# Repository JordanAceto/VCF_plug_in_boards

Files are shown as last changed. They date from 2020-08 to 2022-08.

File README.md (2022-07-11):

# Various Voltage Controlled Filter pcbs

- #### These small VCF "plug-in" boards each contain a filter "core". These are intended to be plugged into a motherboard which provides a +/- 12 volt power supply, input/output circuitry, and control voltage sources.
- #### They all share an identical mechanical and electrical format.
- #### The intended use is to make a bunch of different filters and then be able to easily try them out by swapping the filter plug-in boards into the motherboard.

## The mechanical format and pinout shared by all plug-in boards:
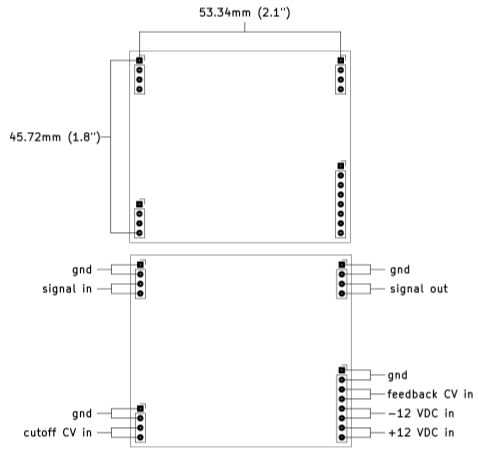
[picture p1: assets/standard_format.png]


## Signal levels:
- #### The plug-in boards are expecting modular synthesizer level signals of around +/- 5 volts.
- #### Many filters have interesting resonance and distortion characteristics that depend on signal level. Experiment with increasing and decreasing the signal levels to find the sweet spots.
- #### The output signal may or may not be in phase with the input signal.

## CV signals:
- #### The motherboard is expected to provide a 0 to +2.048 volt cutoff frequency CV signal. The plug-in boards are designed to sweep through their entire range with this range, with 0 volts mapping to the lowest cutoff frequency (usually around 20Hz) and +2.048 volts mapping to the highest cutoff frequency (usually around 20kHz).
- #### The feedback CV from the motherboard uses the same range: 0 volts of feedback CV maps to "no feedback" and +2.048 volts of feedback CV maps to maximum feedback.
- #### The CV range of 0 to +2.048 volts was chosen becuase it allows the cutoff and feedback CV signals to be conveniently driven directly from a cheap MCP4822 DAC. Don't worry about an exact 2.048 volt range, the filters have trimmers to account for variations.
- #### If different scalings are desired it is usually fairly trivial to change some resistor values in the CV scaling circuits on the plug-in boards.

## Feedback considerations:
- #### The plug-in boards all have voltage controlled feedback. This makes it easier to swap them in and out of a motherboard without worrying about the type and value of feedback potentiometer.
- #### This also makes it easier to apply "Q-compensation" to 4-pole low pass filters that suffer from passband attenuation when feedback is increased.
- #### All 4-pole filters have some form of Q-compensation built in. The builder can usually adjust the amount of compensation, or choose no compensation at all by changing a single resistor.

## Calibration:
- #### Each plug-in board has calibration trimpots for modulation depth, center frequency, and feedback sensitivity.
- #### For filters that can track at 1 volt per octave, they can probably be trimmed to play in tune over a limited range, but the trimming may be fiddly. Emphasis has been placed on getting a nice sweep through the filters useful range, and not accurate tuning or temperature compensation.
- #### Calibration is a matter of taste, and any setup that sounds good to you is correct.
- #### Here is how I calibrate Low Pass Filters:
    1. Inject a 30Hz square wave onto the signal input while monitoring the signal output.
    2. Turn the cutoff CV and feedback CV signals all the way down (set them to zero volts).
    3. Adjust the **center** trim so that the signal just dissapears.
    4. Remove the signal input.
    5. Turn the cutoff CV to around 1/2 way up and turn the feedback CV all the way up.
    6. Adjust the **feedback** trim until self oscillation occurs.
    7. Turn the cutoff CV signal all the way up.
    8. Adjust the **depth** trim until the frequency of the self oscillation is around 20kHz.
    9. Sweep the cutoff frequency up and down and readjust the **feedback** trim as needed to get reliable self oscillation over the desired range. Note that some filters will not self oscillate over their whole frequency range.
    10. Now reinject the signal and listen to the filter while changing the cutoff and feedack CV signals. Readjust the trimmers to taste if desired.

- #### I use a similar strategy for other filter topologies like Phase Shifters. Without a self oscillation signal or a strong sense of "cutoff frequency", just adjust the trimmers so that the filter has a nice sweep and the feedback control feels good.
- #### The above calibration strategy is very quick and easy once you've done it a few times.

## Power supply considerations:
- #### The motherboard is expected to provide a +/-12 volt DC power supply.
- #### Current draw varies across the filter boards from a handfull of milliamps to a few 10's of milliamps.
- #### Ensure that the motherboard can supply at least 100mA or so on each rail.

## Starting new plug-in board pcbs:
- #### A template is provided to make it easy to start new plug-in board filters.
- #### This template contains a standard directory structure, and the start of a kicad project.
- #### The template kicad docs have the skeleton of the schematic and pcb.

## Project structure:
- #### Each filter plug-in board subdirectory follows a consistent structure:
    - #### `kicad_docs/` contains the files needed to open and edit the filter schematic and pcb layout using kicad.
    - #### `construction_docs/` contains a pdf copy of the schematic, an interactive BOM which can be opened in a web browser, and gerbers.
    - #### `pics/` contains a few rendered pics of the pcb.
- #### Basically, if you want to edit the filter go into `kicad_docs/`, if you want to build the filter go into `construction_docs/`.
- #### Note that the filters may be a work in progress and may not contain complete documentation until they are done.
- #### See the board status checklist below, any board that is not checked all the way across is likely to contain errors. Boards that are all checked all the way across are safe to build.

## Status of the boards:

Board | breadboarded | schematic | pcb layout | built and tested | documentation
------|--------------|-----------|------------|------------------|---------------
[2164 phasor](https://github.com/JordanAceto/VCF_plug_in_boards/tree/master/2164_phasor_plug_in_board)       | &#9745; | &#9745; | &#9745; | &#9745; | &#9745;
[2164 LPF](https://github.com/JordanAceto/VCF_plug_in_boards/tree/master/2164_4_pole_LPF_plug_in_board)       | &#9745; | &#9745; | &#9745; | &#9745; | &#9745;
[2164 SVF](https://github.com/JordanAceto/VCF_plug_in_boards/tree/master/2164_SVF_plug_in_board)       | &#9745; | &#9745; | &#9745; | &#9745; | &#9745;
[arp 4072 LPF](https://github.com/JordanAceto/VCF_plug_in_boards/tree/master/arp_4072_LPF_plug_in_board)      | &#9745; | &#9745; | &#9745; | &#9745; | &#9745;
[CEM3320 LPF](https://github.com/JordanAceto/VCF_plug_in_boards/tree/master/CEM3320_LPF_plug_in_board)       | &#9745; | &#9745; | &#9745; | &#9745; | &#9745;
[haible 2040 LPF](https://github.com/JordanAceto/VCF_plug_in_boards/tree/master/haible_2040_LPF_plug_in_board)   | &#9745; | &#9744; | &#9744; | &#9744; | &#9744;
[haible tau phasor](https://github.com/JordanAceto/VCF_plug_in_boards/tree/master/haible_tau_phaser_plug_in_board/kicad_docs) | &#9744; | &#9744; | &#9744; | &#9744; | &#9744;
[Late MS20 VCF](https://github.com/JordanAceto/VCF_plug_in_boards/tree/master/late_MS20_VCF_plug_in_board)       | &#9745; | &#9745; | &#9745; | &#9745; | &#9745;
[minimoog LPF](https://github.com/JordanAceto/VCF_plug_in_boards/tree/master/minimoog_LPF_plug_in_board)      | &#9745; | &#9745; | &#9745; | &#9745; | &#9745;
[mutron 3 SVF](https://github.com/JordanAceto/VCF_plug_in_boards/tree/master/mutron_III_plug_in_board)      | &#9745; | &#9745; | &#9745; | &#9745; | &#9745;
[optical phasor](https://github.com/JordanAceto/VCF_plug_in_boards/tree/master/optical_phasor_plug_in_board)    | &#9745; | &#9745; | &#9745; | &#9745; | &#9745;
[SSI2140 LPF](https://github.com/JordanAceto/VCF_plug_in_boards/tree/master/SSI2140_LPF_plug_in_board) | &#9745; | &#9745; | &#9745; | &#9745; | &#9745;

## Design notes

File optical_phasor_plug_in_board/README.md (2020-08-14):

# Optical Phasor Plug-In Board

Small 6 stage optical phase shifter PCB, designed to plug into a larger motherboard.

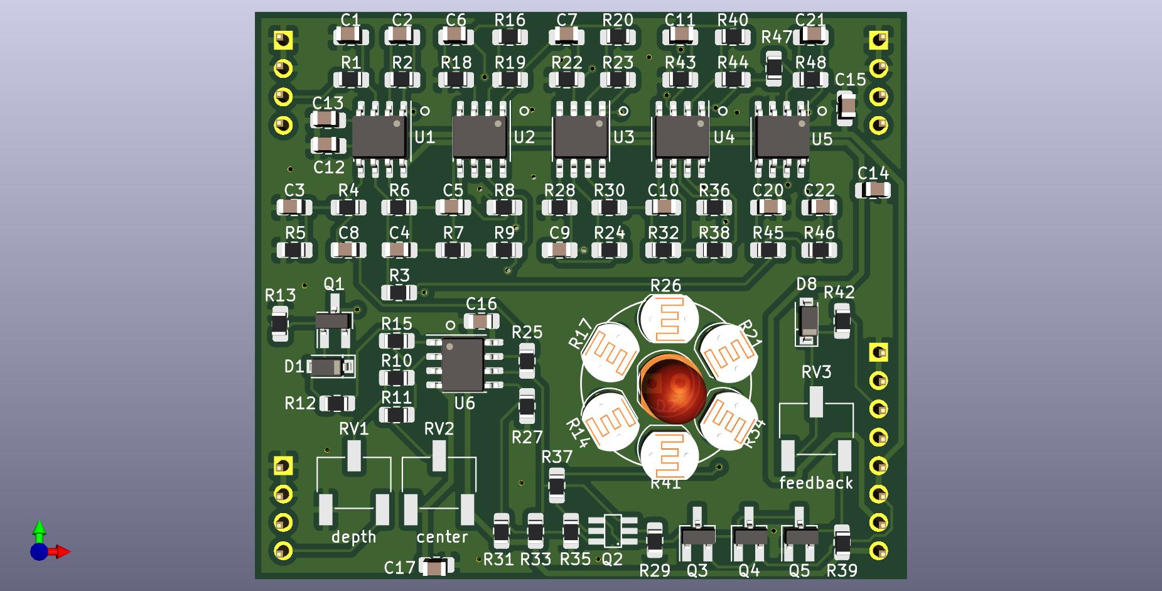
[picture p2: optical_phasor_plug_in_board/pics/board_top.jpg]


## Details

The main circuit is based on the famous Mutron phasor circuit with the addition of voltage controlled feedback. This PCB includes the audio path and CV inputs for frequency and feedback, but does not include any modulation sources.

The intended use for this board is to plug in to a larger motherboard which contains slots for one or more of these phasor boards, as well as modulation sources, panel controls, and input/output routing.

## Inputs

-Audio in: dry audio input to be phase shifted.

-Frequency CV in: 0 volts to +2.048 volts, higher voltage = higher sweep.

-Feedback CV in: 0 volts to +2.048 volts, higher voltage = more feedback.

## Outputs

-Audio out: phase shifted audio output.

## Power Supply Requirements

A bipolar 12 volt power supply capable of supplying 50mA is needed. This will typically come from the motherboard.

## Note About The Light Dependent Resistors

Low on resistance and high off resistance are desirable if a wide sweep range is wanted. Slow/fast response is up to personal taste.

The choice of LED has a large impact on sweep depth. Diffused green LEDs were found to produce good results, but feel free to experiment.

The LED and surrounding LDRs should be protected from ambient light under an opaque cover.

## Calibration

- See the top level README for calibration instructions.

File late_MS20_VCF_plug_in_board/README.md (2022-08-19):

# Late MS20 style VCF Plug-In Board

Small MS20 based low pass/high pass filter PCB, designed to plug into a larger motherboard.

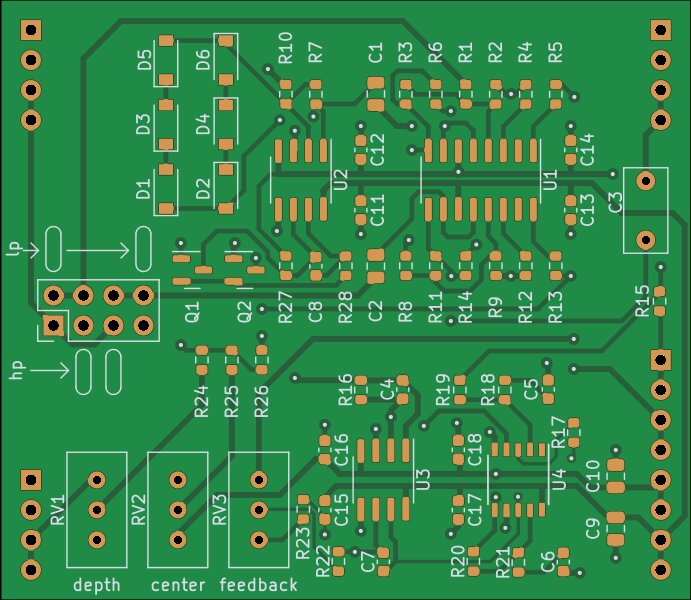
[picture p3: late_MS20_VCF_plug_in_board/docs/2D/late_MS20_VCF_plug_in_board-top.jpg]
pcb front


## Details

MS20 based LPF/HPF with voltage controlled feedback. This PCB includes the audio path and CV inputs for frequency and feedback, but does not include any modulation sources.

The intended use for this board is to plug in to a larger motherboard which contains slots for one or more of these plug-in boards, as well as modulation sources, panel controls, and input/output routing.

High pass or Low pass mode is selected by placing two jumpers as indicated on the silkscreen.

## Inputs

-Audio in: dry audio input to be filtered.

-Frequency CV in: 0 volts to +2.048 volts, higher voltage = higher sweep.

-Feedback CV in: 0 volts to +2.048 volts, higher voltage = more feedback.

## Outputs

-Audio out: filtered audio output.

## Filter mode selection

- This filter has two filter modes available: Low Pass and High Pass.

- One mode at a time can be selected by placing two jumpers according to the silkscreen.

## Power Supply Requirements

A bipolar 12 volt power supply is required. This will typically come from the motherboard.

## Calibration

- See the top level README for calibration instructions.

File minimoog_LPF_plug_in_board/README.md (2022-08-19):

# Minimoog VCF Plug-In Board

Small Minimoog based low pass filter PCB, designed to plug into a larger motherboard.

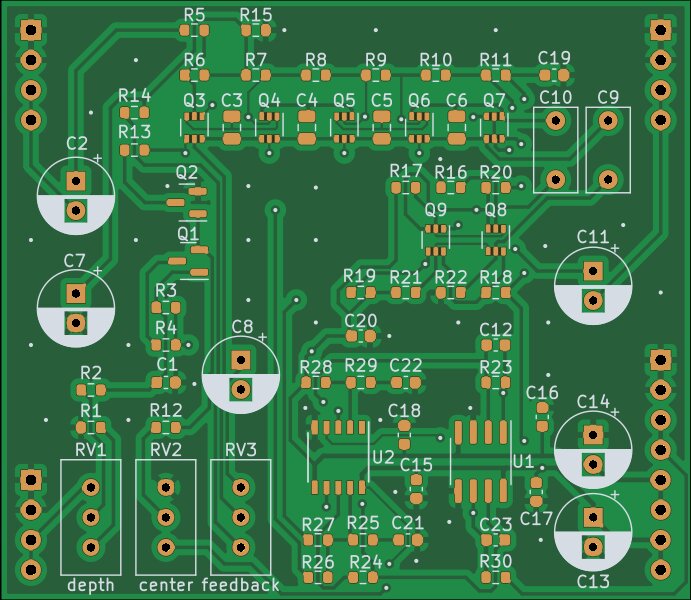
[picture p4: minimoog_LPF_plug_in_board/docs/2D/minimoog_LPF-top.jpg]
pcb front


## Details

Minimoog based LPF with Q compensation. This PCB includes the audio path and CV inputs for frequency and feedback, but does not include any modulation sources.

The intended use for this board is to plug in to a larger motherboard which contains slots for one or more of these plug-in boards, as well as modulation sources, panel controls, and input/output routing.

The Q compensation circuit keeps the passband gain from dropping too much when feedback is increased as typically happens with this type of filter. This is a matter of taste. The amount of compensation is set by R28. R28 can be increased to reduce the amount of compensation, resulting in lower passband gain at high feedback settings if a more traditional response is desired.

## Inputs

-Audio in: dry audio input to be filtered.

-Frequency CV in: 0 volts to +2.048 volts, higher voltage = higher sweep.

-Feedback CV in: 0 volts to +2.048 volts, higher voltage = more feedback.

## Outputs

-Audio out: filtered audio output.

## Power Supply Requirements

A bipolar 12 volt power supply is required. This will typically come from the motherboard.

## Calibration

- See the top level README for calibration instructions.

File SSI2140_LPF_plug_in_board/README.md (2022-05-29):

## SSI2140 4-pole Low Pass Filter plug-in board

Small SSI2140 based low pass filter PCB, designed to plug into a larger motherboard.

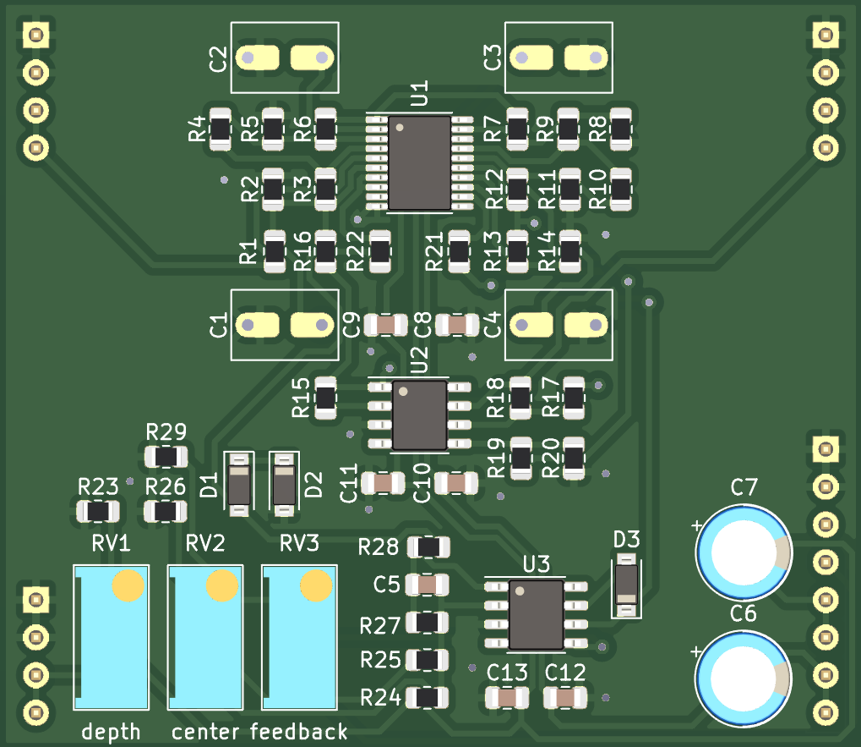
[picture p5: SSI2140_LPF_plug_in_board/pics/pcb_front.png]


## Details

Basic datasheet implementation of the SSI2140 lowpass filter with "Output Gain" Q Compensation.

## Inputs

-Audio in: dry audio input to be filtered.

-Frequency CV in: 0 volts to +2.048 volts, higher voltage = higher sweep.

-Feedback CV in: 0 volts to +2.048 volts, higher voltage = more feedback.

## Outputs

-Audio out: filtered audio output.

## Power Supply Requirements

A bipolar 12 volt power supply is required. This will typically come from the motherboard.

## Calibration

-RV1 (depth trim): trims the depth of incoming frequency CV signals. Turn CW for greater depth and CCW for less depth. Adjust to taste.

-RV2 (center trim): trims the center frequency of the filter. Turn CW for higher center frequency and CCW for lower center frequency. Adjust to taste.

-RV3 (feedback trim): trims the maximum amount of feedback. Turn CW for more maximum feedback and CCW for less maximum feedback. Exercise caution when adjusting this, as extreme settings can result in loud oscillations which could damage your ears or speakers if you are monitoring the sound with a loud amplifier. If you set this trimmer to be right on the edge of oscillation when about +2 volts is applied to the feedback CV input then make sure to sweep the frequency through its entire range, as a setting that doesn't squeal at certain frequency settings may squeal at other settings.

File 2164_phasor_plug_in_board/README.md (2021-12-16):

# 2164 Phasor Plug-In Board

Small 6 stage SSM2164 based phase shifter PCB, designed to plug into a larger motherboard.

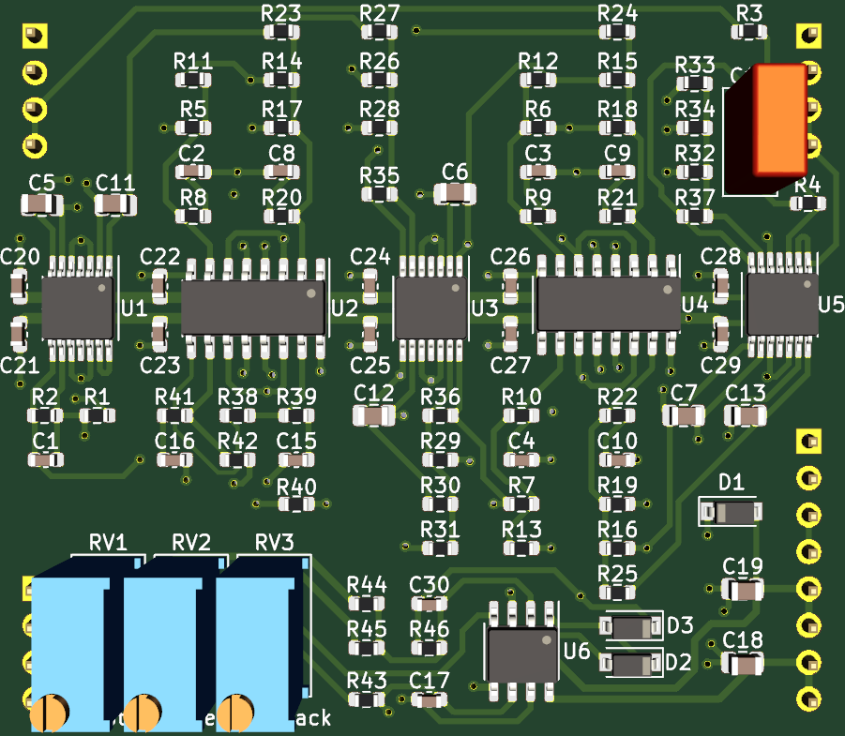
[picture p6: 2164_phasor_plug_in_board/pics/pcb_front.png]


## Details

Six stage phase shifter implemented with SSI2164 quad VCAs.

Voltage controlled feedback is provided, consistent with the other filter plug-in boards.

Construction documents for the low cost pcb assembly service from JLCPCB are included. A few parts are not included in the assembly documents, such as the through hole components, the SSI2164 chips, and also the 220pf timing capacitors for the filter stages. These are left to the builder to install. These should be good quality C0G/NP0 0805 capacitors with 2% or better tolerance.

## Inputs

-Audio in: dry audio input to be phase shifted.

-Frequency CV in: 0 volts to +2.048 volts, higher voltage = higher sweep.

-Feedback CV in: 0 volts to +2.048 volts, higher voltage = more feedback.

## Outputs

-Audio out: phase shifted audio output.

## Power Supply Requirements

A bipolar 12 volt power supply is needed. This will typically come from the motherboard.

## Calibration

- See the top level README for calibration instructions.

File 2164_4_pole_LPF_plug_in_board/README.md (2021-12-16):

## SSI2164 4-pole Low Pass Filter plug-in board

Small SSI2164 based low pass filter PCB, designed to plug into a larger motherboard.

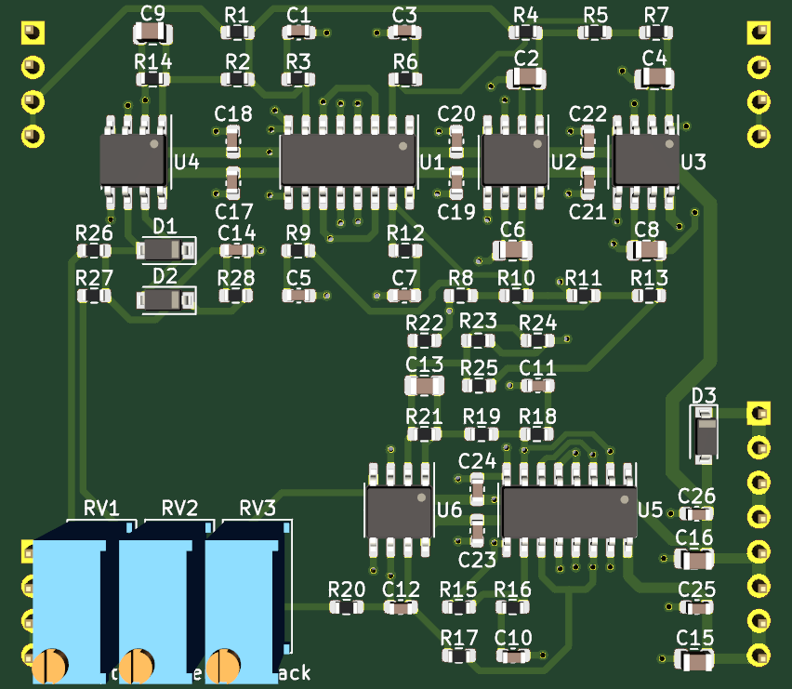
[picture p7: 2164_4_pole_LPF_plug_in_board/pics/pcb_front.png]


## Details

This pcb uses the 4-pole band-pass feedback as a means of Q-compensation as outlined in application note AN701.

Voltage controlled feedback is provided, consistent with the other filter plug-in boards.

Construction documents for the low cost pcb assembly service from JLCPCB are included. A few parts are not included in the assembly documents, such as the through hole components, the SSI2164 chips, and also the 220pf timing capacitors for the filter stages. These are left to the builder to install. These should be good quality C0G/NP0 0805 capacitors with 2% or better tolerance.

There are also footprints for optional capacitors across the feedback amplifier gain setting resistors (C9 and C13). Placing small value capacitors here can tame excessive feedback at high frequencies, or address instability if it is observed.

## Inputs

-Audio in: dry audio input to be filtered.

-Frequency CV in: 0 volts to +2.048 volts, higher voltage = higher sweep.

-Feedback CV in: 0 volts to +2.048 volts, higher voltage = more feedback.

## Outputs

-Audio out: filtered audio output.

## Power Supply Requirements

A bipolar 12 volt power supply is required. This will typically come from the motherboard.

## Calibration

- See the top level README for calibration instructions.

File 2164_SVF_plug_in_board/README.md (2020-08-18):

# 2164 State Variable Filter Plug-In Board

Small SSM/V/SSI2164 based state variable filter PCB, designed to plug into a larger motherboard.

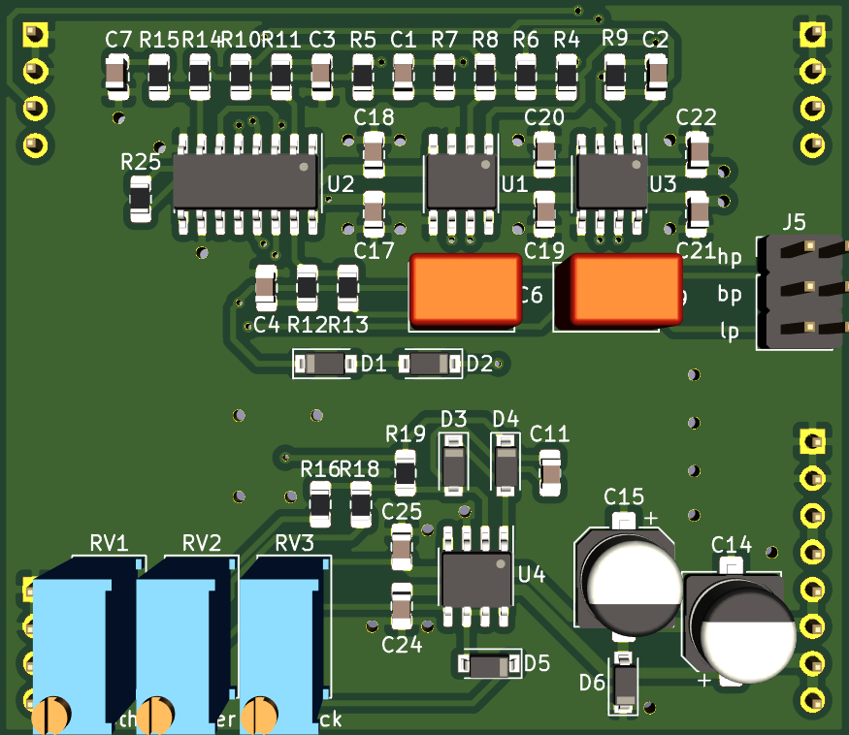
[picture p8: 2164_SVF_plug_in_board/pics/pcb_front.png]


## Details

2164 based SVF with low pass, band pass, and high pass modes available. This PCB includes the audio path and CV inputs for frequency and feedback, but does not include any modulation sources.

The intended use for this board is to plug in to a larger motherboard which contains slots for one or more of these plug-in boards, as well as modulation sources, panel controls, and input/output routing.

## Inputs

-Audio in: dry audio input to be filtered.

-Frequency CV in: 0 volts to +2.048 volts, higher voltage = higher sweep.

-Feedback CV in: 0 volts to +2.048 volts, higher voltage = more feedback.

## Outputs

-Audio out: filtered audio output.

## Filter mode selection

- This filter has three filter modes available: Low Pass, Band Pass, and High Pass.

- One mode at a time can be selected with a jumper.

## Power Supply Requirements

A bipolar 12 volt power supply is required. This will typically come from the motherboard.

## Calibration

- See the top level README for calibration instructions.

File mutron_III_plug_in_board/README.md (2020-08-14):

# Mutron-III Plug-In Board

Small Mutron-III based state variable filter PCB, designed to plug into a larger motherboard.

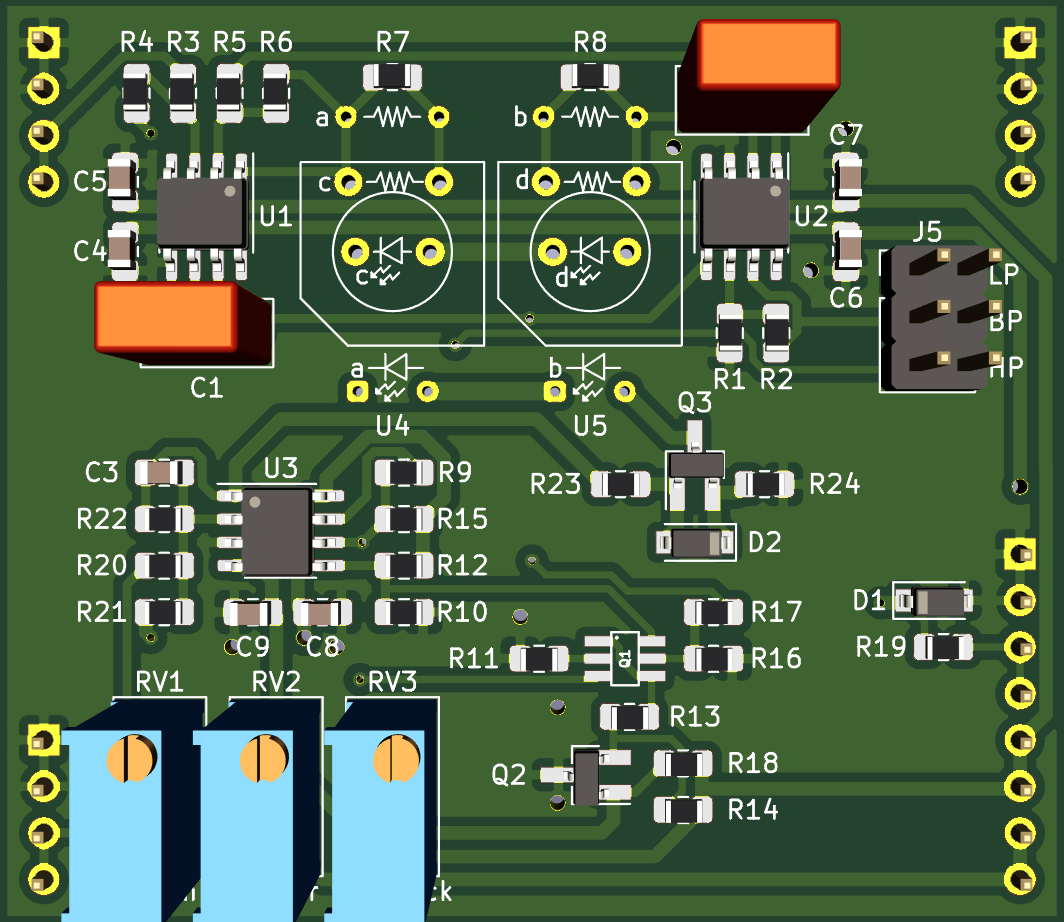
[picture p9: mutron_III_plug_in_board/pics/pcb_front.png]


## Details

Mutron-III based SVF. This PCB includes the audio path and CV inputs for frequency and feedback, but does not include any modulation sources.

The intended use for this board is to plug in to a larger motherboard which contains slots for one or more of these plug-in boards, as well as modulation sources, panel controls, and input/output routing.

## Inputs
- Audio in: dry audio input to be filtered.
- Frequency CV in: 0 volts to +2.048 volts, higher voltage = higher sweep.
- Feedback CV in: 0 volts to +2.048 volts, higher voltage = more feedback.

## Outputs
- Audio out: filtered audio output.

## Power Supply Requirements
- A bipolar 12 volt power supply is required. This will typically come from the motherboard.

## Filter mode selection
- This filter has three filter modes available: Low Pass, Band Pass, and High Pass.
- One mode at a time can be selected with a jumper.

## Note about the vactrols
The mutron-III uses vactrols to control the filter cutoff frequency. The exact devices used have a large impact on the sound of the filter. The footprint on the pcb can accept VTLxxx type vactrols, hand rolled vactrols, or the small cylindrical NSLxxx ones like I have a million of. Because of the wide variability of vactrols, some experimentation may be needed to get the filter to sound the way you want. With the circuit as drawn, the few types of vactrols I tried all sounded good after some calibration. Some component values may need to be changed if the vactrols used have significantly different specs to the ones I tried.

The picture below shows how to install VTLxxx type and NSLxxx type vactrols:

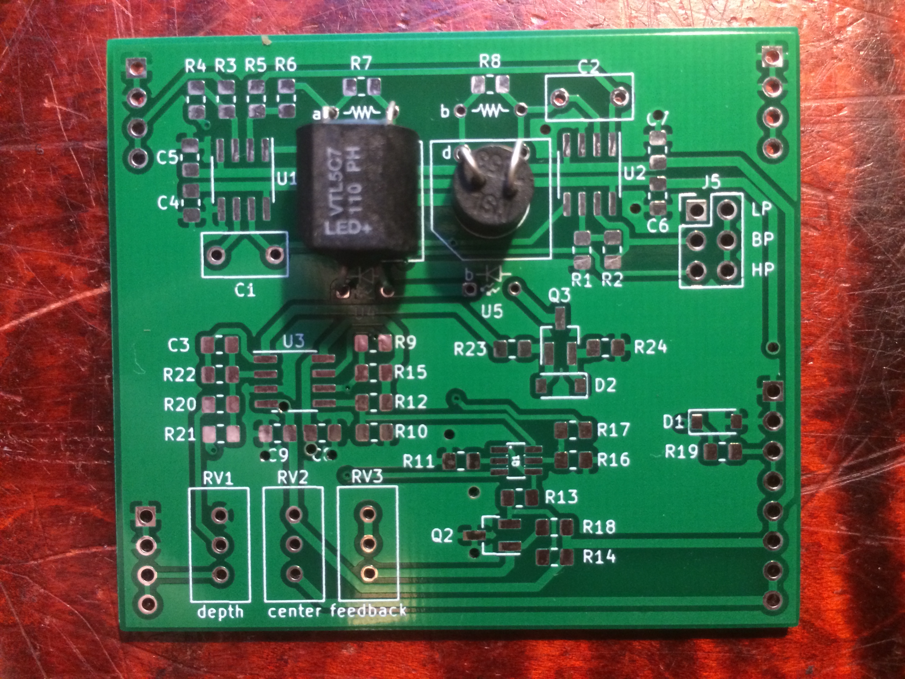
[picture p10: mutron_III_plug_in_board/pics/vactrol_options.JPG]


## Calibration

- See the top level README for calibration instructions.

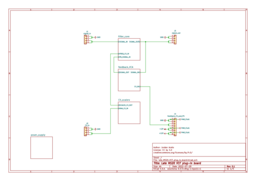
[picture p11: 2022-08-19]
late_MS20_VCF_plug_in_board/docs/html_nav/images/cat_Schematic_late_MS20_VCF_plug_in_board-schematic.png

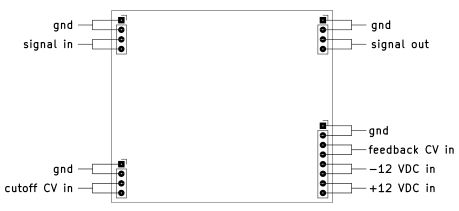
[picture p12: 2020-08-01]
assets/standard_pinout.png

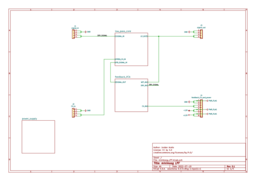
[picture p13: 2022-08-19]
minimoog_LPF_plug_in_board/docs/html_nav/images/cat_Schematic_minimoog_LPF-schematic.png

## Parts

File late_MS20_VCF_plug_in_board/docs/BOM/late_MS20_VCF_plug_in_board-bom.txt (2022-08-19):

Row	Description	Part	References	Value	Footprint	Quantity Per PCB	Status	Datasheet
1	Unpolarized capacitor	C	C4	100p	C_0603_1608Metric	1	 	~
2	Unpolarized capacitor	C	C1 C2	1n COG	C_0805_2012Metric	2	 	~
3	Unpolarized capacitor	C	C5 C6 C7	1n	C_0603_1608Metric	3	 	~
4	Unpolarized capacitor	C	C8	4n7	C_0603_1608Metric	1	 	~
5	Unpolarized capacitor	C	C11 C12 C13 C14 C15 C16 C17 C18	100n	C_0603_1608Metric	8	 	~
6	Unpolarized capacitor	C	C3	470n	C_Rect_L7.0mm_W3.5mm_P5.00mm	1	 	~
7	Unpolarized capacitor	C	C9 C10	10u	C_0805_2012Metric	2	 	~
8	75V 0.15A Fast Switching Diode, SOD-123	1N4148W	D1 D2 D3 D4 D5 D6	1N4148W	D_SOD-123	6	 	https://www.vishay.com/docs/85748/1n4148w.pdf
9	Generic connector, single row, 01x08, script generated (kicad-library-utils/schlib/autogen/connector/)	Conn_01x08	J4	feedback_CV_and_PS	PinHeader_1x08_P2.54mm_Vertical	1	 	~
10	Generic connector, double row, 02x04, odd/even pin numbering scheme (row 1 odd numbers, row 2 even numbers), script generated (kicad-library-utils/schlib/autogen/connector/)	Conn_02x04_Odd_Even	J5	hp_lp_jumper	PinHeader_2x04_P2.54mm_Vertical	1	 	~
11	Generic connector, single row, 01x04, script generated (kicad-library-utils/schlib/autogen/connector/)	Conn_01x04	J1 J2 J3	signal_in	PinHeader_1x04_P2.54mm_Vertical	3	 	~
12	-0.2A Ic, -40V Vce, Small Signal PNP Transistor, SOT-23	MMBT3906	Q1 Q2	MMBT3906	SOT-23	2	 	https://www.onsemi.com/pub/Collateral/2N3906-D.PDF
13	Resistor	R	R2 R4 R9 R12	220	R_0603_1608Metric	4	 	~
14	Resistor	R	R18 R21	270	R_0603_1608Metric	2	 	~
15	Resistor	R	R10 R26	1k8	R_0603_1608Metric	2	 	~
16	Resistor	R	R17 R23 R28	4k7	R_0603_1608Metric	3	 	~
17	Resistor	R	R1 R3 R5 R6 R7 R8 R11 R13 R14 R24	10k	R_0603_1608Metric	10	 	~
18	Resistor	R	R16 R19	15k	R_0603_1608Metric	2	 	~
19	Resistor	R	R22	51k	R_0603_1608Metric	1	 	~
20	Resistor	R	R15 R25	150k	R_0603_1608Metric	2	 	~
21	Resistor	R	R20	270k	R_0603_1608Metric	1	 	~
22	Resistor	R	R27	470k	R_0603_1608Metric	1	 	~
23	Trim-potentiometer	R_Potentiometer_Trim	RV1 RV2 RV3	5k	Potentiometer_Bourns_3296W_Vertical	3	 	~
24	Dual Operational Transconductance Amplifiers with Linearizing Diodes and Buffers, DIP-16/SOIC-16	LM13700	U1	LM13700	SOIC-16_3.9x9.9mm_P1.27mm	1	 	http://www.ti.com/lit/ds/symlink/lm13700.pdf
25		SSI2162	U4	SSI2162	SSOP-10_3.9x4.9mm_P1.00mm	1	 	https://www.soundsemiconductor.com/downloads/ssi2162datasheet.pdf
26	Dual Low-Noise JFET-Input Operational Amplifiers, DIP-8/SOIC-8	TL072	U2 U3	TL072	SOIC-8_3.9x4.9mm_P1.27mm	2	 	http://www.ti.com/lit/ds/symlink/tl071.pdf

Project info:
Schematic:	late_MS20_VCF_plug_in_board
Variant:	default
Revision:	0.1
Date:	2022-07-29
KiCad Version:	6.0.5+dfsg-1~bpo11+1
Statistics:
Component Groups:	26
Component Count:	66 (53 SMD/ 9 THT)
Fitted Components:	66 (53 SMD/ 9 THT)
Number of PCBs:	1
Total Components:	66

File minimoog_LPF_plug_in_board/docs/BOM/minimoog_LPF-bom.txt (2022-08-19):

Row	Description	Part	References	Value	Footprint	Quantity Per PCB	Status	Datasheet
1	Unpolarized capacitor	C	C12	470p	C_0603_1608Metric	1	 	~
2	Unpolarized capacitor	C	C1 C21 C22 C23	1n	C_0603_1608Metric	4	 	~
3	Unpolarized capacitor	C	C3 C4 C5 C6	22n 5%	C_0805_2012Metric	4	 	~
4	Unpolarized capacitor	C	C15 C16 C17 C18 C19 C20	100nF	C_0603_1608Metric	6	 	~
5	Unpolarized capacitor	C	C9 C10	470n	C_Rect_L7.0mm_W3.5mm_P5.00mm	2	 	~
6	Polarized capacitor	C_Polarized	C2 C8 C11 C13 C14	10u	CP_Radial_D6.3mm_P2.50mm	5	 	~
7	Polarized capacitor	C_Polarized	C7	220u	CP_Radial_D6.3mm_P2.50mm	1	 	~
8	Generic connector, single row, 01x08, script generated (kicad-library-utils/schlib/autogen/connector/)	Conn_01x08	J4	feedback_CV_and_power	PinHeader_1x08_P2.54mm_Vertical	1	 	~
9	Generic connector, single row, 01x04, script generated (kicad-library-utils/schlib/autogen/connector/)	Conn_01x04	J1 J2 J3	signal_in	PinHeader_1x04_P2.54mm_Vertical	3	 	~
10		BCM847DS135	Q3 Q4 Q5 Q6 Q7 Q8 Q9	BCM847	SOT-363_SC-70-6	7	 	
11	0.2A Ic, 40V Vce, Small Signal NPN Transistor, SOT-23	MMBT3904	Q2	MMBT3904	SOT-23	1	 	https://www.onsemi.com/pub/Collateral/2N3903-D.PDF
12	-0.2A Ic, -40V Vce, Small Signal PNP Transistor, SOT-23	MMBT3906	Q1	MMBT3906	SOT-23	1	 	https://www.onsemi.com/pub/Collateral/2N3906-D.PDF
13	Resistor	R	R7 R8 R9 R10	150	R_0603_1608Metric	4	 	~
14	Resistor	R	R1 R11 R15	220	R_0603_1608Metric	3	 	~
15	Resistor	R	R25 R29	270	R_0603_1608Metric	2	 	~
16	Resistor	R	R4 R6 R14	330	R_0603_1608Metric	3	 	~
17	Resistor	R	R13	680	R_0603_1608Metric	1	 	~
18	Resistor	R	R2	1k	R_0603_1608Metric	1	 	~
19	Resistor	R	R18 R19 R20	1k2	R_0603_1608Metric	3	 	~
20	Resistor	R	R24	4k7	R_0603_1608Metric	1	 	~
21	Resistor	R	R5	15k	R_0603_1608Metric	1	 	~
22	Resistor	R	R23 R26 R27	33k	R_0603_1608Metric	3	 	~
23	Resistor	R	R16 R22	47k	R_0603_1608Metric	2	 	~
24	Resistor	R	R30	51k	R_0603_1608Metric	1	 	~
25	Resistor	R	R12	100k	R_0603_1608Metric	1	 	~
26	Resistor	R	R3 R17 R21	220k	R_0603_1608Metric	3	 	~
27	Resistor	R	R28	270k	R_0603_1608Metric	1	 	~
28	Trim-potentiometer	R_Potentiometer_Trim	RV1 RV2 RV3	10k	Potentiometer_Bourns_3296W_Vertical	3	 	~
29		SSI2162	U2	SSI2162	SSOP-10_3.9x4.9mm_P1.00mm	1	 	https://www.soundsemiconductor.com/downloads/ssi2162datasheet.pdf
30	Dual Low-Noise JFET-Input Operational Amplifiers, DIP-8/SOIC-8	TL072	U1	TL072	SOIC-8_3.9x4.9mm_P1.27mm	1	 	http://www.ti.com/lit/ds/symlink/tl071.pdf

Project info:
Schematic:	minimoog_LPF
Variant:	default
Revision:	0.1
Date:	2022-07-19
KiCad Version:	6.0.5+dfsg-1~bpo11+1
Statistics:
Component Groups:	30
Component Count:	71 (47 SMD/ 15 THT)
Fitted Components:	71 (47 SMD/ 15 THT)
Number of PCBs:	1
Total Components:	71

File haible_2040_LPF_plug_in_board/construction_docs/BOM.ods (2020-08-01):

Reference | Quantity | Value | Footprint | Unit Price | Total Price | Product Page
Mouser Parts
C1 C5 | 2 | 10uF | Radial_D6.3mm_H11.0mm_P2.50mm | $0.45 | $0.90 | https://www.mouser.com/ProductDetail/Nichicon/UES1V100MEM
C12 C13 C14 C15 C10 C11 | 6 | 100nF | 0805 | $0.10 | $0.60 | https://www.mouser.com/ProductDetail/KEMET/C0805C104M5RACTU
C2 | 1 | 22uF | 0805 | $0.52 | $0.52 | https://www.mouser.com/ProductDetail/Taiyo-Yuden/TMK212BBJ226MG-TT
C3 | 1 | 470pF | 0805 | $0.14 | $0.14 | https://www.mouser.com/ProductDetail/Yageo/CC0805JRNPO9BN471?qs=sGAEpiMZZMs0AnBnWHyRQMMzfhmH8IQXUBKdtHCIPbI%3D
C4 C7 C8 C9 | 4 | 1nF | 0805 | $0.28 | $1.12 | https://www.mouser.com/ProductDetail/Yageo/CC0805FRNPO9BN102
C6 | 1 | 2n2 | 0805 | $0.27 | $0.27 | https://www.mouser.com/ProductDetail/Yageo/CC0805JKNPO9BN222?qs=sGAEpiMZZMs0AnBnWHyRQMMzfhmH8IQXzJfNxPelwGg%3D
J1 J2 J3 J4 | 1 | breakaway headers | 2.54mm:PinHeader | $2.78 | $2.78 | https://www.mouser.com/ProductDetail/TE-Connectivity/4-103185-0
Q3 Q8 Q12 Q16 Q2 Q1 | 6 | BCM857DS | SOT457 | $0.41 | $2.46 | https://www.mouser.com/ProductDetail/Nexperia/BCM857DS135?qs=sGAEpiMZZMvKM5ialpXrmrzXp%252BgF%2FDi0
Q4 Q6 Q9 Q10 Q13 Q14 Q17 Q18 | 8 | BCM847DS | SOT457 | $0.41 | $3.28 | https://www.mouser.com/ProductDetail/Nexperia/BCM847DS115
Q7 Q23 Q22 Q21 Q20 Q24 Q5 Q11 Q15 Q19 | 10 | BC847 | SOT-23 | $0.13 | $1.30 | https://www.mouser.com/ProductDetail/Nexperia/BC847C215
R16 | 1 | 20k | 0805 | $0.10 | $0.10 | https://www.mouser.com/ProductDetail/Bourns/CR0805-FX-2002ELF
R17 | 1 | 100 | 0805 | $0.10 | $0.10 | https://www.mouser.com/ProductDetail/Bourns/CR0805-FX-1000ELF
R18 R11 R30 R37 R44 | 5 | 120k | 0805 | $0.10 | $0.50 | https://www.mouser.com/ProductDetail/Bourns/CR0805-FX-1203ELF
R19 R12 R31 R28 R38 R35 R45 R42 | 8 | 10k | 0805 | $0.10 | $0.80 | https://www.mouser.com/ProductDetail/Bourns/CR0805-FX-1002ELF
R2 R14 R26 R1 | 4 | 1k | 0805 | $0.10 | $0.40 | https://www.mouser.com/ProductDetail/Bourns/CR0805-FX-1001ELF
R20 | 1 | 180k | 0805 | $0.10 | $0.10 | https://www.mouser.com/ProductDetail/Bourns/CR0805-FX-1803ELF
R21 R15 R10 R32 R39 R46 | 6 | 12k | 0805 | $0.10 | $0.60 | https://www.mouser.com/ProductDetail/Bourns/CR0805-FX-1202ELF
R22 R33 R40 R47 | 4 | 1k2 | 0805 | $0.10 | $0.40 | https://www.mouser.com/ProductDetail/Bourns/CR0805-FX-1201ELF
R23 | 1 | 2k2 | 0805 | $0.10 | $0.10 | https://www.mouser.com/ProductDetail/Bourns/CR0805-FX-2201ELF
R27 R4 | 2 | 100k | 0805 | $0.10 | $0.20 | https://www.mouser.com/ProductDetail/Bourns/CR0805-FX-1003ELF
R3 R24 | 2 | 51k | 0805 | $0.10 | $0.20 | https://www.mouser.com/ProductDetail/Bourns/CR0805-FX-5102ELF
R48 | 1 | 27k | 0805 | $0.10 | $0.10 | https://www.mouser.com/ProductDetail/Bourns/CR0805-FX-2702ELF
R5 R7 | 2 | 560k | 0805 | $0.10 | $0.20 | https://www.mouser.com/ProductDetail/Bourns/CR0805-FX-5603ELF
R6 R13 R25 R29 R34 R36 R41 R43 | 8 | 220 | 0805 | $0.10 | $0.80 | https://www.mouser.com/ProductDetail/Bourns/CR0805-FX-2200ELF
R8 | 1 | 3k3 | 0805 | $0.10 | $0.10 | https://www.mouser.com/ProductDetail/Bourns/CR0805-FX-3301ELF
R9 | 1 | 15k | 0805 | $0.10 | $0.10 | https://www.mouser.com/ProductDetail/Bourns/CR0805-FX-1502ELF
RV1 | 1 | 10k | Bourns_3269W | $4.83 | $4.83 | https://www.mouser.com/ProductDetail/Bourns/3269W-1-103LF?qs=sGAEpiMZZMvygUB3GLcD7lKKmqkeksZmGot4dXELruo%3D
RV2 RV3 | 2 | 100k | Bourns_3269W | $4.83 | $9.66 | https://www.mouser.com/ProductDetail/Bourns/3269W-1-104LF?qs=sGAEpiMZZMvygUB3GLcD7iPUMwpiXMBsQtXtzdbyTwg%3D
U1 U2 | 2 | TL072 | SOIC-8 | $0.59 | $1.18 | https://www.mouser.com/ProductDetail/Texas-Instruments/TL072CDR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
 |  |  | Total |  | $33.84
 |  |  | Link to Mouser project |  |  | https://www.mouser.com/ProjectManager/ProjectDetail.aspx?AccessID=2b5f0e1beb

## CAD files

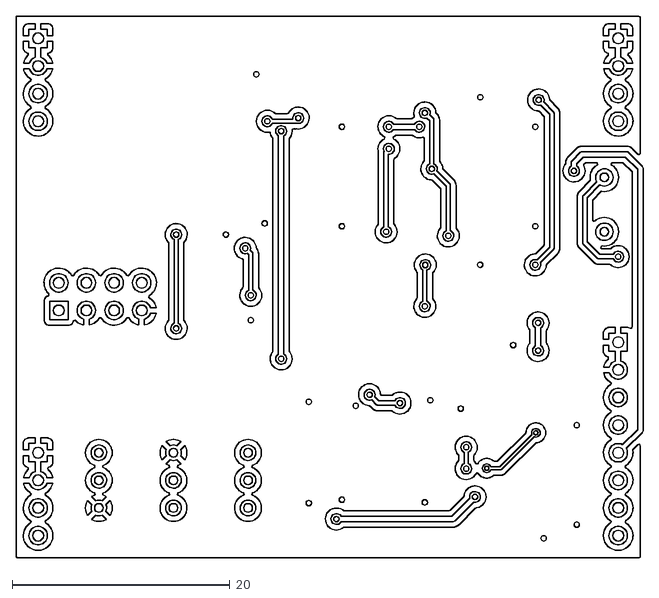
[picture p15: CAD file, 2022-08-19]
late_MS20_VCF_plug_in_board/docs/CAD/late_MS20_VCF_plug_in_board-B_Cu.dxf
57.7 x 49.8

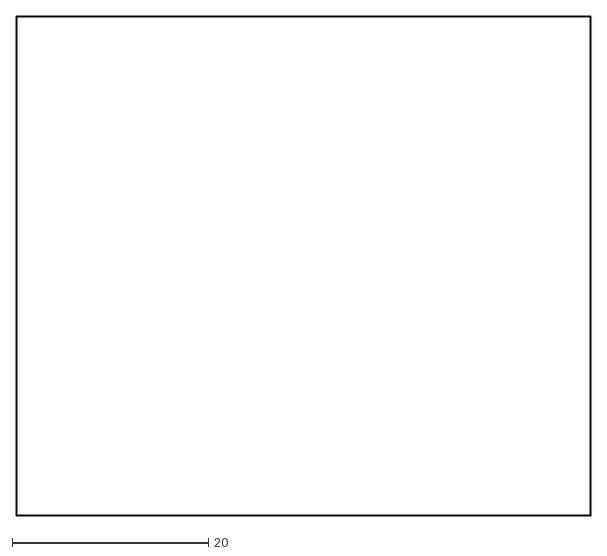
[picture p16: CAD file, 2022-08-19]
minimoog_LPF_plug_in_board/docs/CAD/minimoog_LPF-Edge_Cuts.dxf
58.5 x 50.8

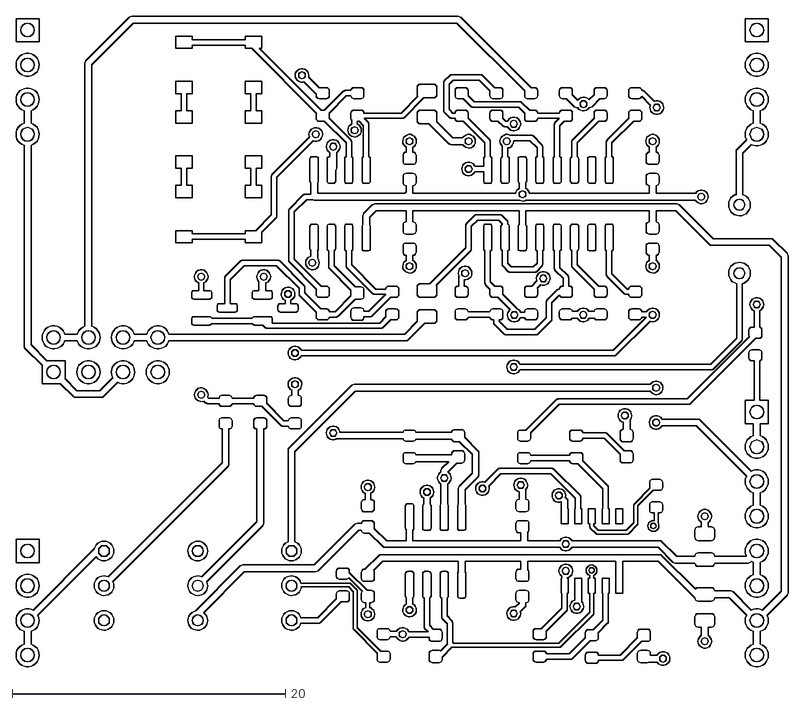
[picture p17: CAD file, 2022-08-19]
late_MS20_VCF_plug_in_board/docs/CAD/late_MS20_VCF_plug_in_board-F_Cu.dxf
56.5 x 47.6

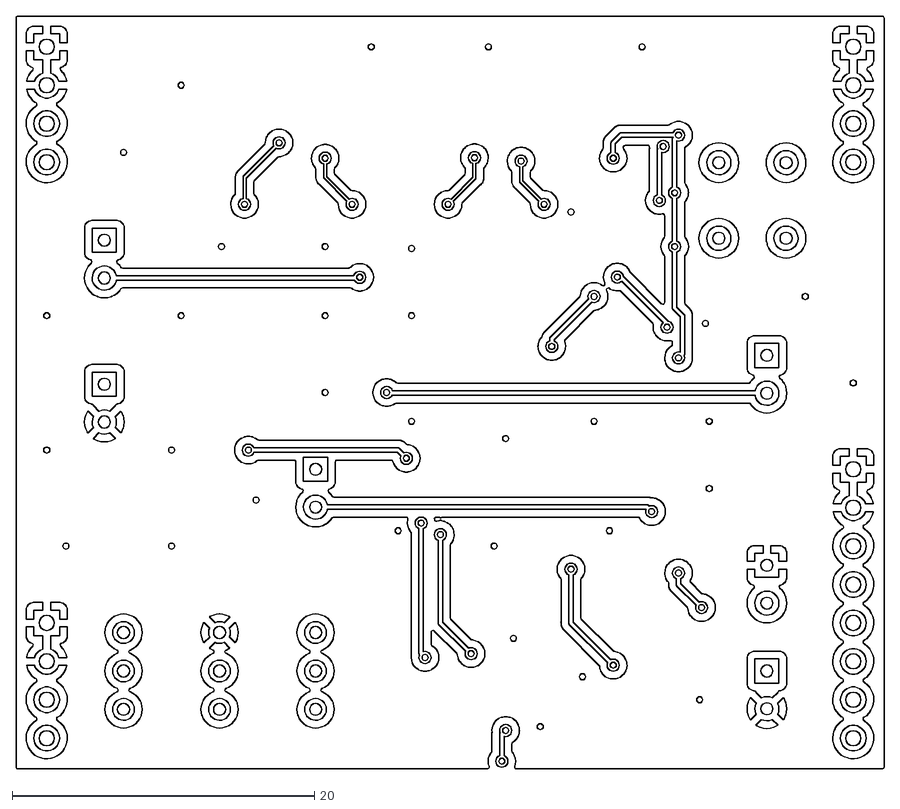
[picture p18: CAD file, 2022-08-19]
minimoog_LPF_plug_in_board/docs/CAD/minimoog_LPF-B_Cu.dxf
57.4 x 49.8

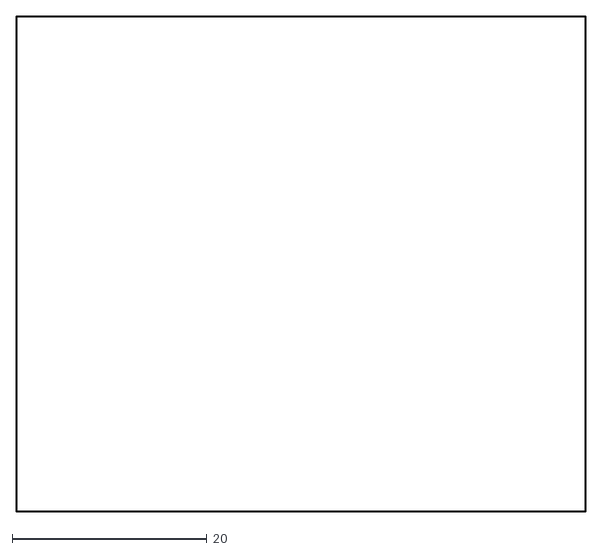
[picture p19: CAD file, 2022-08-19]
late_MS20_VCF_plug_in_board/docs/CAD/late_MS20_VCF_plug_in_board-Edge_Cuts.dxf
58.5 x 50.8

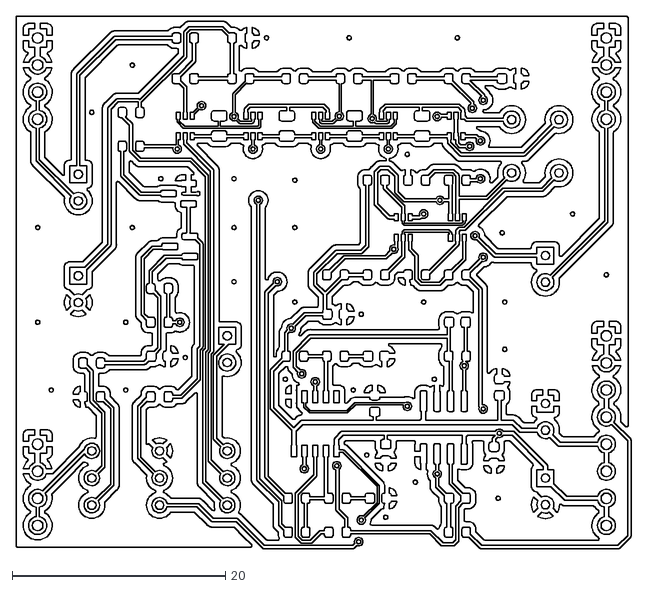
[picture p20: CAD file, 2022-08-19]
minimoog_LPF_plug_in_board/docs/CAD/minimoog_LPF-F_Cu.dxf
57.7 x 49.9

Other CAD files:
late_MS20_VCF_plug_in_board/docs/CAD/late_MS20_VCF_plug_in_board-B_Mask.dxf
late_MS20_VCF_plug_in_board/docs/CAD/late_MS20_VCF_plug_in_board-B_Silkscreen.dxf
late_MS20_VCF_plug_in_board/docs/CAD/late_MS20_VCF_plug_in_board-F_Mask.dxf
late_MS20_VCF_plug_in_board/docs/CAD/late_MS20_VCF_plug_in_board-F_Silkscreen.dxf
minimoog_LPF_plug_in_board/docs/CAD/minimoog_LPF-B_Mask.dxf
minimoog_LPF_plug_in_board/docs/CAD/minimoog_LPF-B_Silkscreen.dxf
minimoog_LPF_plug_in_board/docs/CAD/minimoog_LPF-F_Mask.dxf
minimoog_LPF_plug_in_board/docs/CAD/minimoog_LPF-F_Silkscreen.dxf

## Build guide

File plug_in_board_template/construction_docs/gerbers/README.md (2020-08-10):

Placeholder file so that the directory structure is tracked in git.

Delete this after generating files for this directory.

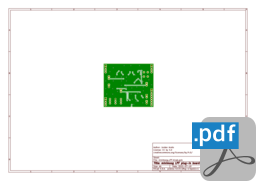
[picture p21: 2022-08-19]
minimoog_LPF_plug_in_board/docs/html_nav/images/cat_pdf_pcb_print_BCu_minimoog_LPF-B_Cu.png

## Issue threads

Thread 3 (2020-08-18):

optical phasor uses expensive trimpots

JordanAceto, 2020-08-18:
The trimpots in the optical phase shifter are an expensive surface mount package.

Consider changing these over to the cheaper bourns 3296W package, especially because with so many filter plug-in boards, it's easy to hit price breaks on trimmers if you build a few at a time.

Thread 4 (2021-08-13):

the feedback VCAs are a bit noisy

JordanAceto, 2021-08-13:
In many of the plug-in boards, I use a VCA made of transistors and an opamp. This works pretty well, but they are pretty noisy if the signal levels are small. I've been testing these with an electric guitar, and there is noticeable noise when the feedback is cranked up in most of the boards that use the feedback VCA described above. When using instruments with large signal levels such as modular synthesizers, the noise is pretty far below the signal so it isn't offensive.

Consider improving the feedback VCA design. The basic existing plan could probably be improved, or you could consider an LM13700 or SSI216x VCA designs.

IMO a linearized SSI2162 VCA might be the way to go. It probably the most expensive route, but yolo. You could also use a linearized SSI2164 VCA and parallel sections to improve SNR, if you don't want to stock both 2164 and 2162 chips. SSI2162 will save a little bit of space if the layout is tight.

JordanAceto, 2022-07-24:
The offenders are:
- Minimoog LPF
- ARP 4072 LPF
- Late MS20 VCF
- Mutron III SVF
- Optical Phasor

These are the boards that would benefit from a better feedback VCA, the rest of them are fine as-is.

JordanAceto, 2022-08-20:
I updated the minimoog and late-MS20 filters with SSI2162 feedback VCAs, see these for reference if updating boards. I also did this for the optical phasor, but I have not done a test build yet, so it remains unverified.

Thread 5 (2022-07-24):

Optical Phasor should have a light shield

JordanAceto, 2022-07-24:
On the Optical Phasor board (modeled after the Mutron II / biphase), the light dependent resistor cells must be shielded from ambient light to function properly.

On the current version I built, I used an old vanilla extract cap hot-melt glued to the pcb. This actually works pretty well, but it's no fun having to chug a bottle of vanilla extract every time you want to make a board :P

Ideally there would be a little 3D printed cap that covers the LDR ring and LED. This could snap into little holes strategically placed in the pcb, or just get hot-glued down (I like the snap-in holes idea though).

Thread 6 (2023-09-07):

A discrete CEM3320 board that doesn't need a CEM3320 would be nice.

01GOD, 2023-09-07:
Hi! Thanks for posting those! I like that mobo plugin design.

A discrete CEM3320 board that doesn't need a CEM3320 would be nice.

JordanAceto, 2023-12-02:
Hi there, just noticed this. Interesting idea. I am not familiar with any discrete CEM3320 projects, do you have any references to designs you're thinking of here?

The SSM2040 has been sort-of-reverse-engineered by Jurgen Haible a long time ago: http://jhaible.com/legacy/tonline_stuff/jh2040.gif (schem has obvious error with reversed PNP current mirrors but otherwise is ok). I started, but have not finished a version of this project. This is basically the same as the MOTM-440 with the control range scaled to my [0v, 2v] range.

I don't know of a similar effort to reverse engineer the CEM3320, and this isn't something I am going to put time into at the moment. Since afaik the CEM3320 is pretty similar internally to cascaded LM13700 OTA stages you could probably get reasonably close sound-wise with a couple LM13700s and a expo converter stage. But then you've strayed pretty far from CEM land. Digging into the guts and replacing the OTA stages with discrete BJT/FET equivalents would be a pretty big task.

In short, if you have more info about what a discrete CEM3320 might look like I'd consider giving it a shot at some point, but won't promise much. Since we can buy the Alpha CEM3320 clones cheaply right now there is not a ton of motivation to make a discrete version.

Cheers :)

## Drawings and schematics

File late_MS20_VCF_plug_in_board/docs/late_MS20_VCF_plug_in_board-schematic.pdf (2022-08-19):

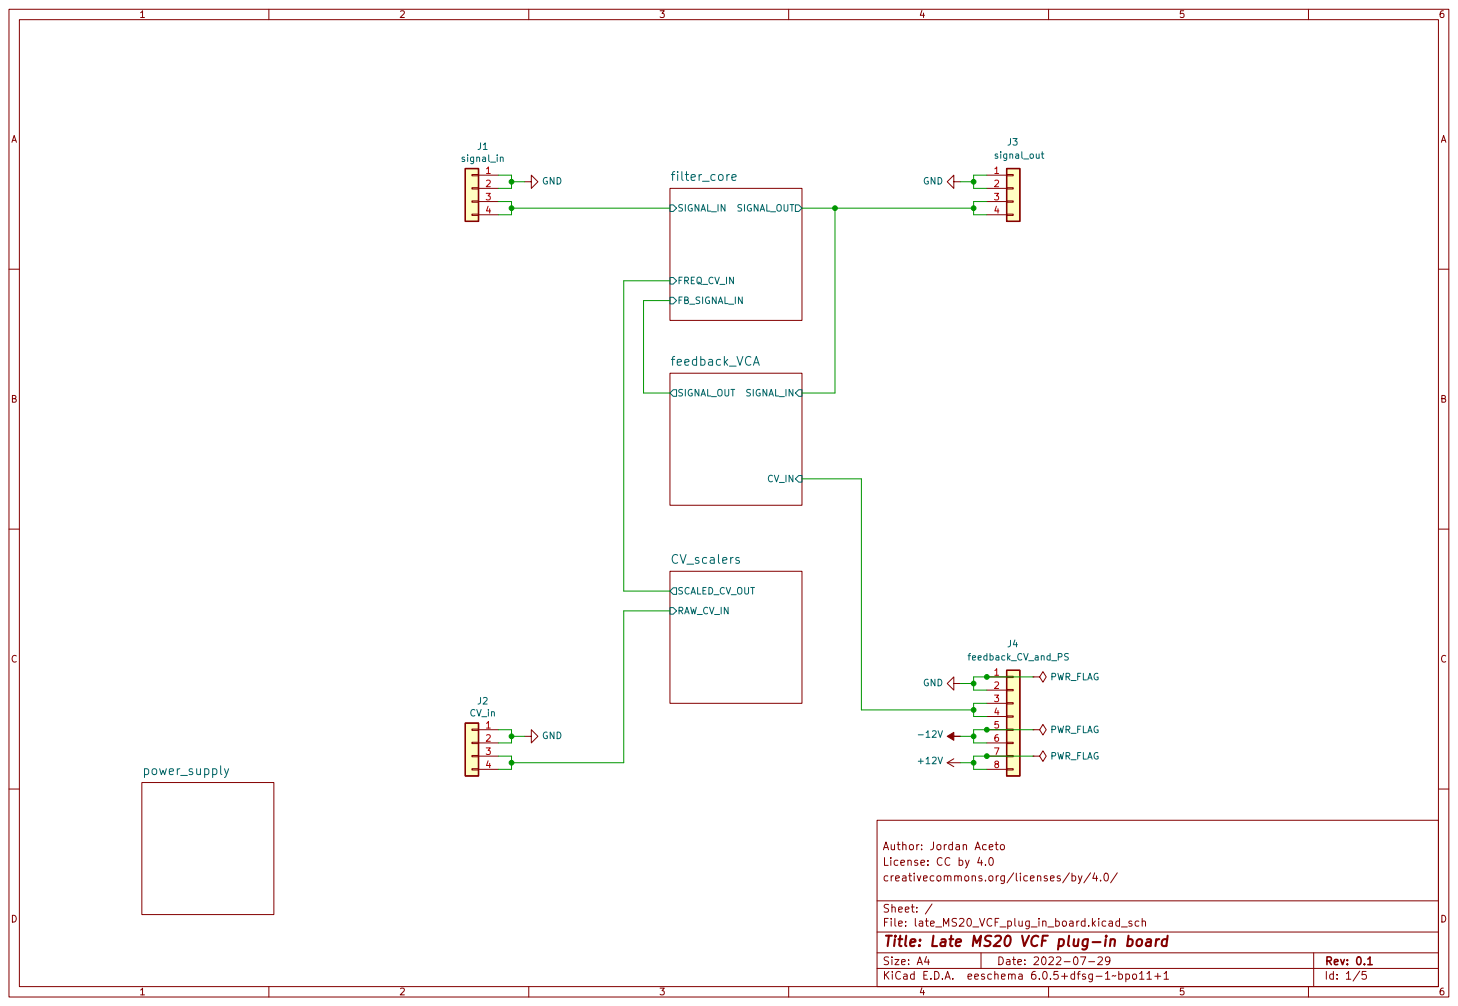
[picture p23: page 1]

License: CC by 4.0 Author: Jordan Aceto

File: late_MS20_VCF_plug_in_board.kicad_sch Sheet: / creativecommons.org/licenses/by/4.0/

Id: 1/5 Title: Late MS20 VCF plug-in board

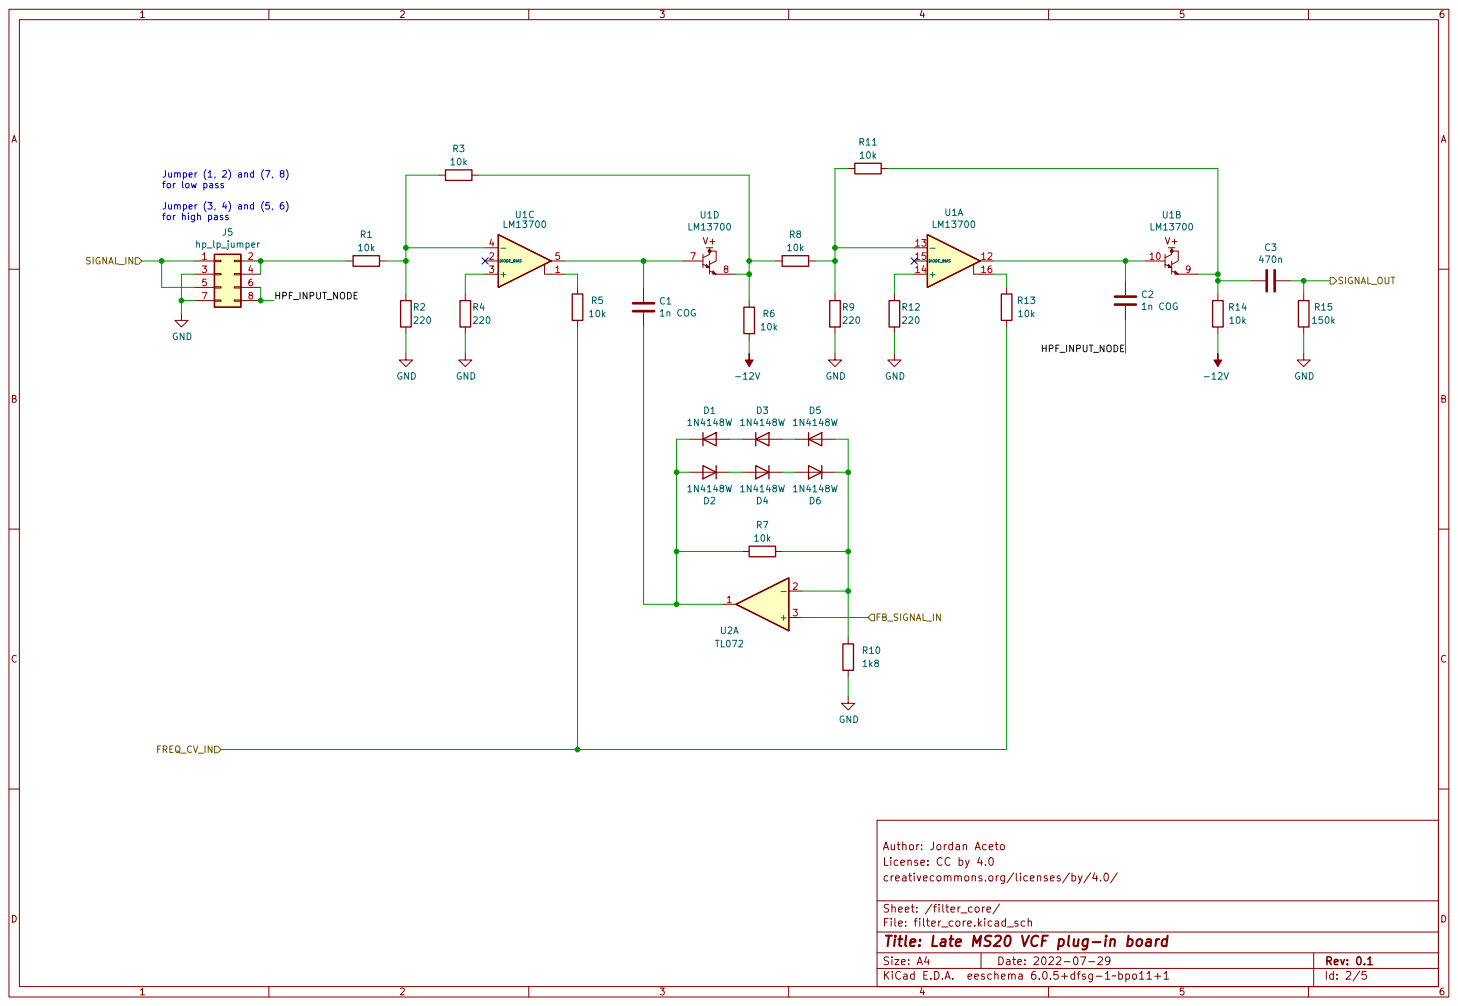
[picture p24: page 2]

License: CC by 4.0 Author: Jordan Aceto

creativecommons.org/licenses/by/4.0/

Sheet: /filter_core/
File: filter_core.kicad_sch
Id: 2/5 Title: Late MS20 VCF plug-in board

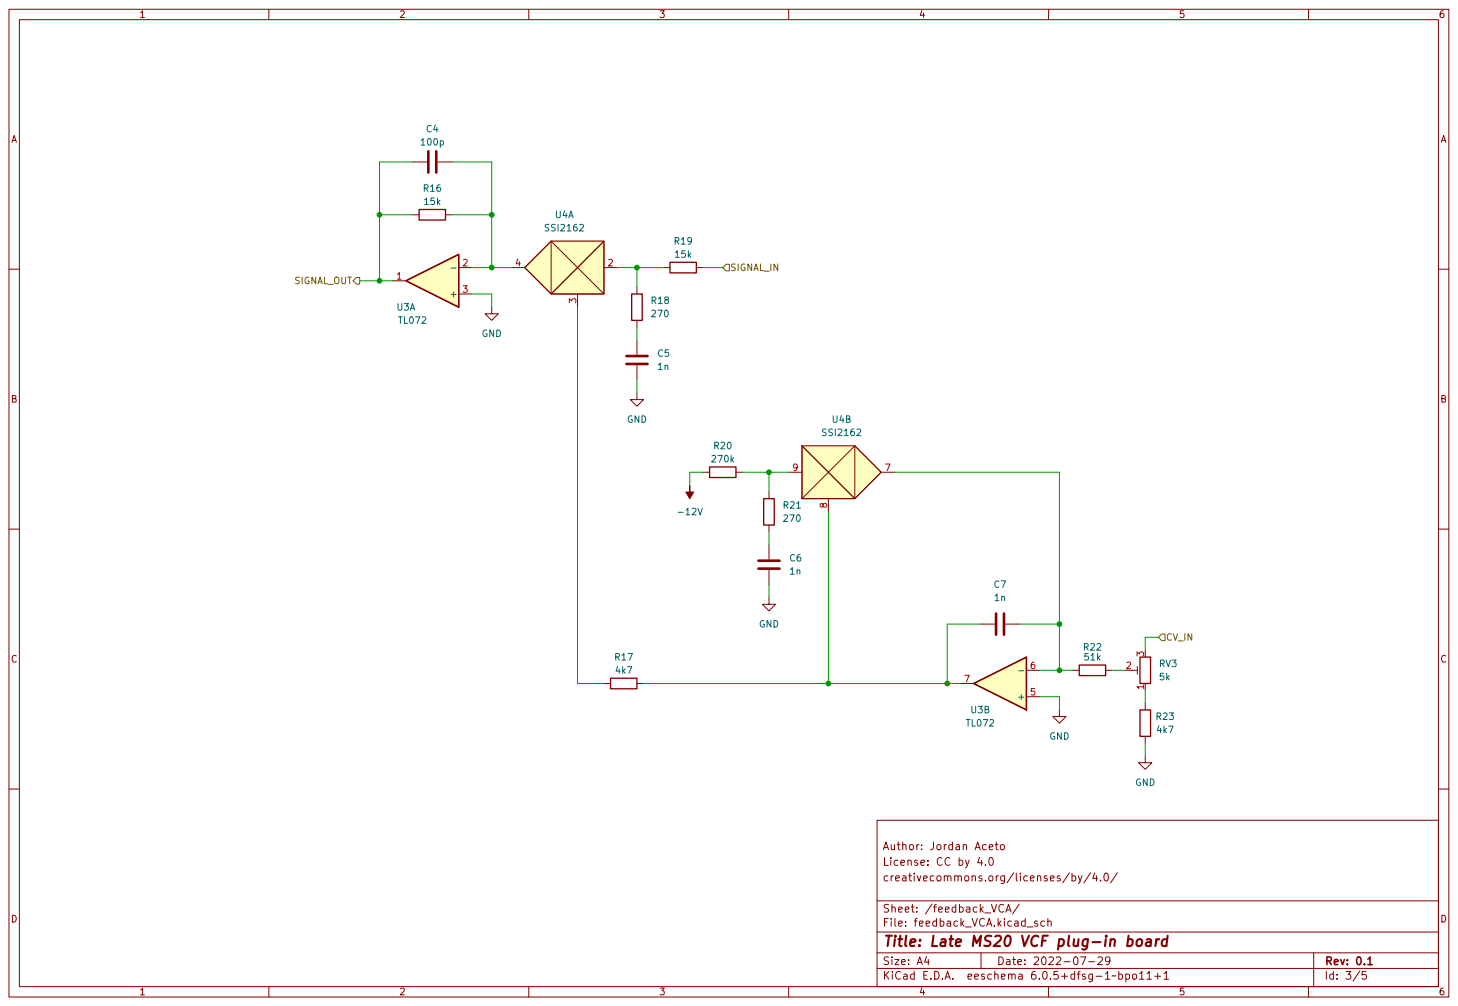
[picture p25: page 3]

creativecommons.org/licenses/by/4.0/

Sheet: /feedback_VCA/
File: feedback_VCA.kicad_sch
Id: 3/5 Title: Late MS20 VCF plug-in board

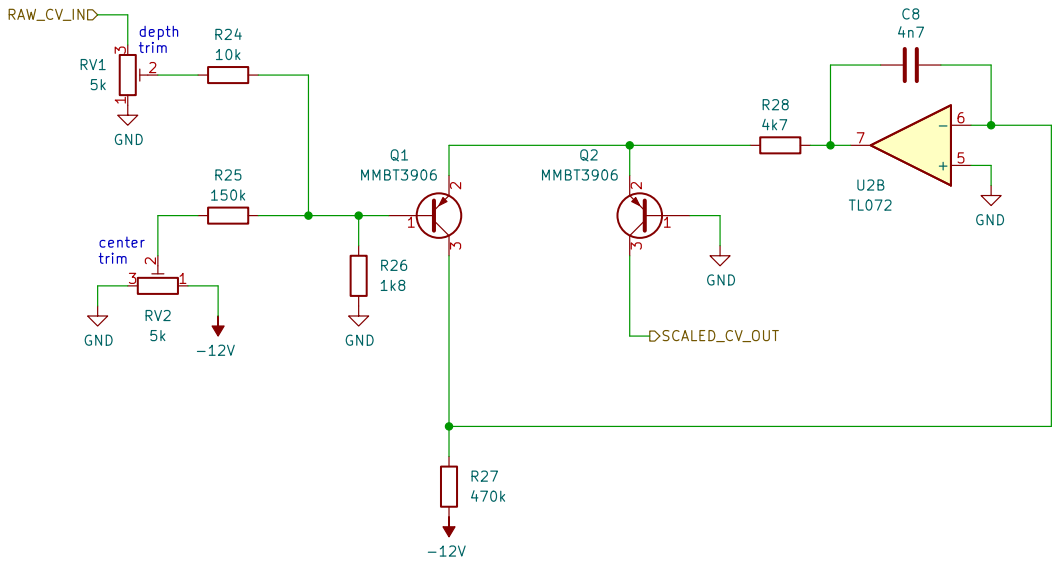
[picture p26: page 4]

License: CC by 4.0 Author: Jordan Aceto

creativecommons.org/licenses/by/4.0/

Sheet: /CV_scalers/
File: CV_scalers.kicad_sch
Id: 4/5 Title: Late MS20 VCF plug-in board

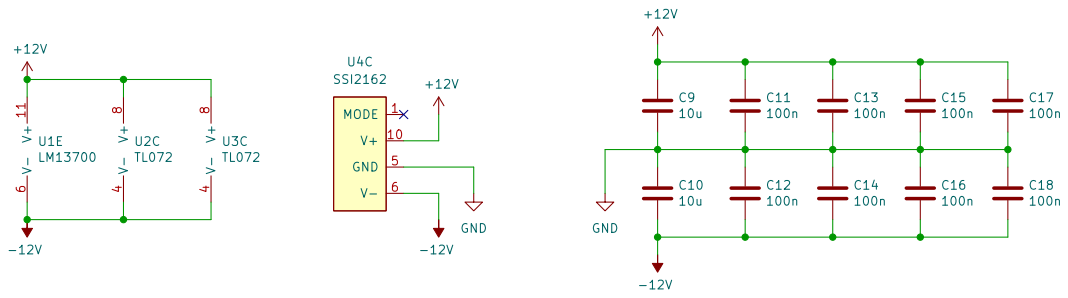
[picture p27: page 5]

License: CC by 4.0 Author: Jordan Aceto

creativecommons.org/licenses/by/4.0/

Sheet: /power_supply/
File: power_supply.kicad_sch
Id: 5/5 Title: Late MS20 VCF plug-in board

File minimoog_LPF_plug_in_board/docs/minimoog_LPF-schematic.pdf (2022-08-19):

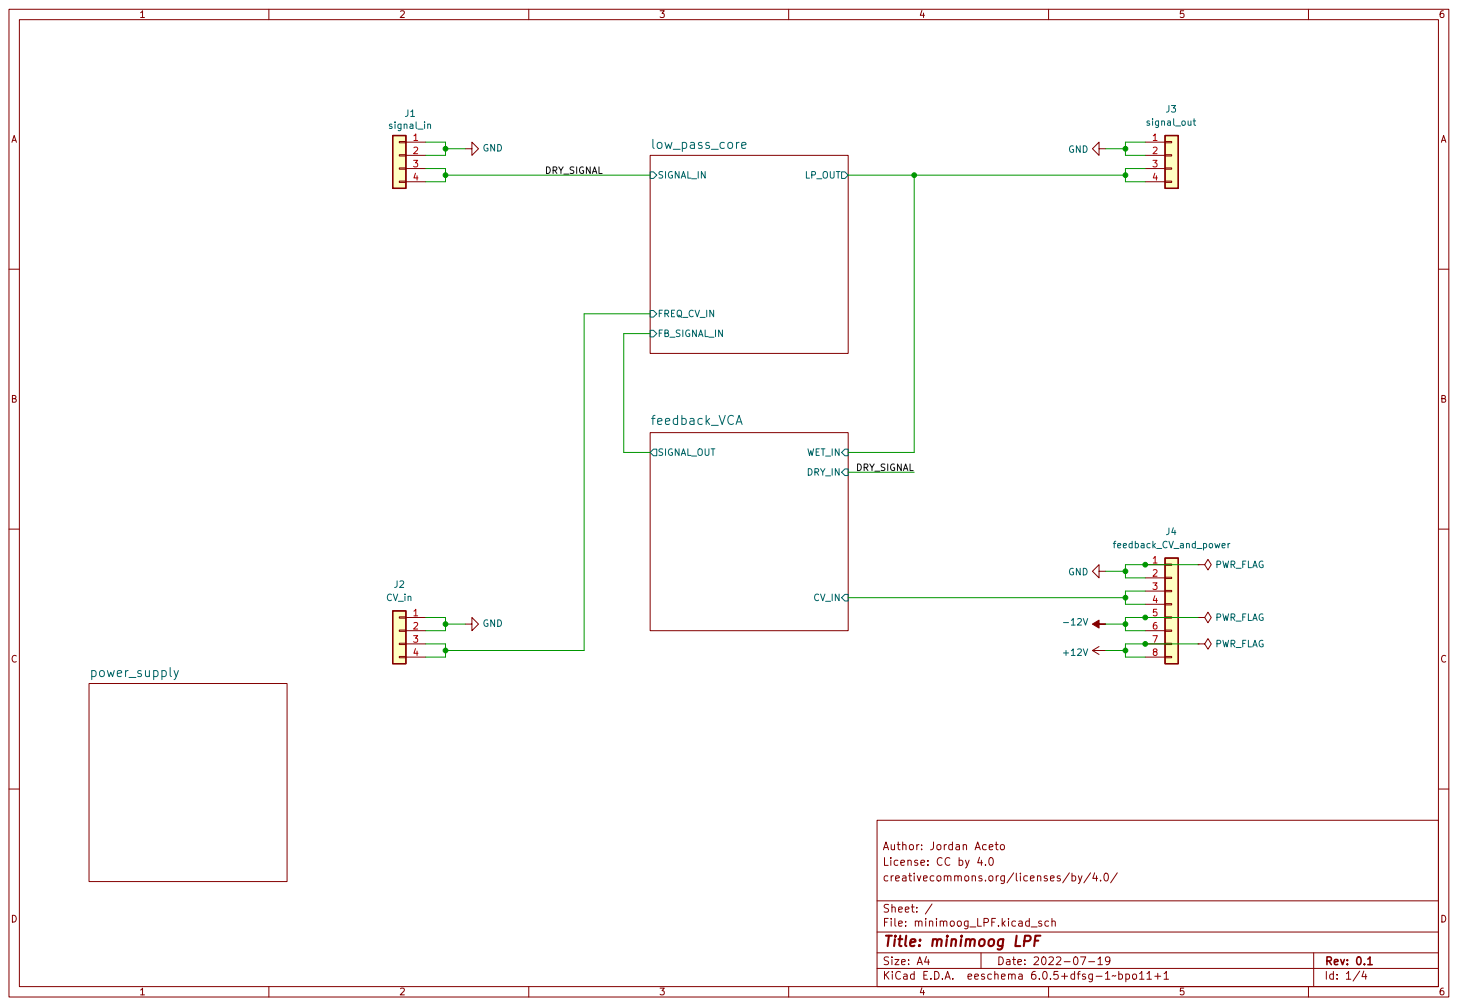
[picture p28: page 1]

License: CC by 4.0 Author: Jordan Aceto power_supply

File: minimoog_LPF.kicad_sch Sheet: / creativecommons.org/licenses/by/4.0/

Id: 1/4 Title: minimoog LPF

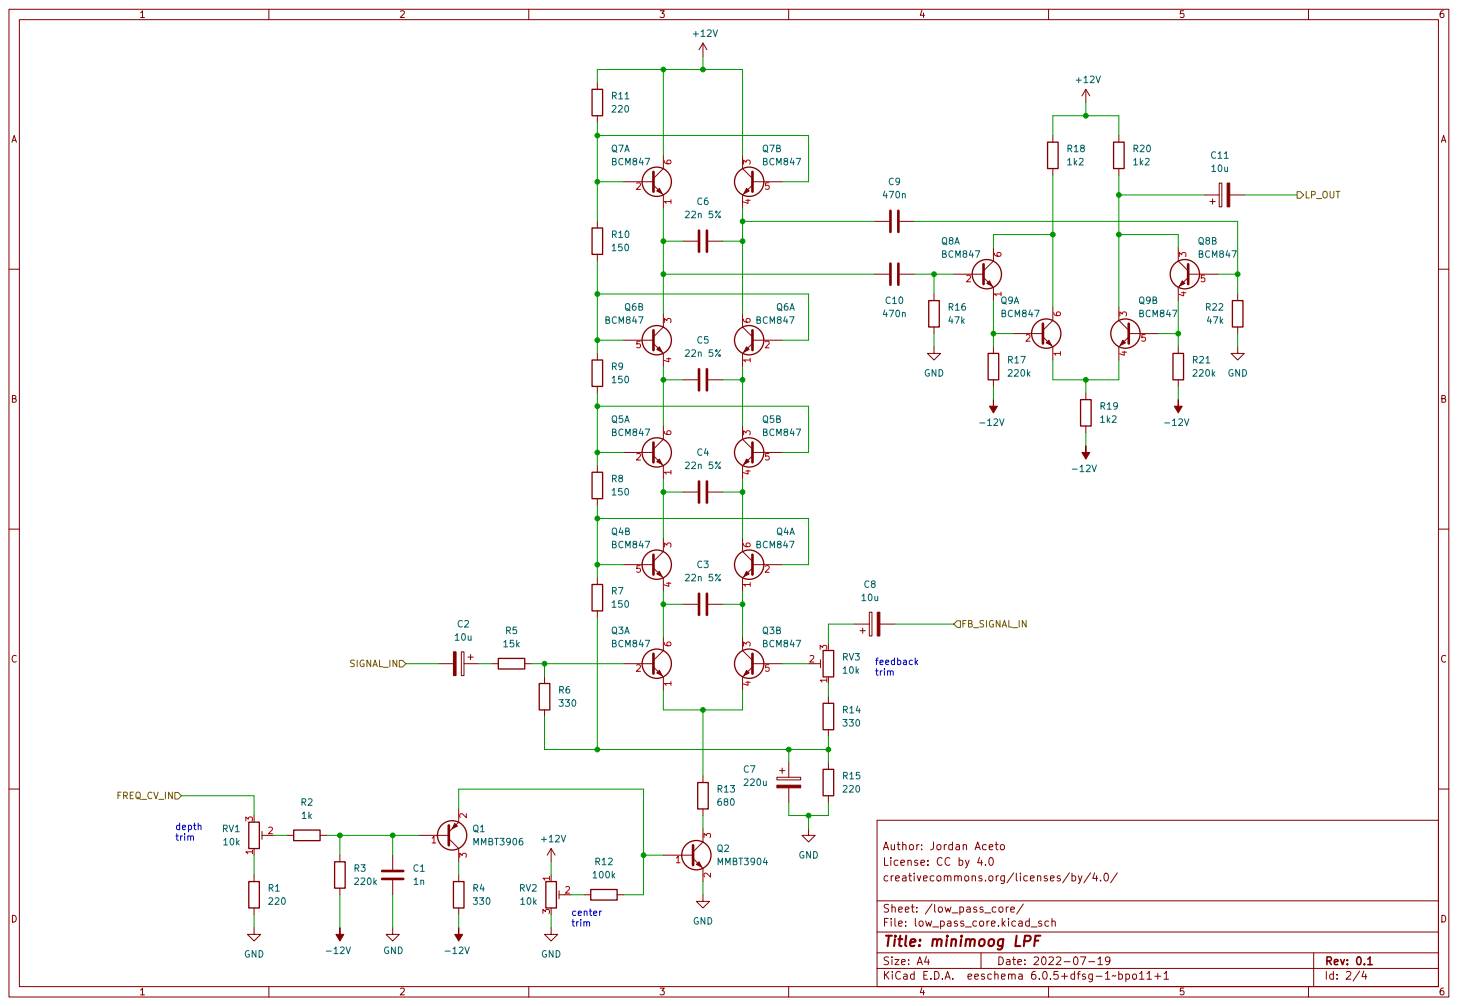
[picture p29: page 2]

License: CC by 4.0 Author: Jordan Aceto R4

creativecommons.org/licenses/by/4.0/

Sheet: /low_pass_core/
File: low_pass_core.kicad_sch
Id: 2/4 Title: minimoog LPF

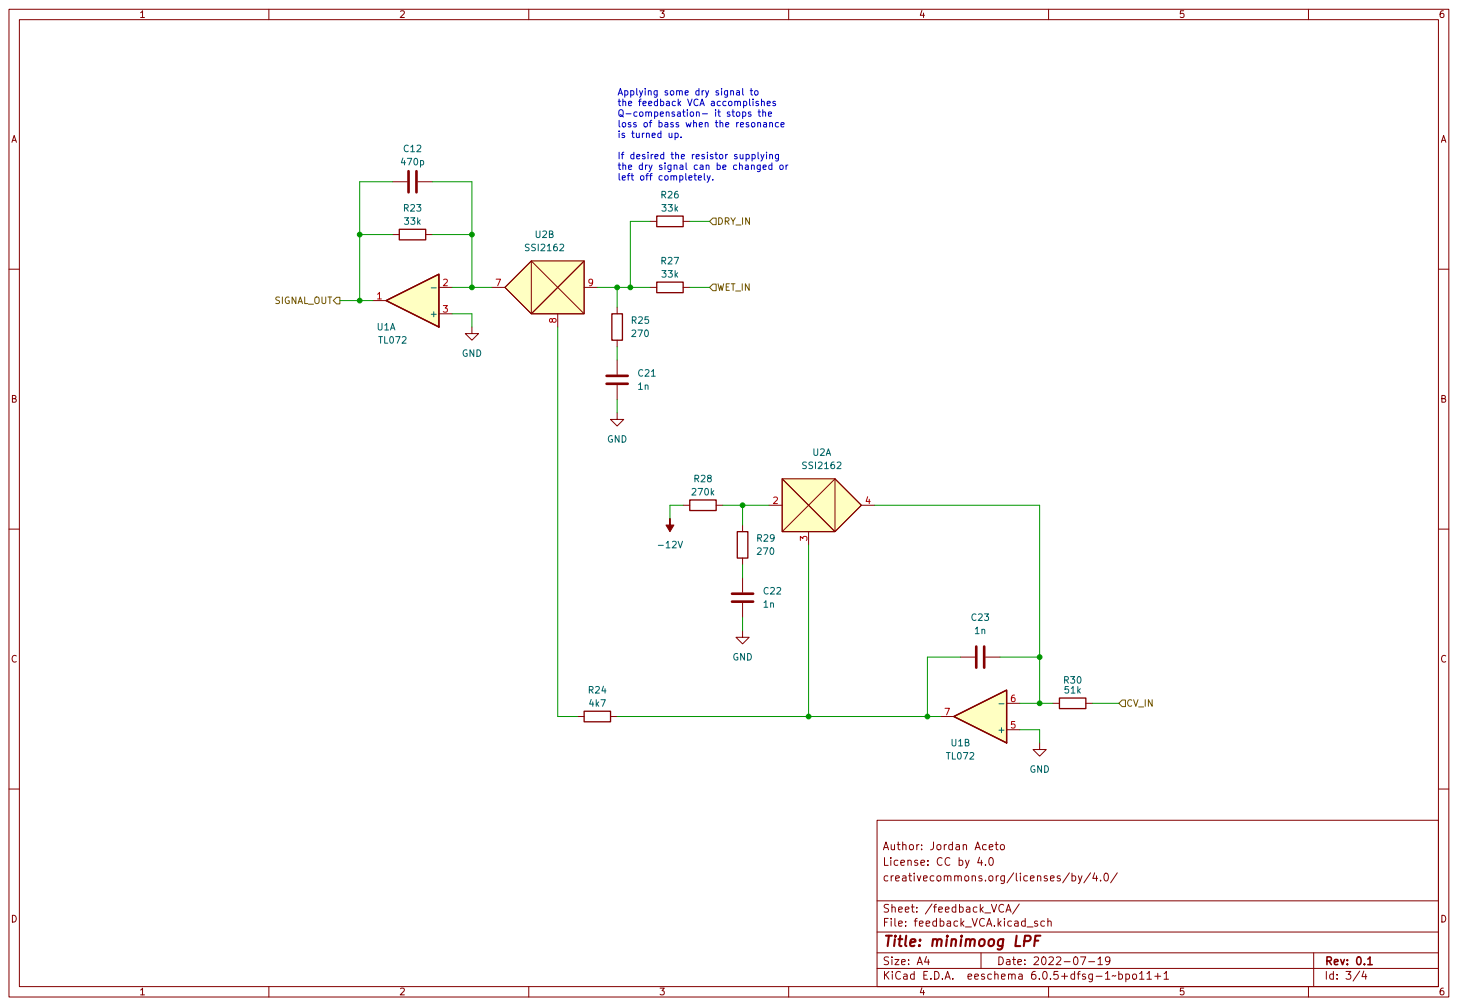
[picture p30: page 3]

the feedback VCA accomplishes
Q-compensation- it stops the
loss of bass when the resonance
is turned up.

If desired the resistor supplying
the dry signal can be changed or
left off completely.
DRY_IN WET_IN

License: CC by 4.0 Author: Jordan Aceto GND GND

creativecommons.org/licenses/by/4.0/

Sheet: /feedback_VCA/
File: feedback_VCA.kicad_sch
Id: 3/4 Title: minimoog LPF

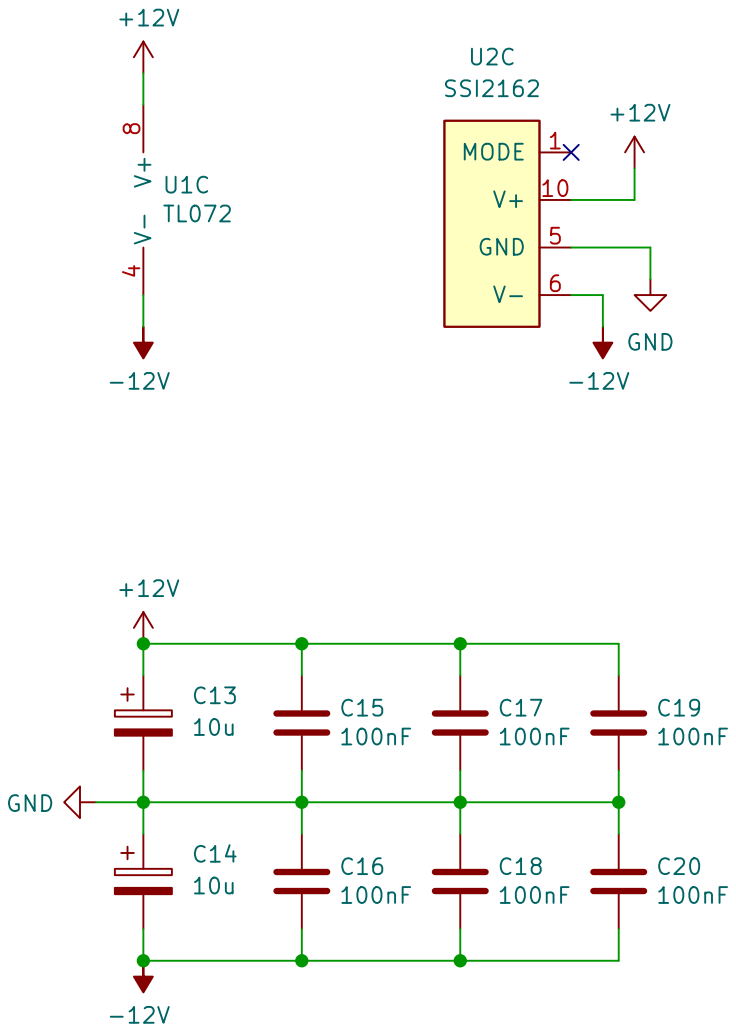
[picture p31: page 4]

License: CC by 4.0 Author: Jordan Aceto

creativecommons.org/licenses/by/4.0/

Sheet: /power_supply/
File: power_supply.kicad_sch
Id: 4/4 Title: minimoog LPF

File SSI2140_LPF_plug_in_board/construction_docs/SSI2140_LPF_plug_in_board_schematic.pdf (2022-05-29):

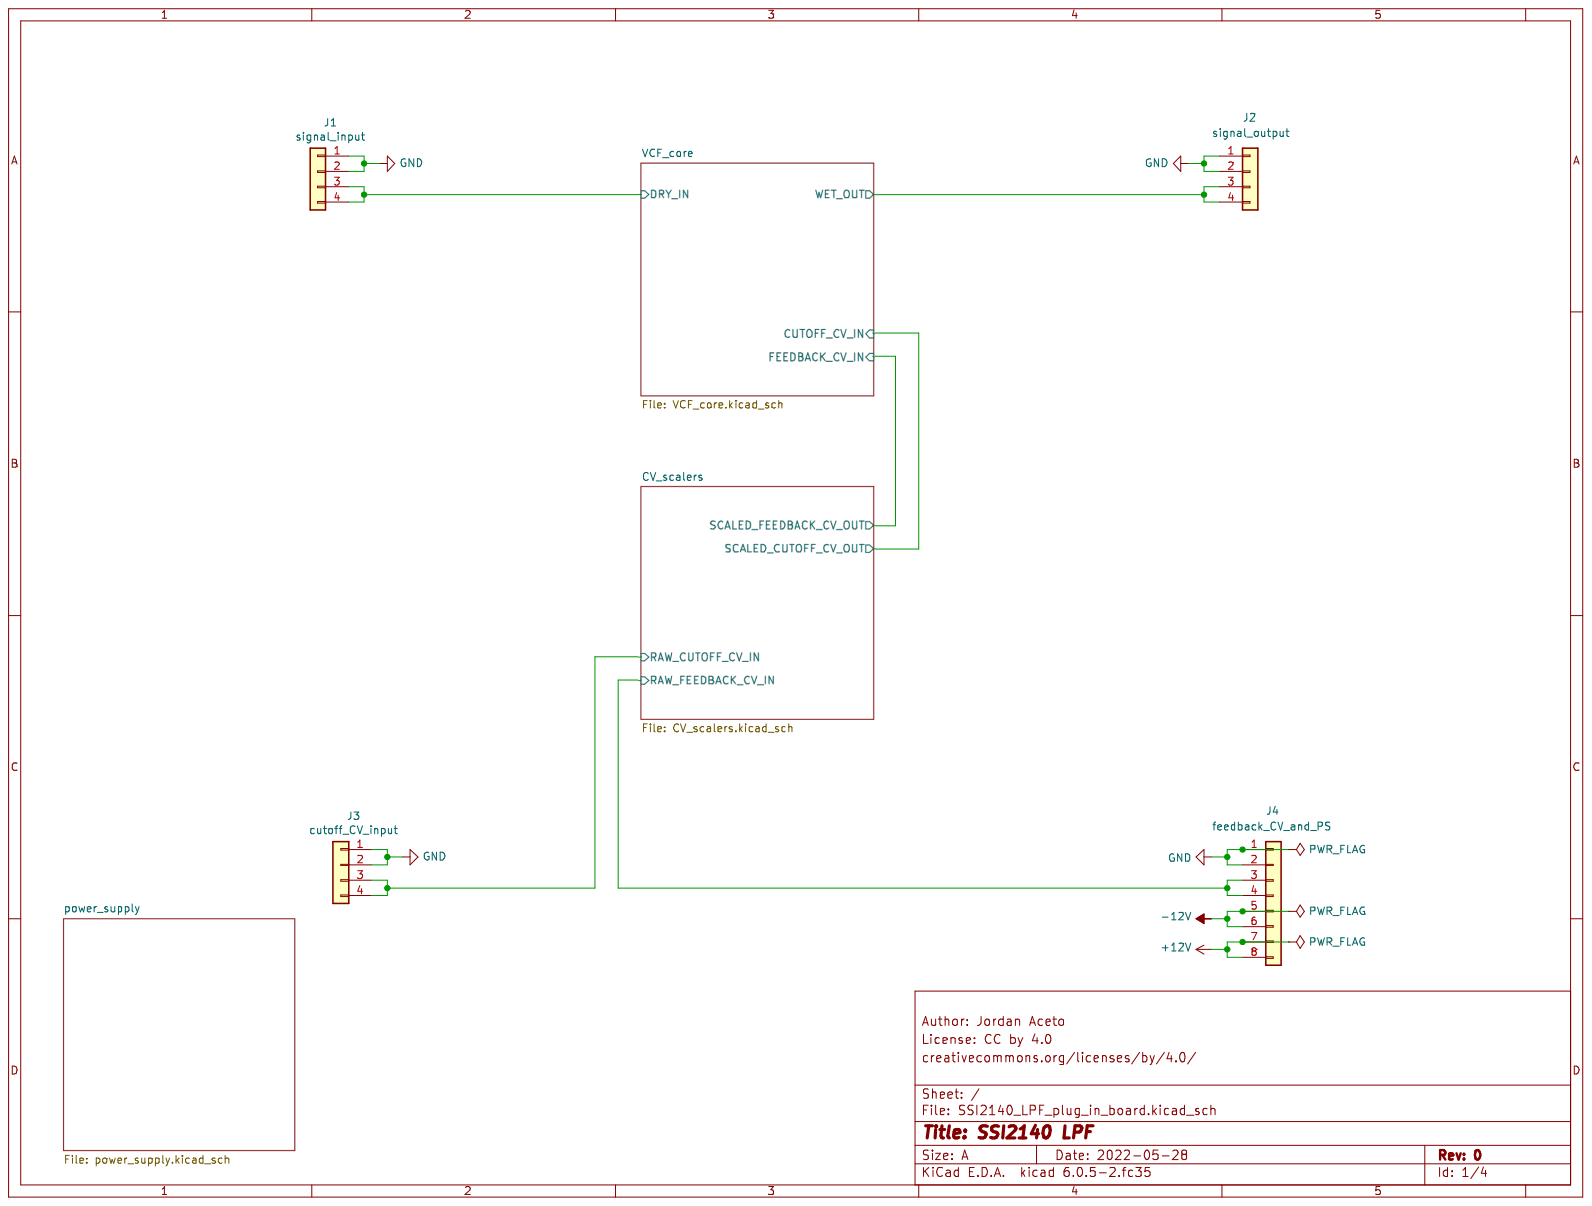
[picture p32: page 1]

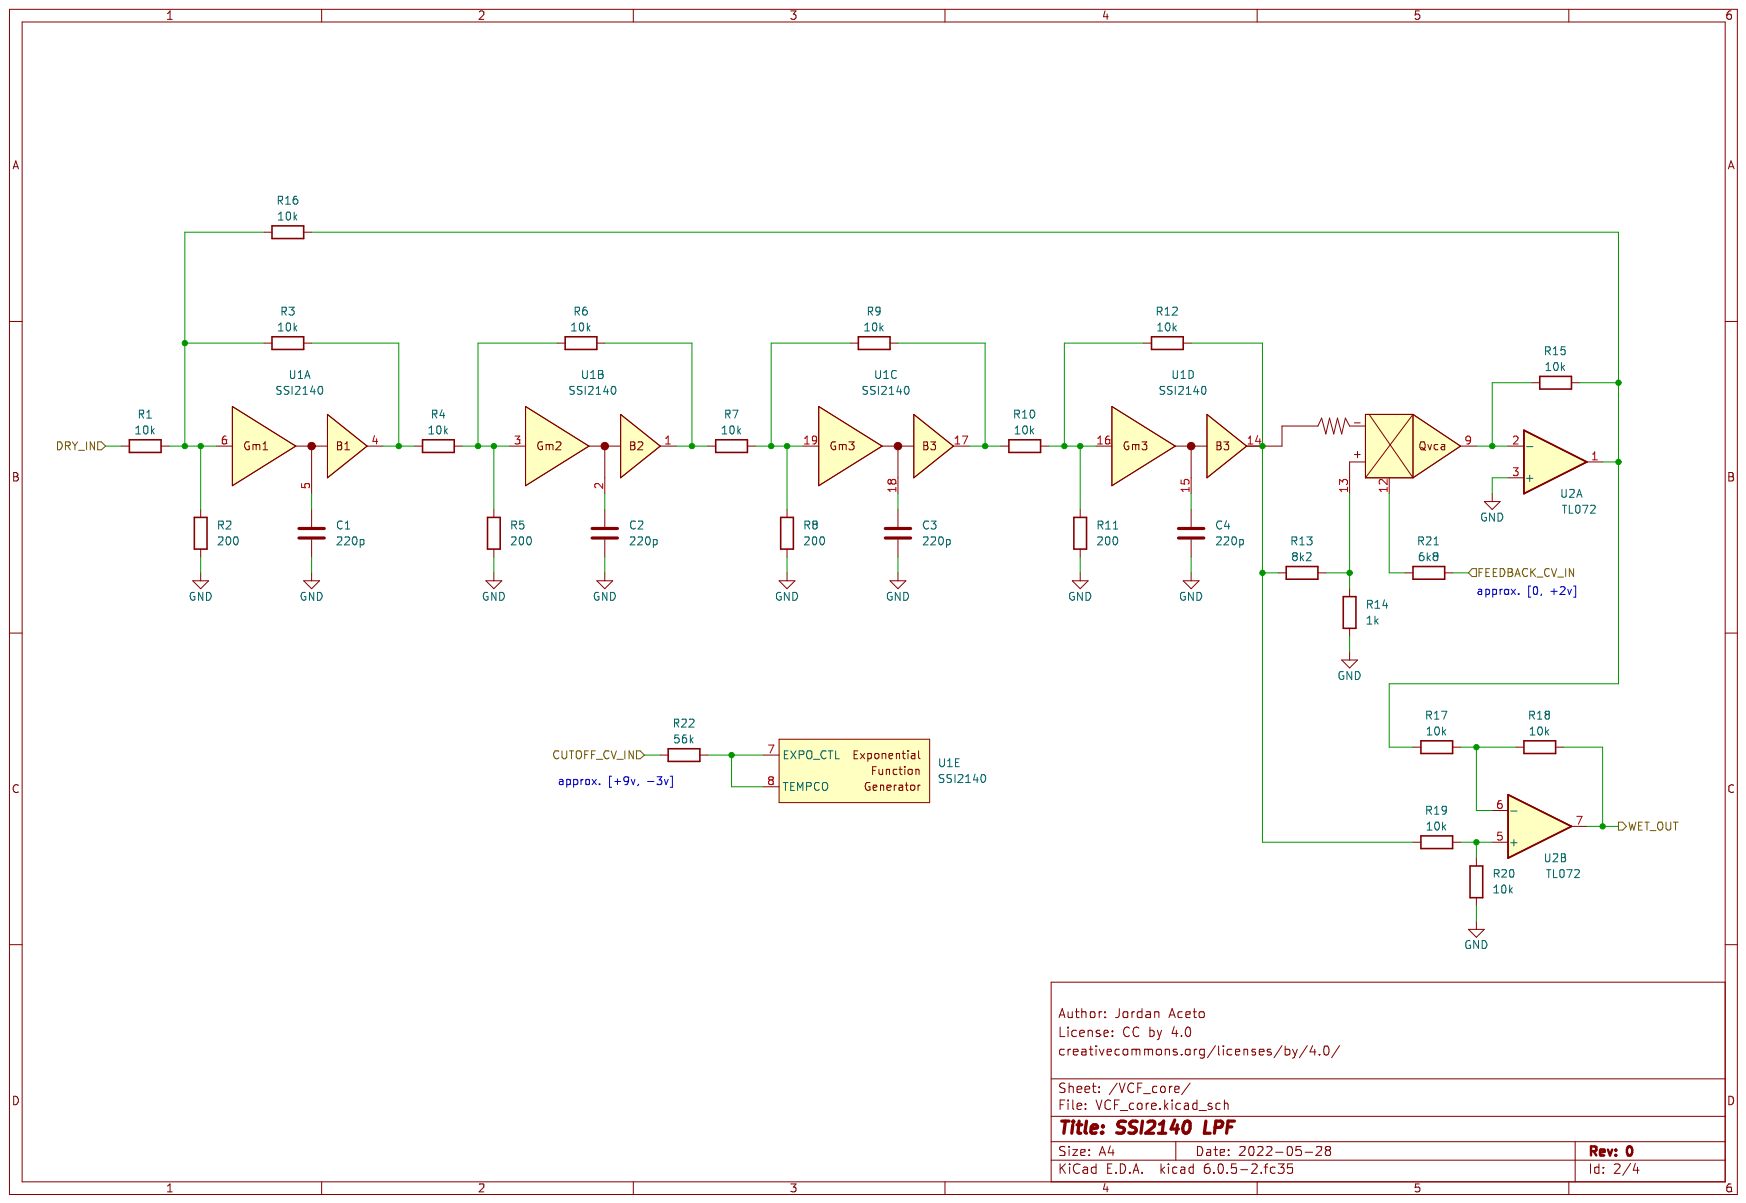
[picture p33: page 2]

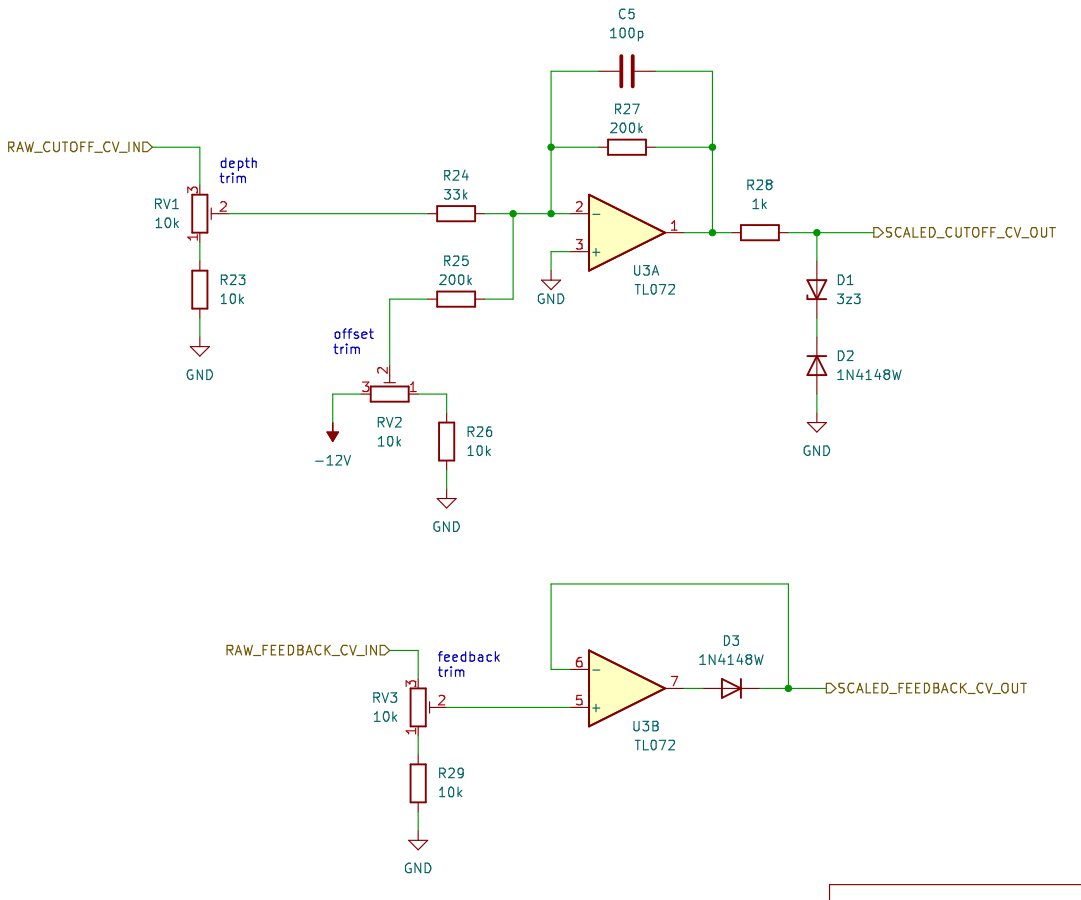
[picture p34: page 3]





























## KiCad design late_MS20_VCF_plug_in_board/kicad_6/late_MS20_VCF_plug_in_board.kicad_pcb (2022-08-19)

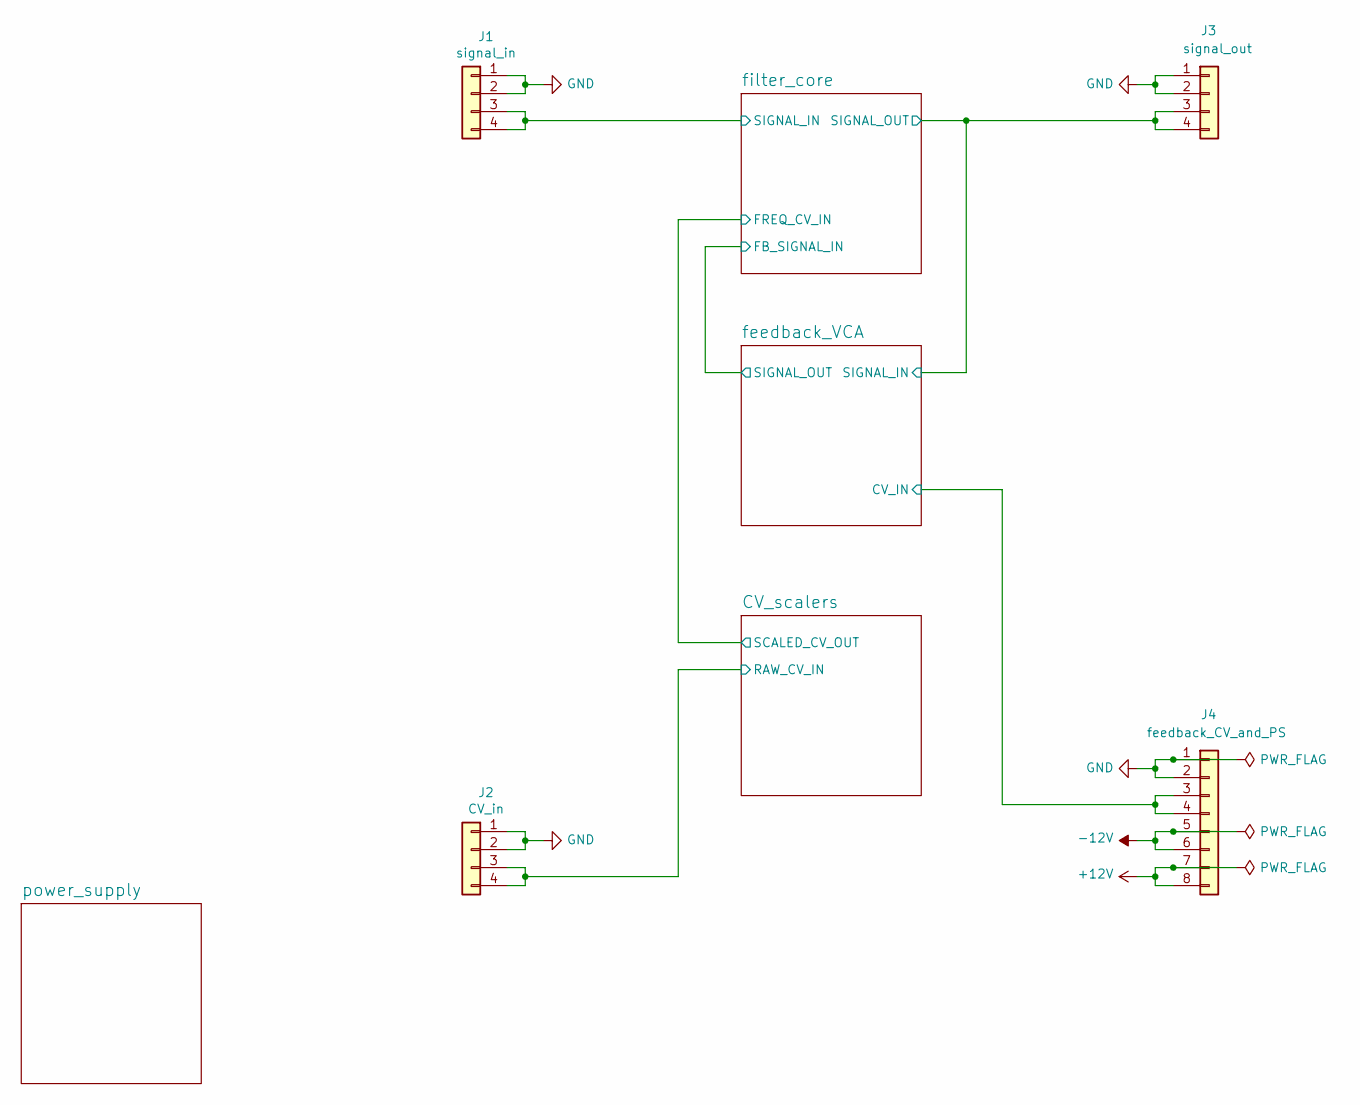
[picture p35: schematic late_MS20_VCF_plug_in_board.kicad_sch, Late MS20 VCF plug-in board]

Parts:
J1: signal_in; PinHeader_1x04_P2.54mm_Vertical
J2: CV_in; PinHeader_1x04_P2.54mm_Vertical
J3: signal_out; PinHeader_1x04_P2.54mm_Vertical
J4: feedback_CV_and_PS; PinHeader_1x08_P2.54mm_Vertical

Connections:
+12V: J4.7, J4.8; also elsewhere on the board
-12V: J4.5, J4.6; also elsewhere on the board
/CV_scalers/RAW_CV_IN: J2.3, J2.4; also elsewhere on the board
/feedback_VCA/CV_IN: J4.3, J4.4; also elsewhere on the board
/feedback_VCA/SIGNAL_IN: J3.3, J3.4; also elsewhere on the board
/filter_core/SIGNAL_IN: J1.3, J1.4; also elsewhere on the board
GND: J1.1, J1.2, J2.1, J2.2, J3.1, J3.2, J4.1, J4.2; also elsewhere on the board

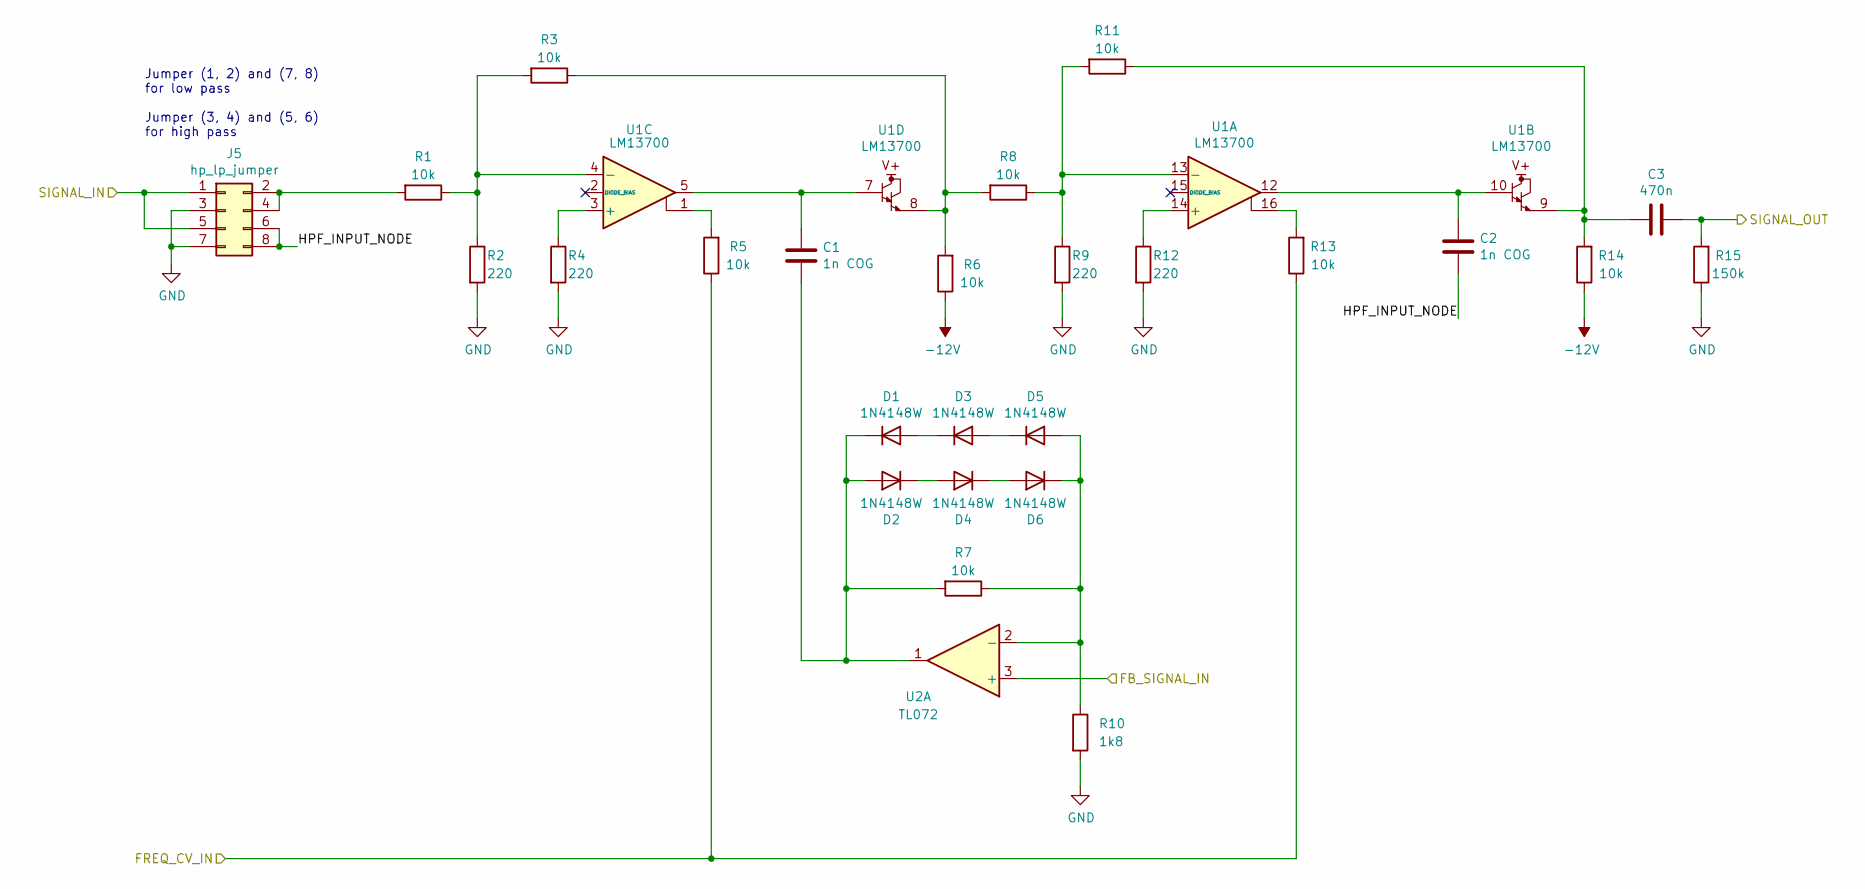
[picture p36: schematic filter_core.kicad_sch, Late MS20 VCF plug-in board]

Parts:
C1, C2: 1n COG; C_0805_2012Metric
C3: 470n; C_Rect_L7.0mm_W3.5mm_P5.00mm
D1, D2, D3, D4, D5, D6: 1N4148W; D_SOD-123
J5: hp_lp_jumper; PinHeader_2x04_P2.54mm_Vertical
R1, R3, R5, R6, R7, R8, R11, R13, R14: 10k; R_0603_1608Metric
R2, R4, R9, R12: 220; R_0603_1608Metric
R10: 1k8; R_0603_1608Metric
R15: 150k; R_0603_1608Metric
U1: LM13700; SOIC-16_3.9x9.9mm_P1.27mm
U2: TL072; SOIC-8_3.9x4.9mm_P1.27mm

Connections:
-12V: R6.1, R14.1; also elsewhere on the board
/CV_scalers/SCALED_CV_OUT: R5.1, R13.1; also elsewhere on the board
/feedback_VCA/SIGNAL_IN: C3.1, R15.2; also elsewhere on the board
/feedback_VCA/SIGNAL_OUT: U2.3 (+); also elsewhere on the board
/filter_core/HPF_INPUT_NODE: C2.2, J5.6, J5.8
/filter_core/SIGNAL_IN: J5.1, J5.5; also elsewhere on the board
GND: J5.3, J5.7, R2.2, R4.2, R9.2, R10.2, R12.2, R15.1; also elsewhere on the board
unnamed: C1.1, U1.5, U1.7
unnamed: C1.2, D1.1 (K), D2.2 (A), R7.2, U2.1
unnamed: C2.1, U1.10, U1.12
unnamed: C3.2, R11.1, R14.2, U1.9
unnamed: D1.2 (A), D3.1 (K)
unnamed: D2.1 (K), D4.2 (A)
unnamed: D3.2 (A), D5.1 (K)
unnamed: D4.1 (K), D6.2 (A)
unnamed: D5.2 (A), D6.1 (K), R7.1, R10.1, U2.2 (-)
unnamed: J5.2, J5.4, R1.2
unnamed: R1.1, R2.1, R3.2, U1.4 (-)
unnamed: R3.1, R6.2, R8.2, U1.8
unnamed: R4.1, U1.3 (+)
unnamed: R5.2, U1.1
unnamed: R8.1, R9.1, R11.2, U1.13 (-)
unnamed: R12.1, U1.14 (+)
unnamed: R13.2, U1.16

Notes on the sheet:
Jumper (1, 2) and (7, 8) for low pass Jumper (3, 4) and (5, 6) for high pass

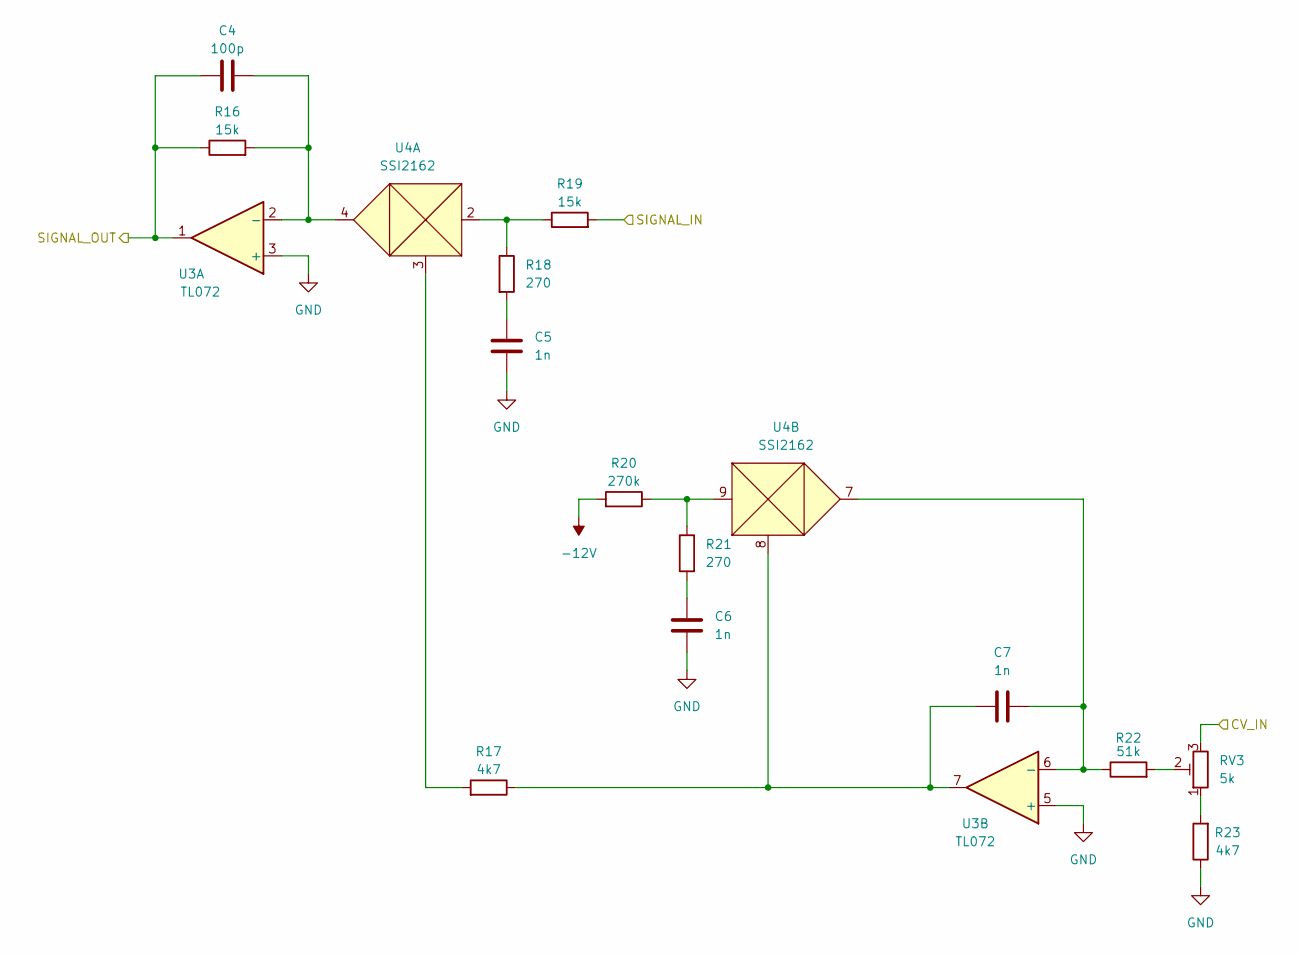
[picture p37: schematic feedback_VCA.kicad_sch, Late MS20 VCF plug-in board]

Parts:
C4: 100p; C_0603_1608Metric
C5, C6, C7: 1n; C_0603_1608Metric
R16, R19: 15k; R_0603_1608Metric
R17, R23: 4k7; R_0603_1608Metric
R18, R21: 270; R_0603_1608Metric
R20: 270k; R_0603_1608Metric
R22: 51k; R_0603_1608Metric
RV3: 5k; Potentiometer_Bourns_3296W_Vertical
U3: TL072; SOIC-8_3.9x4.9mm_P1.27mm
U4: SSI2162; SSOP-10_3.9x4.9mm_P1.00mm

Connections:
-12V: R20.2; also elsewhere on the board
/feedback_VCA/CV_IN: RV3.3; also elsewhere on the board
/feedback_VCA/SIGNAL_IN: R19.2; also elsewhere on the board
/feedback_VCA/SIGNAL_OUT: C4.1, R16.1, U3.1; also elsewhere on the board
GND: C5.2, C6.2, R23.1, U3.3 (+), U3.5 (+); also elsewhere on the board
unnamed: C4.2, R16.2, U3.2 (-), U4.4
unnamed: C5.1, R18.2
unnamed: C6.1, R21.2
unnamed: C7.1, R17.1, U3.7, U4.8
unnamed: C7.2, R22.1, U3.6 (-), U4.7
unnamed: R17.2, U4.3
unnamed: R18.1, R19.1, U4.2
unnamed: R20.1, R21.1, U4.9
unnamed: R22.2, RV3.2
unnamed: R23.2, RV3.1

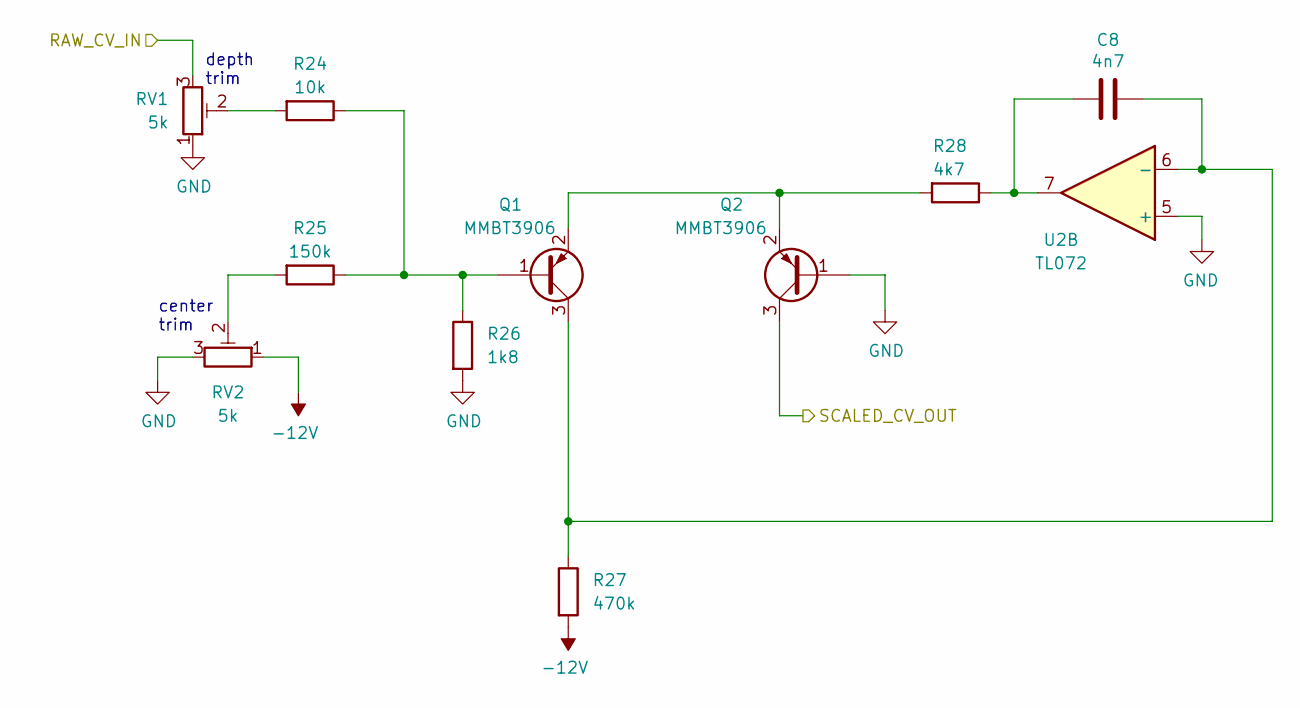
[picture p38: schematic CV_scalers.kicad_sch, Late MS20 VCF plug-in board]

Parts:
C8: 4n7; C_0603_1608Metric
Q1, Q2: MMBT3906; SOT-23
R24: 10k; R_0603_1608Metric
R25: 150k; R_0603_1608Metric
R26: 1k8; R_0603_1608Metric
R27: 470k; R_0603_1608Metric
R28: 4k7; R_0603_1608Metric
RV1, RV2: 5k; Potentiometer_Bourns_3296W_Vertical
U2: TL072; SOIC-8_3.9x4.9mm_P1.27mm

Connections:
-12V: R27.2, RV2.1; also elsewhere on the board
/CV_scalers/RAW_CV_IN: RV1.3; also elsewhere on the board
/CV_scalers/SCALED_CV_OUT: Q2.3 (C); also elsewhere on the board
GND: Q2.1 (B), R26.2, RV1.1, RV2.3, U2.5 (+); also elsewhere on the board
unnamed: C8.1, R28.1, U2.7
unnamed: C8.2, Q1.3 (C), R27.1, U2.6 (-)
unnamed: Q1.1 (B), R24.1, R25.1, R26.1
unnamed: Q1.2 (E), Q2.2 (E), R28.2
unnamed: R24.2, RV1.2
unnamed: R25.2, RV2.2

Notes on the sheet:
center trim
depth trim

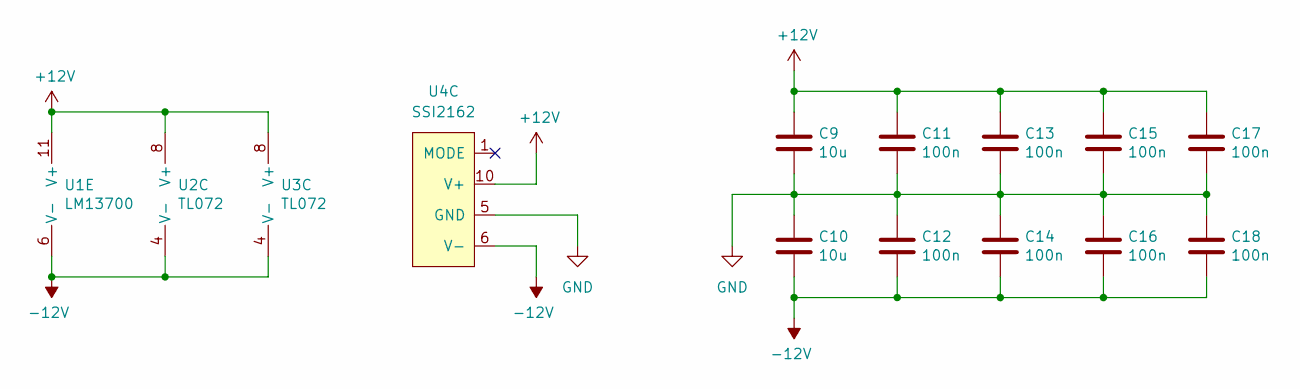
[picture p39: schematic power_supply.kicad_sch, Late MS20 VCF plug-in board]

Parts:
C9, C10: 10u; C_0805_2012Metric
C11, C12, C13, C14, C15, C16, C17, C18: 100n; C_0603_1608Metric
U1: LM13700; SOIC-16_3.9x9.9mm_P1.27mm
U2, U3: TL072; SOIC-8_3.9x4.9mm_P1.27mm
U4: SSI2162; SSOP-10_3.9x4.9mm_P1.00mm

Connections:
+12V: C9.1, C11.1, C13.1, C15.1, C17.1, U1.11 (V+), U2.8 (V+), U3.8 (V+), U4.10 (V+); also elsewhere on the board
-12V: C10.2, C12.2, C14.2, C16.2, C18.2, U1.6 (V-), U2.4 (V-), U3.4 (V-), U4.6 (V-); also elsewhere on the board
GND: C9.2, C10.1, C11.2, C12.1, C13.2, C14.1, C15.2, C16.1, C17.2, C18.1, U4.5 (GND); also elsewhere on the board

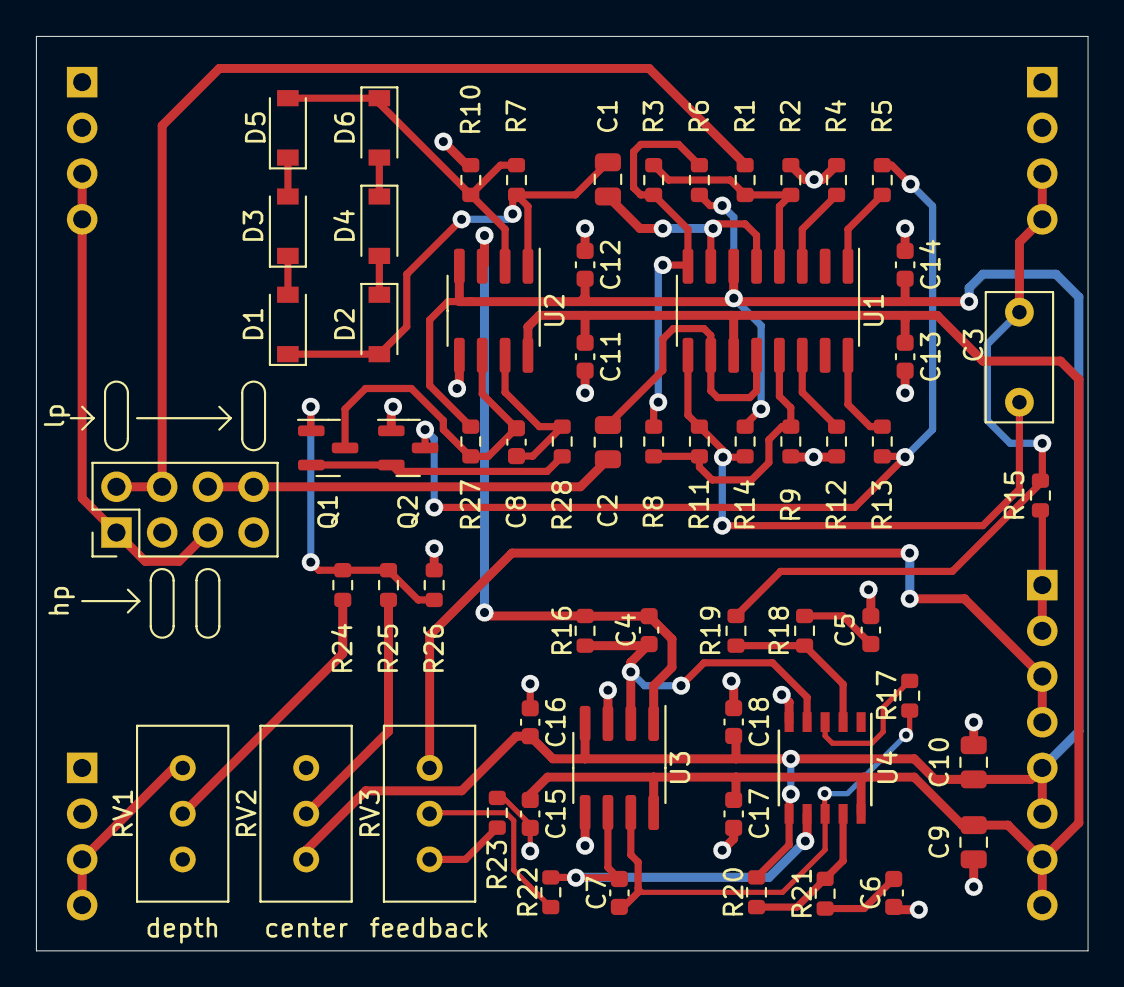
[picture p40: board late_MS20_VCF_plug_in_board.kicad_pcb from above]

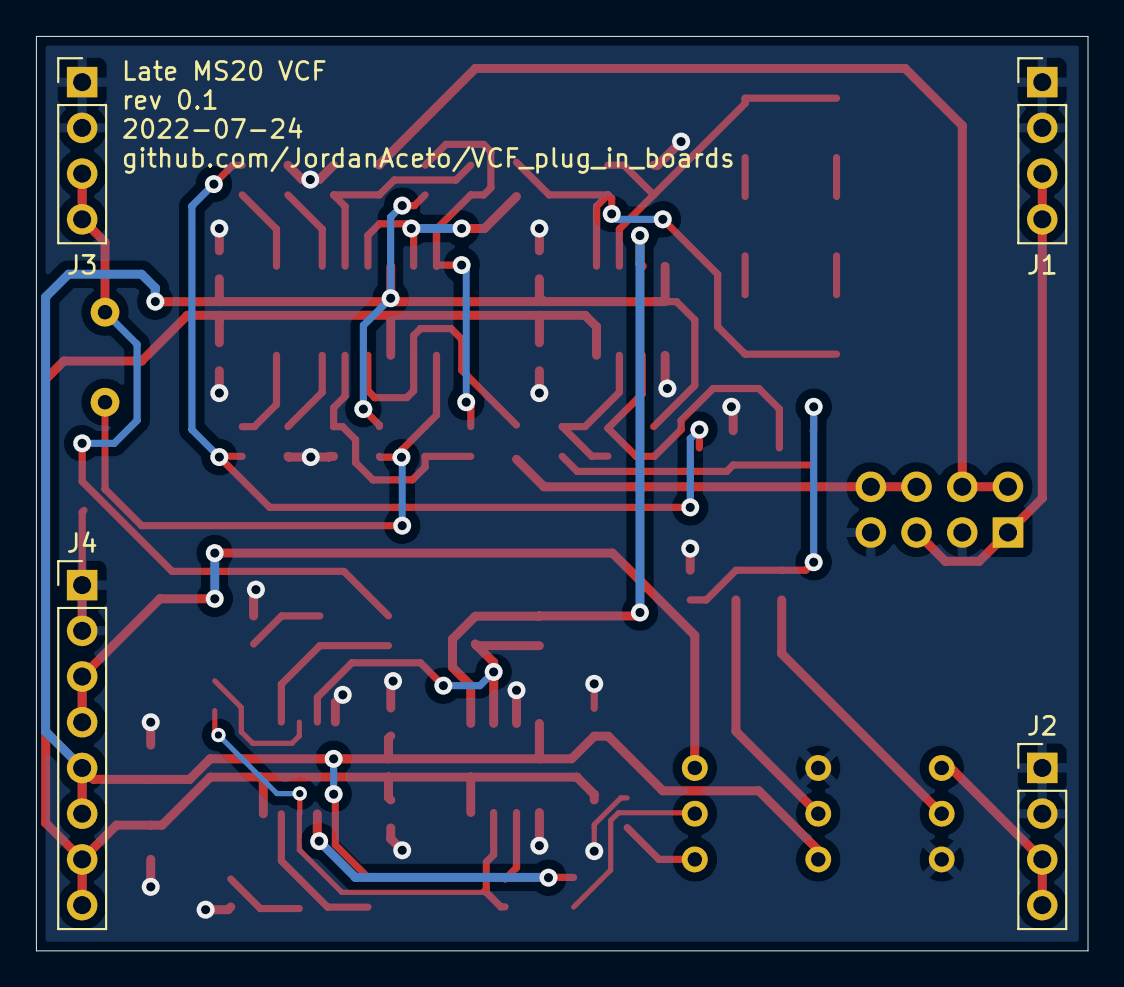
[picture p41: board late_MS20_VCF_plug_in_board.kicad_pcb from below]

Board: 2 copper layers, 58.4 x 50.8 mm, 66 parts (4 on the bottom side), 43 nets.

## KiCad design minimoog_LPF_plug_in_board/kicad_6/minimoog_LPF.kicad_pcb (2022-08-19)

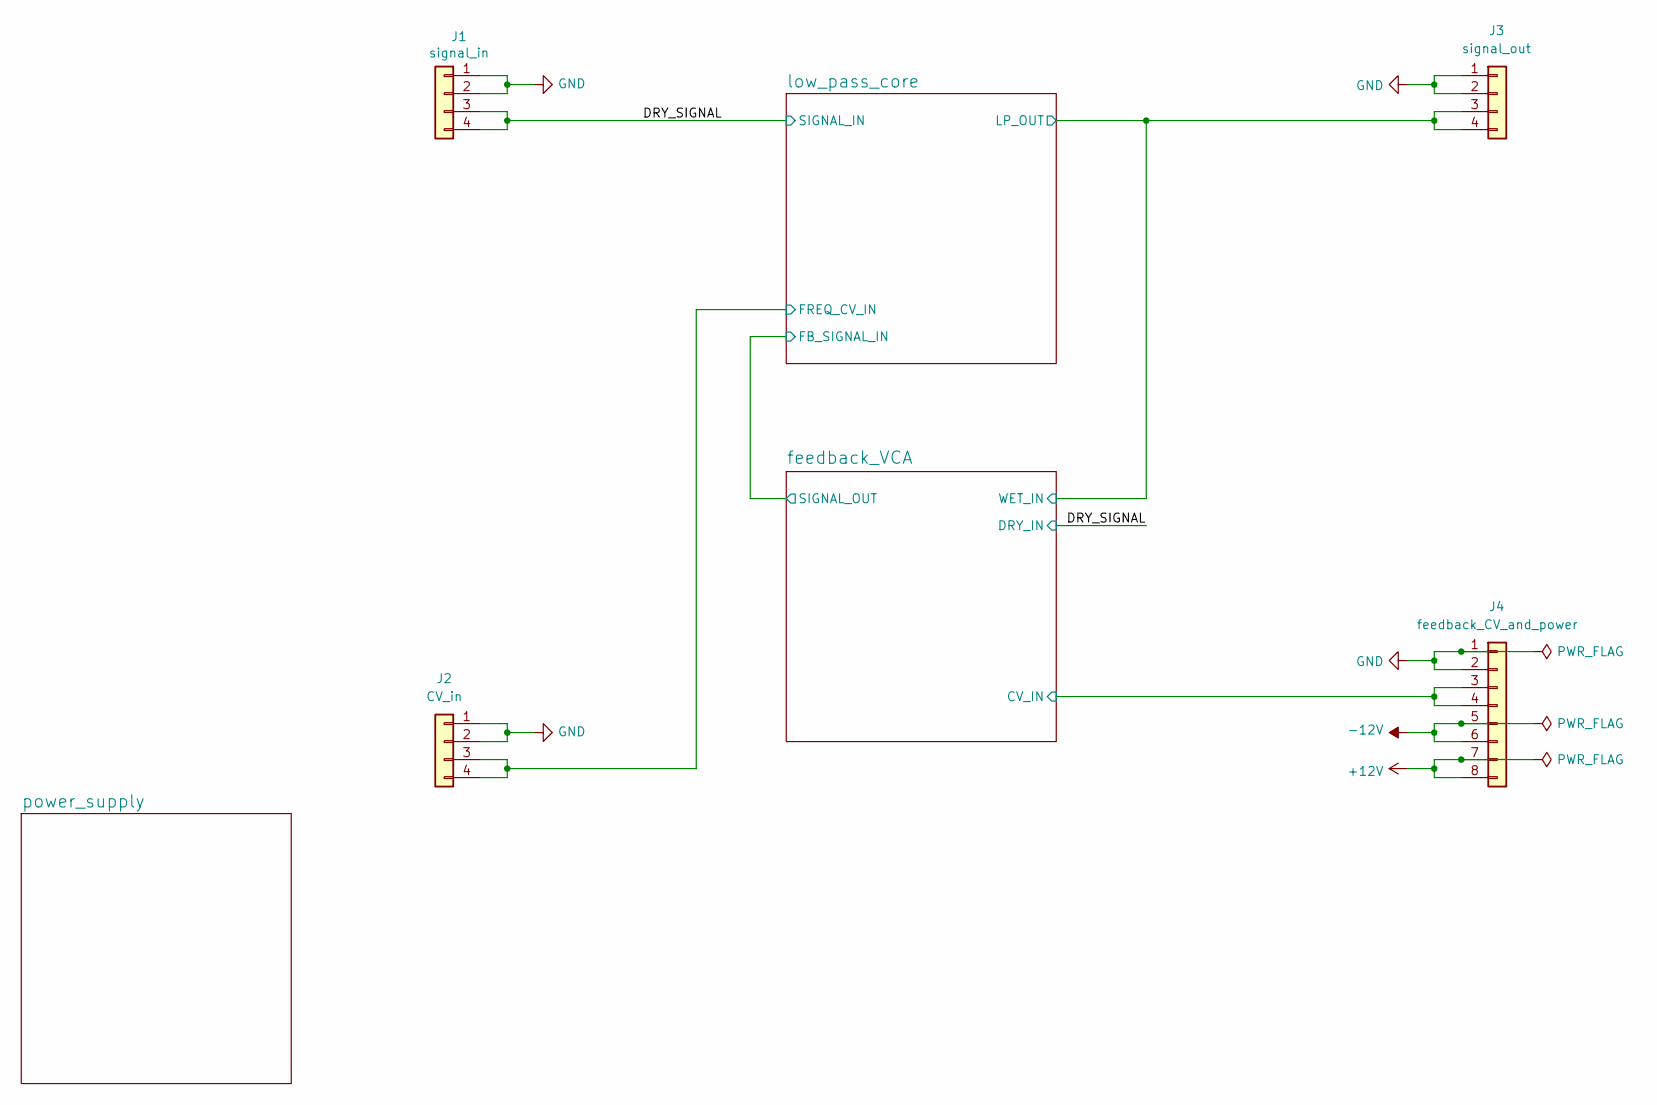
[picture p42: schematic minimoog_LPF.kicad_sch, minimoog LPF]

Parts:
J1: signal_in; PinHeader_1x04_P2.54mm_Vertical
J2: CV_in; PinHeader_1x04_P2.54mm_Vertical
J3: signal_out; PinHeader_1x04_P2.54mm_Vertical
J4: feedback_CV_and_power; PinHeader_1x08_P2.54mm_Vertical

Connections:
+12V: J4.7, J4.8; also elsewhere on the board
-12V: J4.5, J4.6; also elsewhere on the board
/DRY_SIGNAL: J1.3, J1.4; also elsewhere on the board
/feedback_VCA/CV_IN: J4.3, J4.4; also elsewhere on the board
/feedback_VCA/WET_IN: J3.3, J3.4; also elsewhere on the board
/low_pass_core/FREQ_CV_IN: J2.3, J2.4; also elsewhere on the board
GND: J1.1, J1.2, J2.1, J2.2, J3.1, J3.2, J4.1, J4.2; also elsewhere on the board

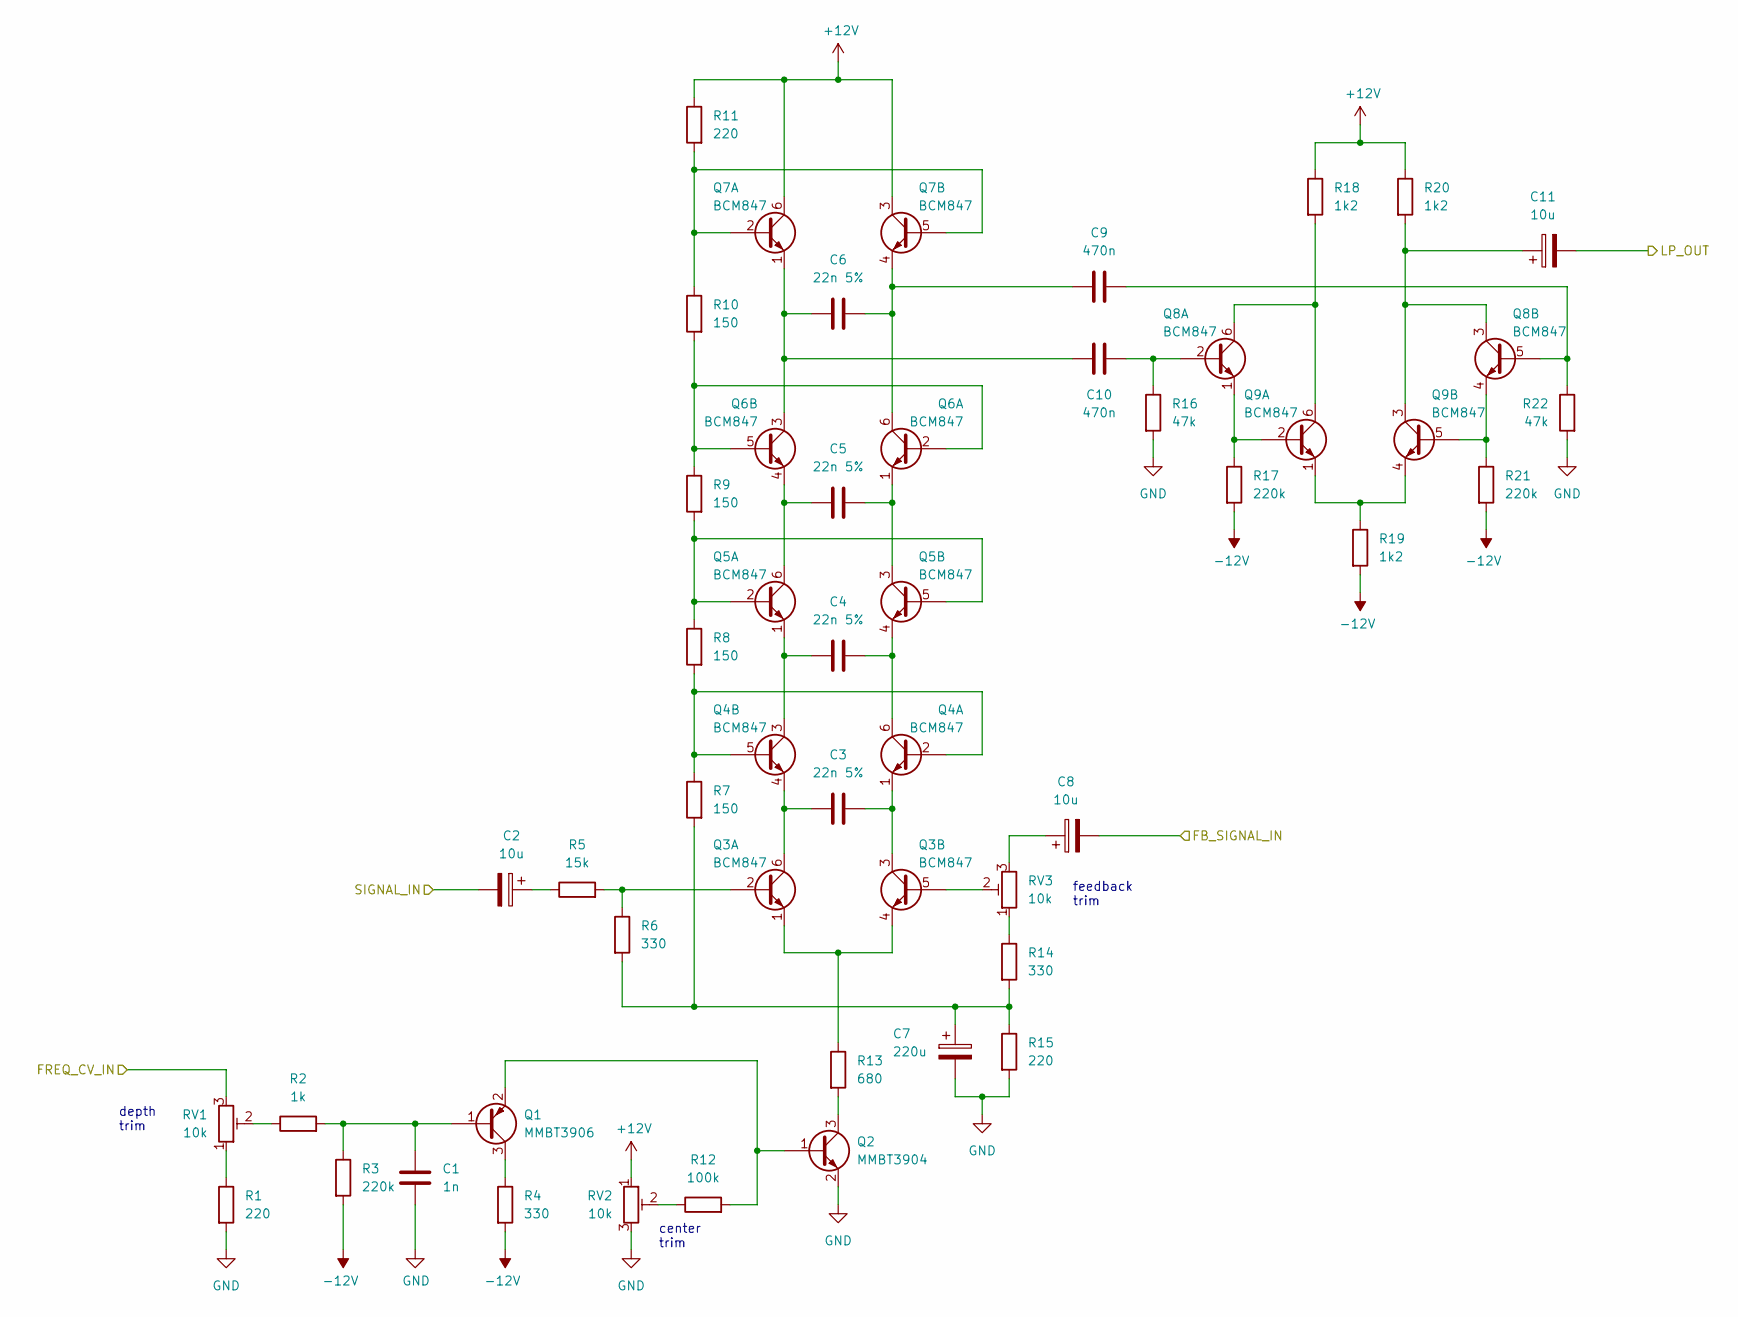
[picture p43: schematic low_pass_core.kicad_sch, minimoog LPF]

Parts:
C1: 1n; C_0603_1608Metric
C2, C8, C11: 10u; CP_Radial_D6.3mm_P2.50mm
C3, C4, C5, C6: 22n 5%; C_0805_2012Metric
C7: 220u; CP_Radial_D6.3mm_P2.50mm
C9, C10: 470n; C_Rect_L7.0mm_W3.5mm_P5.00mm
Q1: MMBT3906; SOT-23
Q2: MMBT3904; SOT-23
Q3, Q4, Q5, Q6, Q7, Q8, Q9: BCM847; SOT-363_SC-70-6
R1, R11, R15: 220; R_0603_1608Metric
R2: 1k; R_0603_1608Metric
R3, R17, R21: 220k; R_0603_1608Metric
R4, R6, R14: 330; R_0603_1608Metric
R5: 15k; R_0603_1608Metric
R7, R8, R9, R10: 150; R_0603_1608Metric
R12: 100k; R_0603_1608Metric
R13: 680; R_0603_1608Metric
R16, R22: 47k; R_0603_1608Metric
R18, R19, R20: 1k2; R_0603_1608Metric
RV1, RV2, RV3: 10k; Potentiometer_Bourns_3296W_Vertical

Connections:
+12V: Q7.3 (C), Q7.6 (C), R11.1, R18.1, R20.1, RV2.1; also elsewhere on the board
-12V: R3.2, R4.2, R17.2, R19.2, R21.2; also elsewhere on the board
/DRY_SIGNAL: C2.2; also elsewhere on the board
/feedback_VCA/SIGNAL_OUT: C8.2; also elsewhere on the board
/feedback_VCA/WET_IN: C11.2; also elsewhere on the board
/low_pass_core/FREQ_CV_IN: RV1.3; also elsewhere on the board
GND: C1.1, C7.2, Q2.2 (E), R1.2, R15.2, R16.2, R22.2, RV2.3; also elsewhere on the board
unnamed: C1.2, Q1.1 (B), R2.2, R3.1
unnamed: C2.1, R5.1
unnamed: C3.1, Q3.6 (C), Q4.4 (E)
unnamed: C3.2, Q3.3 (C), Q4.1 (E)
unnamed: C4.1, Q4.3 (C), Q5.1 (E)
unnamed: C4.2, Q4.6 (C), Q5.4 (E)
unnamed: C5.1, Q5.6 (C), Q6.4 (E)
unnamed: C5.2, Q5.3 (C), Q6.1 (E)
unnamed: C6.2, C9.1, Q6.6 (C), Q7.4 (E)
unnamed: C7.1, R6.2, R7.2, R14.2, R15.1
unnamed: C8.1, RV3.3
unnamed: C9.2, Q8.5 (B), R22.1
unnamed: C6.1, C10.1, Q6.3 (C), Q7.1 (E)
unnamed: C10.2, Q8.2 (B), R16.1
unnamed: C11.1, Q8.3 (C), Q9.3 (C), R20.2
unnamed: Q1.2 (E), Q2.1 (B), R12.2
unnamed: Q1.3 (C), R4.1
unnamed: Q2.3 (C), R13.2
unnamed: Q3.1 (E), Q3.4 (E), R13.1
unnamed: Q3.2 (B), R5.2, R6.1
unnamed: Q3.5 (B), RV3.2
unnamed: Q4.2 (B), Q4.5 (B), R7.1, R8.2
unnamed: Q5.2 (B), Q5.5 (B), R8.1, R9.2
unnamed: Q6.2 (B), Q6.5 (B), R9.1, R10.2
unnamed: Q7.2 (B), Q7.5 (B), R10.1, R11.2
unnamed: Q8.1 (E), Q9.2 (B), R17.1
unnamed: Q8.4 (E), Q9.5 (B), R21.1
unnamed: Q8.6 (C), Q9.6 (C), R18.2
unnamed: Q9.1 (E), Q9.4 (E), R19.1
unnamed: R1.1, RV1.1
unnamed: R2.1, RV1.2
unnamed: R12.1, RV2.2
unnamed: R14.1, RV3.1

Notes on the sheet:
depth trim
feedback trim
center trim

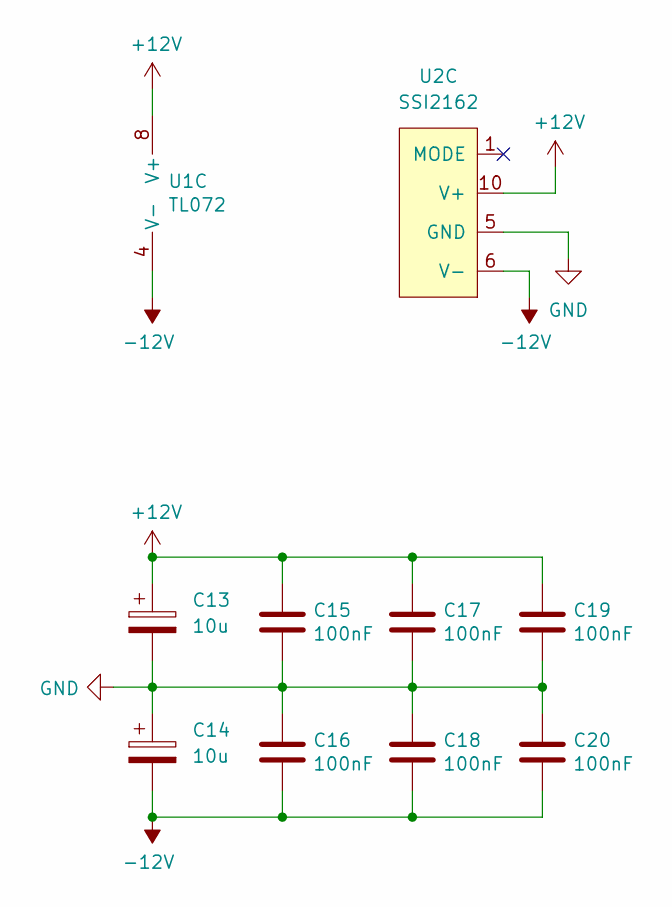
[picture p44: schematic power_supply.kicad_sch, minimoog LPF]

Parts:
C13, C14: 10u; CP_Radial_D6.3mm_P2.50mm
C15, C16, C17, C18, C19, C20: 100nF; C_0603_1608Metric
U1: TL072; SOIC-8_3.9x4.9mm_P1.27mm
U2: SSI2162; SSOP-10_3.9x4.9mm_P1.00mm

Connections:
+12V: C13.1, C15.1, C17.1, C19.1, U1.8 (V+), U2.10 (V+); also elsewhere on the board
-12V: C14.2, C16.2, C18.2, C20.2, U1.4 (V-), U2.6 (V-); also elsewhere on the board
GND: C13.2, C14.1, C15.2, C16.1, C17.2, C18.1, C19.2, C20.1, U2.5 (GND); also elsewhere on the board

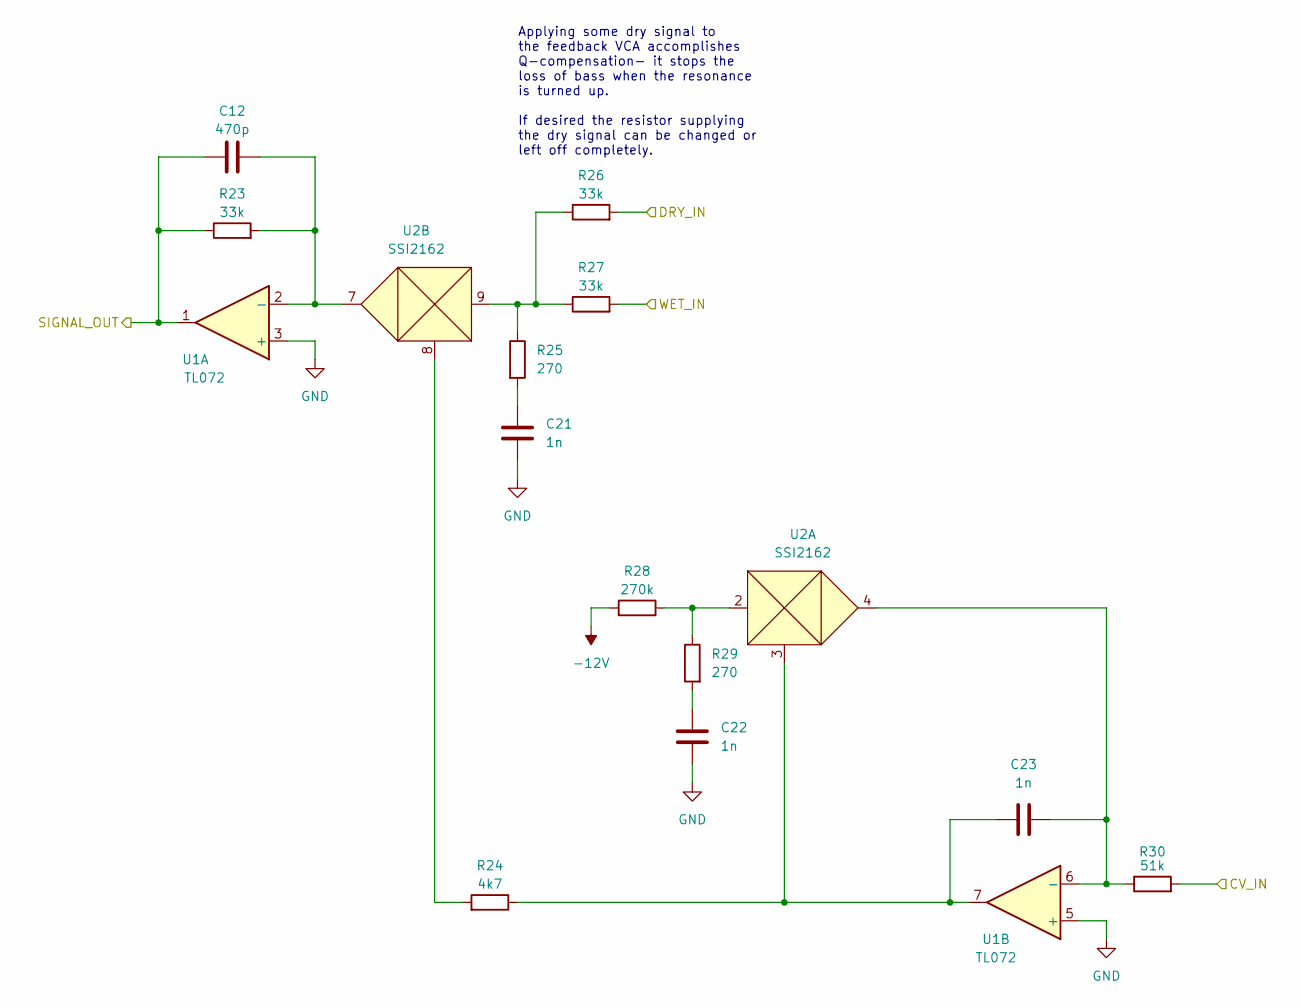
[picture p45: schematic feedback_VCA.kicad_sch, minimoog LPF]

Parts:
C12: 470p; C_0603_1608Metric
C21, C22, C23: 1n; C_0603_1608Metric
R23, R26, R27: 33k; R_0603_1608Metric
R24: 4k7; R_0603_1608Metric
R25, R29: 270; R_0603_1608Metric
R28: 270k; R_0603_1608Metric
R30: 51k; R_0603_1608Metric
U1: TL072; SOIC-8_3.9x4.9mm_P1.27mm
U2: SSI2162; SSOP-10_3.9x4.9mm_P1.00mm

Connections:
-12V: R28.2; also elsewhere on the board
/DRY_SIGNAL: R26.2; also elsewhere on the board
/feedback_VCA/CV_IN: R30.2; also elsewhere on the board
/feedback_VCA/SIGNAL_OUT: C12.1, R23.1, U1.1; also elsewhere on the board
/feedback_VCA/WET_IN: R27.2; also elsewhere on the board
GND: C21.2, C22.2, U1.3 (+), U1.5 (+); also elsewhere on the board
unnamed: C12.2, R23.2, U1.2 (-), U2.7
unnamed: C21.1, R25.2
unnamed: C22.1, R29.2
unnamed: C23.1, R24.1, U1.7, U2.3
unnamed: C23.2, R30.1, U1.6 (-), U2.4
unnamed: R24.2, U2.8
unnamed: R25.1, R26.1, R27.1, U2.9
unnamed: R28.1, R29.1, U2.2

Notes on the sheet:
Applying some dry signal to the feedback VCA accomplishes Q-compensation- it stops the loss of bass when the resonance is turned up. If desired the resistor supplying the dry signal can be changed or left off completely.

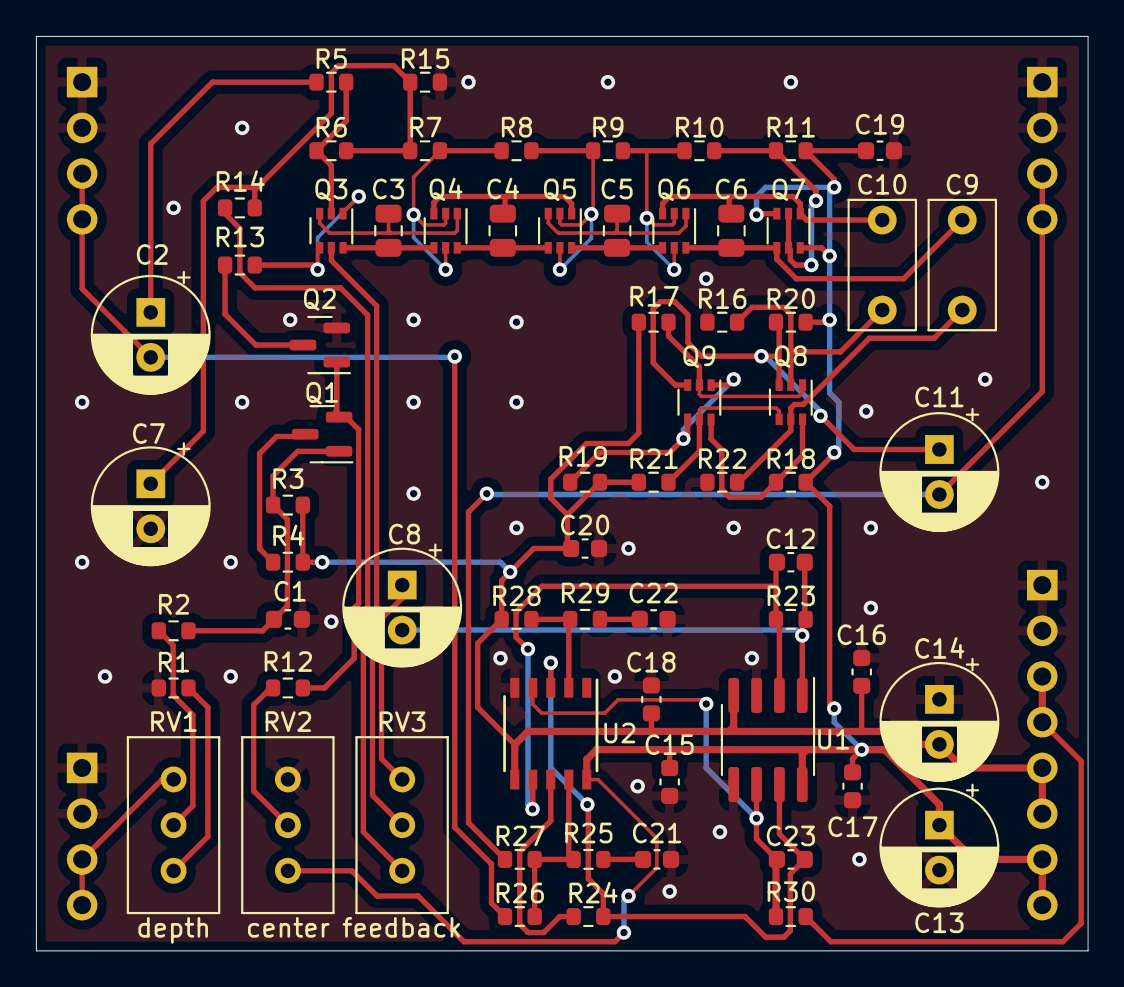
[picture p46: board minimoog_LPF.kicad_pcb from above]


Board: 2 copper layers, 58.4 x 50.8 mm, 71 parts (4 on the bottom side), 49 nets.

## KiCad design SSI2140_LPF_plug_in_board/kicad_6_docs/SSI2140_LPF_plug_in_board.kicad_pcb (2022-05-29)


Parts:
J1: signal_input; PinHeader_1x04_P2.54mm_Vertical
J2: signal_output; PinHeader_1x04_P2.54mm_Vertical
J3: cutoff_CV_input; PinHeader_1x04_P2.54mm_Vertical
J4: feedback_CV_and_PS; PinHeader_1x08_P2.54mm_Vertical

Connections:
+12V: J4.7, J4.8; also elsewhere on the board
-12V: J4.5, J4.6; also elsewhere on the board
/CV_scalers/RAW_CUTOFF_CV_IN: J3.3, J3.4; also elsewhere on the board
/CV_scalers/RAW_FEEDBACK_CV_IN: J4.3, J4.4; also elsewhere on the board
/VCF_core/DRY_IN: J1.3, J1.4; also elsewhere on the board
/VCF_core/WET_OUT: J2.3, J2.4; also elsewhere on the board
GND: J1.1, J1.2, J2.1, J2.2, J3.1, J3.2, J4.1, J4.2; also elsewhere on the board


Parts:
C1, C2, C3, C4: 220p; timing_cap_dual_fp
R1, R3, R4, R6, R7, R9, R10, R12, R15, R16, R17, R18, R19, R20: 10k; R_0805_2012Metric
R2, R5, R8, R11: 200; R_0805_2012Metric
R13: 8k2; R_0805_2012Metric
R14: 1k; R_0805_2012Metric
R21: 6k8; R_0805_2012Metric
R22: 56k; R_0805_2012Metric
U1: SSI2140; TSSOP-20_4.4x6.5mm_P0.65mm
U2: TL072; SOIC-8_3.9x4.9mm_P1.27mm

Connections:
/CV_scalers/SCALED_CUTOFF_CV_OUT: R22.1; also elsewhere on the board
/CV_scalers/SCALED_FEEDBACK_CV_OUT: R21.2; also elsewhere on the board
/VCF_core/DRY_IN: R1.1; also elsewhere on the board
/VCF_core/WET_OUT: R18.2, U2.7; also elsewhere on the board
GND: C1.2, C2.2, C3.2, C4.2, R2.2, R5.2, R8.2, R11.2, R14.2, R20.2, U2.3 (+); also elsewhere on the board
unnamed: C1.1, U1.5
unnamed: C2.1, U1.2
unnamed: C3.1, U1.18
unnamed: C4.1, U1.15
unnamed: R3.2, R4.1, U1.4
unnamed: R4.2, R5.1, R6.1, U1.3
unnamed: R6.2, R7.1, U1.1
unnamed: R7.2, R8.1, R9.1, U1.19
unnamed: R9.2, R10.1, U1.17
unnamed: R10.2, R11.1, R12.1, U1.16
unnamed: R12.2, R13.1, R19.1, U1.14
unnamed: R13.2, R14.1, U1.13
unnamed: R15.1, U1.9, U2.2 (-)
unnamed: R1.2, R2.1, R3.1, R16.1, U1.6
unnamed: R15.2, R16.2, R17.1, U2.1
unnamed: R17.2, R18.1, U2.6 (-)
unnamed: R19.2, R20.1, U2.5 (+)
unnamed: R21.1, U1.12
unnamed: R22.2, U1.7 (EXPO_CTL), U1.8 (TEMPCO)

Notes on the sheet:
approx. [0, +2v]
approx. [+9v, -3v]


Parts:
C5: 100p; C_0805_2012Metric
D1: 3z3; D_SOD-123
D2, D3: 1N4148W; D_SOD-123
R23, R26, R29: 10k; R_0805_2012Metric
R24: 33k; R_0805_2012Metric
R25, R27: 200k; R_0805_2012Metric
R28: 1k; R_0805_2012Metric
RV1, RV2, RV3: 10k; Potentiometer_Bourns_3296W_Vertical
U3: TL072; SOIC-8_3.9x4.9mm_P1.27mm

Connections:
-12V: RV2.3; also elsewhere on the board
/CV_scalers/RAW_CUTOFF_CV_IN: RV1.3; also elsewhere on the board
/CV_scalers/RAW_FEEDBACK_CV_IN: RV3.3; also elsewhere on the board
/CV_scalers/SCALED_CUTOFF_CV_OUT: D1.2 (A), R28.2; also elsewhere on the board
/CV_scalers/SCALED_FEEDBACK_CV_OUT: D3.1 (K), U3.6 (-); also elsewhere on the board
GND: D2.2 (A), R23.2, R26.2, R29.2, U3.3 (+); also elsewhere on the board
unnamed: C5.1, R24.2, R25.2, R27.1, U3.2 (-)
unnamed: C5.2, R27.2, R28.1, U3.1
unnamed: D1.1 (K), D2.1 (K)
unnamed: D3.2 (A), U3.7
unnamed: R23.1, RV1.1
unnamed: R24.1, RV1.2
unnamed: R25.1, RV2.2
unnamed: R26.1, RV2.1
unnamed: R29.1, RV3.1
unnamed: RV3.2, U3.5 (+)

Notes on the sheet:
offset trim
depth trim
feedback trim


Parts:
C6, C7: 10u; CP_Radial_D6.3mm_P2.50mm
C8, C9, C10, C11, C12, C13: 100n; C_0805_2012Metric
U1: SSI2140; TSSOP-20_4.4x6.5mm_P0.65mm
U2, U3: TL072; SOIC-8_3.9x4.9mm_P1.27mm

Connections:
+12V: C6.1, C8.1, C10.1, C12.1, U1.20 (V+), U2.8 (V+), U3.8 (V+); also elsewhere on the board
-12V: C7.2, C9.2, C11.2, C13.2, U1.11 (V-), U2.4 (V-), U3.4 (V-); also elsewhere on the board
GND: C6.2, C7.1, C8.2, C9.1, C10.2, C11.1, C12.2, C13.1, U1.10 (GND); also elsewhere on the board



Board: 2 copper layers, 58.4 x 50.8 mm, 55 parts (4 on the bottom side), 38 nets.

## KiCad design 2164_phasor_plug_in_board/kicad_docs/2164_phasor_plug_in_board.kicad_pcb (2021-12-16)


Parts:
C1: 470p; C_0603_1608Metric
J1: signal_in; PinHeader_1x04_P2.54mm_Vertical
J2: CV_in; PinHeader_1x04_P2.54mm_Vertical
J3: signal_out; PinHeader_1x04_P2.54mm_Vertical
J4: feedback_CV_and_PS; PinHeader_1x08_P2.54mm_Vertical
R1, R2, R3: 30k; R_0603_1608Metric
R4: 12k; R_0603_1608Metric
U1, U5: TL074; TSSOP-14_4.4x5mm_P0.65mm

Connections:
+12V: J4.7, J4.8; also elsewhere on the board
-12V: J4.5, J4.6; also elsewhere on the board
/CV_scaler/raw_CV_in: J2.3, J2.4; also elsewhere on the board
/all_pass_stages/signal_v_in: C1.1, R2.1, U1.8; also elsewhere on the board
/feedback_VCA/feedback_CV_in: J4.3, J4.4; also elsewhere on the board
/feedback_VCA/feedback_signal_v_in: R4.2; also elsewhere on the board
/feedback_signal: C1.2, R1.1, R2.2, U1.9 (-); also elsewhere on the board
GND: J1.1, J1.2, J2.1, J2.2, J3.1, J3.2, J4.1, J4.2, U1.10 (+); also elsewhere on the board
unnamed: J1.3, J1.4, R1.2, R3.1
unnamed: J3.3, J3.4, U5.1, U5.2 (-)
unnamed: R3.2, R4.1, U5.3 (+)


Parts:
C2, C3, C4, C8, C9, C10: 1n2; C_0603_1608Metric
C5, C6, C7, C11, C12, C13: 220p; C_0805_2012Metric
C14: 470n; C_Rect_L7.2mm_W3.5mm_P5.00mm_FKS2_FKP2_MKS2_MKP2
R5, R6, R7, R11, R12, R13, R17, R18, R19, R23, R24, R25: 30k; R_0603_1608Metric
R8, R9, R10, R20, R21, R22: 220; R_0603_1608Metric
R14, R15, R16: 15k; R_0603_1608Metric
R26, R27, R29, R30, R32, R33: 10k; R_0603_1608Metric
R28, R31, R34, R35, R36, R37: 20k; R_0603_1608Metric
U1, U3, U5: TL074; TSSOP-14_4.4x5mm_P0.65mm
U2, U4: SSI2164; SOIC-16_3.9x9.9mm_P1.27mm

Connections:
/all_pass_stages/Vfc_in: U2.3, U2.6, U4.3, U4.6, U4.11, U4.14; also elsewhere on the board
/all_pass_stages/signal_v_in: R5.2, R17.2, R28.2; also elsewhere on the board
/feedback_VCA/feedback_signal_v_in: C14.1; also elsewhere on the board
GND: C2.2, C3.2, C4.2, C8.2, C9.2, C10.2, U1.3 (+), U1.5 (+), U3.3 (+), U3.5 (+), U3.10 (+), U3.12 (+), U5.5 (+), U5.10 (+), U5.12 (+); also elsewhere on the board
unnamed: C2.1, R8.2
unnamed: C3.1, R9.2
unnamed: C4.1, R10.2
unnamed: C5.1, R11.1, R14.2, R26.2, U1.7
unnamed: C5.2, U1.6 (-), U2.5
unnamed: C6.1, R12.1, R15.2, R29.2, U3.1
unnamed: C6.2, U3.2 (-), U4.5
unnamed: C7.1, R13.1, R16.2, R32.2, U5.8
unnamed: C7.2, U4.12, U5.9 (-)
unnamed: C8.1, R20.2
unnamed: C9.1, R21.2
unnamed: C10.1, R22.2
unnamed: C11.1, R23.1, R27.2, U1.1
unnamed: C11.2, U1.2 (-), U2.4
unnamed: C12.1, R24.1, R30.2, U3.8
unnamed: C12.2, U3.9 (-), U4.4
unnamed: C13.1, R25.1, R33.2, U5.14
unnamed: C13.2, U4.13, U5.13 (-)
unnamed: C14.2, R37.1, U5.7
unnamed: R7.1, R10.1, R13.2, U4.10
unnamed: R5.1, R8.1, R11.2, U2.7
unnamed: R6.1, R9.1, R12.2, U4.7
unnamed: R14.1, R17.1, R20.1, R23.2, U2.2
unnamed: R15.1, R18.1, R21.1, R24.2, U4.2
unnamed: R16.1, R19.1, R22.1, R25.2, U4.15
unnamed: R6.2, R18.2, R31.2, R35.1, U3.7
unnamed: R7.2, R19.2, R34.2, R36.1, U3.14
unnamed: R26.1, R27.1, R28.1, R35.2, U3.6 (-)
unnamed: R29.1, R30.1, R31.1, R36.2, U3.13 (-)
unnamed: R32.1, R33.1, R34.1, R37.2, U5.6 (-)


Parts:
C15, C16, C17: 1n2; C_0603_1608Metric
R38: 270k; R_0603_1608Metric
R39, R41: 220; R_0603_1608Metric
R40: 4k7; R_0603_1608Metric
R42: 30k; R_0603_1608Metric
R43: 51k; R_0603_1608Metric
RV3: 10k; Potentiometer_Bourns_3296W_Vertical
U2: SSI2164; SOIC-16_3.9x9.9mm_P1.27mm
U6: TL072; SOIC-8_3.9x4.9mm_P1.27mm

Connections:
-12V: R38.1; also elsewhere on the board
/feedback_VCA/feedback_CV_in: RV3.3; also elsewhere on the board
/feedback_VCA/feedback_signal_v_in: R42.2; also elsewhere on the board
/feedback_signal: U2.12; also elsewhere on the board
GND: C15.2, C16.2, RV3.1, U6.5 (+); also elsewhere on the board
unnamed: C15.1, R39.2
unnamed: C16.1, R41.2
unnamed: C17.1, R40.2, U6.7
unnamed: C17.2, R43.1, U2.13, U6.6 (-)
unnamed: R38.2, R39.1, U2.15
unnamed: R40.1, U2.11, U2.14
unnamed: R41.1, R42.1, U2.10
unnamed: R43.2, RV3.2


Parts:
C30: 100p; C_0603_1608Metric
D2, D3: 1N4148W; D_SOD-123
R44: 100k; R_0603_1608Metric
R45: 680k; R_0603_1608Metric
R46: 150k; R_0603_1608Metric
RV1, RV2: 10k; Potentiometer_Bourns_3296W_Vertical
U6: TL072; SOIC-8_3.9x4.9mm_P1.27mm

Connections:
-12V: RV2.1; also elsewhere on the board
/CV_scaler/raw_CV_in: RV1.3; also elsewhere on the board
/all_pass_stages/Vfc_in: C30.1, D3.1 (K), R46.1; also elsewhere on the board
GND: RV1.1, RV2.3, U6.3 (+); also elsewhere on the board
unnamed: C30.2, D2.2 (A), R44.1, R45.1, R46.2, U6.2 (-)
unnamed: D2.1 (K), D3.2 (A), U6.1
unnamed: R44.2, RV1.2
unnamed: R45.2, RV2.2

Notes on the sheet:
offset trim
depth trim


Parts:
C18, C19: 10u; C_0805_2012Metric
C20, C21, C22, C23, C24, C25, C26, C27, C28, C29: 100n; C_0603_1608Metric
D1: BAT48ZFILM; D_SOD-123
U1, U3, U5: TL074; TSSOP-14_4.4x5mm_P0.65mm
U2, U4: SSI2164; SOIC-16_3.9x9.9mm_P1.27mm
U6: TL072; SOIC-8_3.9x4.9mm_P1.27mm

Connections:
+12V: C18.1, C20.1, C22.1, C24.1, C26.1, C28.1, U1.4 (V+), U2.16 (V+), U3.4 (V+), U4.16 (V+), U5.4 (V+), U6.8 (V+); also elsewhere on the board
-12V: C19.2, C21.2, C23.2, C25.2, C27.2, C29.2, D1.2 (A), U1.11 (V-), U2.9 (V-), U3.11 (V-), U4.9 (V-), U5.11 (V-), U6.4 (V-); also elsewhere on the board
GND: C18.2, C19.1, C20.2, C21.1, C22.2, C23.1, C24.2, C25.1, C26.2, C27.1, C28.2, C29.1, D1.1 (K), U1.12 (+), U2.8 (gnd), U4.8 (gnd); also elsewhere on the board
unnamed: U1.13 (-), U1.14

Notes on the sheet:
2164 protection
unused


Board: 4 copper layers, 58.4 x 50.8 mm, 92 parts (0 on the bottom side), 55 nets.

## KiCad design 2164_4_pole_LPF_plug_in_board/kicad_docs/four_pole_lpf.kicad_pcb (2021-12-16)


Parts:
J1: signal_in; PinHeader_1x04_P2.54mm_Vertical
J2: CV_in; PinHeader_1x04_P2.54mm_Vertical
J3: signal_out; PinHeader_1x04_P2.54mm_Vertical
J4: feedback_CV_and_power; PinHeader_1x08_P2.54mm_Vertical

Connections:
+12V: J4.7, J4.8; also elsewhere on the board
-12V: J4.5, J4.6; also elsewhere on the board
/CV_scaler/raw_Vfc_in: J2.3, J2.4; also elsewhere on the board
/dry_signal: J1.3, J1.4; also elsewhere on the board
/feedback_VCA/4_pole_v_in: J3.3, J3.4; also elsewhere on the board
/feedback_VCA/feedback_CV_in: J4.3, J4.4; also elsewhere on the board
GND: J1.1, J1.2, J2.1, J2.2, J3.1, J3.2, J4.1, J4.2; also elsewhere on the board


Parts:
C1: 4n7; C_0603_1608Metric
C2, C4, C6, C8: 220pF; C_0805_2012Metric
C3, C5, C7: 1n5; C_0603_1608Metric
R1, R4, R5, R7, R8, R10, R11, R13: 15k; R_0603_1608Metric
R2: 3k3; R_0603_1608Metric
R3: 47R; R_0603_1608Metric
R6, R9, R12: 180; R_0603_1608Metric
U1: SSI2164; SOIC-16_3.9x9.9mm_P1.27mm
U2, U3: TL072; SOIC-8_3.9x4.9mm_P1.27mm

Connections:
/dry_signal: R1.2; also elsewhere on the board
/feedback_VCA/2_pole_v_in: C4.1, R7.1, R8.2, U3.1; also elsewhere on the board
/feedback_VCA/3_pole_v_in: C6.1, R10.1, R11.2, U2.7; also elsewhere on the board
/feedback_VCA/4_pole_v_in: C8.1, R13.1, U3.7; also elsewhere on the board
/low_pass_core/Vfc: U1.3, U1.6, U1.11, U1.14; also elsewhere on the board
/low_pass_core/feedback_signal_v_in: R2.2; also elsewhere on the board
GND: C1.1, C3.1, C5.1, C7.1, U2.3 (+), U2.5 (+), U3.3 (+), U3.5 (+); also elsewhere on the board
unnamed: C1.2, R3.1
unnamed: C2.1, R4.1, R5.2, U2.1
unnamed: C2.2, U1.5, U2.2 (-)
unnamed: C3.2, R6.1
unnamed: C4.2, U1.4, U3.2 (-)
unnamed: C5.2, R9.1
unnamed: C6.2, U1.12, U2.6 (-)
unnamed: C7.2, R12.1
unnamed: C8.2, U1.13, U3.6 (-)
unnamed: R1.1, R2.1, R3.2, R4.2, U1.7
unnamed: R5.1, R6.2, R7.2, U1.2
unnamed: R8.1, R9.2, R10.2, U1.10
unnamed: R11.1, R12.2, R13.2, U1.15


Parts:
C9, C13: opt; C_0805_2012Metric
C10, C12: 1n2; C_0603_1608Metric
C11: 3n3; C_0603_1608Metric
R14, R19, R21, R22, R23, R24, R25: 10k; R_0603_1608Metric
R15: 270k; R_0603_1608Metric
R16: 220; R_0603_1608Metric
R17: 4k7; R_0603_1608Metric
R18: 82R; R_0603_1608Metric
R20: 51k; R_0603_1608Metric
RV3: 50k; Potentiometer_Bourns_3296W_Vertical
U4, U6: TL072; SOIC-8_3.9x4.9mm_P1.27mm
U5: SSI2164; SOIC-16_3.9x9.9mm_P1.27mm

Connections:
-12V: R15.2; also elsewhere on the board
/feedback_VCA/2_pole_v_in: R22.2; also elsewhere on the board
/feedback_VCA/3_pole_v_in: R23.2, R24.2; also elsewhere on the board
/feedback_VCA/4_pole_v_in: R25.1; also elsewhere on the board
/feedback_VCA/feedback_CV_in: RV3.3; also elsewhere on the board
/low_pass_core/feedback_signal_v_in: C9.2, R14.1, U4.1; also elsewhere on the board
GND: C10.1, C11.1, RV3.1, U4.3 (+), U6.3 (+), U6.5 (+); also elsewhere on the board
unnamed: C9.1, R14.2, U4.2 (-), U5.4, U5.5, U5.13
unnamed: C10.2, R16.1
unnamed: C11.2, R18.1
unnamed: C12.1, R20.2, U5.12, U6.6 (-)
unnamed: C12.2, R17.1, U6.7
unnamed: C13.1, R21.2, R22.1, R23.1, R24.1, R25.2, U6.2 (-)
unnamed: C13.2, R19.1, R21.1, U6.1
unnamed: R15.1, R16.2, U5.10
unnamed: R17.2, U5.3, U5.6, U5.11, U5.14
unnamed: R18.2, R19.2, U5.2, U5.7, U5.15
unnamed: R20.1, RV3.2

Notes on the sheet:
The weighted sum of the lpf coefficients accomplishes "Q-compensation" which makes it so that increasing feedback does not result in passband attenuation. See AN701.
VCA sections in parallel for reduced noise


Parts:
C14: 100pF; C_0603_1608Metric
D1, D2: 1N4148W; D_SOD-123
R26: 100k; R_0603_1608Metric
R27: 680k; R_0603_1608Metric
R28: 150k; R_0603_1608Metric
RV1, RV2: 50k; Potentiometer_Bourns_3296W_Vertical
U4: TL072; SOIC-8_3.9x4.9mm_P1.27mm

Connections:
-12V: RV2.1; also elsewhere on the board
/CV_scaler/raw_Vfc_in: RV1.3; also elsewhere on the board
/low_pass_core/Vfc: C14.1, D2.1 (K), R28.1; also elsewhere on the board
GND: RV1.1, RV2.3, U4.5 (+); also elsewhere on the board
unnamed: C14.2, D1.2 (A), R26.1, R27.1, R28.2, U4.6 (-)
unnamed: D1.1 (K), D2.2 (A), U4.7
unnamed: R26.2, RV1.2
unnamed: R27.2, RV2.2

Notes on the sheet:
scale trim
offset trim


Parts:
C15, C16: 10uF; C_0805_2012Metric
C17, C18, C19, C20, C21, C22, C23, C24, C25, C26: 100nF; C_0603_1608Metric
D3: BAT48; D_SOD-123
U1, U5: SSI2164; SOIC-16_3.9x9.9mm_P1.27mm
U2, U3, U4, U6: TL072; SOIC-8_3.9x4.9mm_P1.27mm

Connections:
+12V: C15.1, C17.1, C19.1, C21.1, C23.1, C25.1, U1.16 (V+), U2.8 (V+), U3.8 (V+), U4.8 (V+), U5.16 (V+), U6.8 (V+); also elsewhere on the board
-12V: C16.2, C18.2, C20.2, C22.2, C24.2, C26.2, D3.2 (A), U1.9 (V-), U2.4 (V-), U3.4 (V-), U4.4 (V-), U5.9 (V-), U6.4 (V-); also elsewhere on the board
GND: C15.2, C16.1, C17.2, C18.1, C19.2, C20.1, C21.2, C22.1, C23.2, C24.1, C25.2, C26.1, D3.1 (K), U1.8 (gnd), U5.8 (gnd); also elsewhere on the board

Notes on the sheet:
optional 2164 protection diode


Board: 4 copper layers, 58.4 x 50.8 mm, 70 parts (0 on the bottom side), 39 nets.

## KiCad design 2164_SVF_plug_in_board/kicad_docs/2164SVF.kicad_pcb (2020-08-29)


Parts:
J1: signal_input; PinHeader_1x04_P2.54mm_Vertical
J2: cutoff_CV_input; PinHeader_1x04_P2.54mm_Vertical
J3: signal_output; PinHeader_1x04_P2.54mm_Vertical
J4: feedback_CV_and_PS; PinHeader_1x08_P2.54mm_Vertical
J5: mode_select_jumper; PinHeader_2x03_P2.54mm_Vertical

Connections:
+12V: J4.7, J4.8; also elsewhere on the board
-12V: J4.5, J4.6; also elsewhere on the board
/CV_path/FM_in: J2.3, J2.4; also elsewhere on the board
/CV_path/resonance_CV_in: J4.3, J4.4; also elsewhere on the board
/audio_path/band_pass_out: J5.3; also elsewhere on the board
/audio_path/filter_input: J1.3, J1.4; also elsewhere on the board
/audio_path/high_pass_out: J5.1; also elsewhere on the board
/audio_path/low_pass_out: J5.5; also elsewhere on the board
GND: J1.1, J1.2, J2.1, J2.2, J3.1, J3.2, J4.1, J4.2; also elsewhere on the board
unnamed: J3.3, J3.4, J5.2, J5.4, J5.6


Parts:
C1: 47pF; C_0805_2012Metric_Pad1.15x1.40mm_HandSolder
C2: 100pF; C_0805_2012Metric_Pad1.15x1.40mm_HandSolder
C3, C4, C7: 560pF; C_0805_2012Metric_Pad1.15x1.40mm_HandSolder
C6, C9: 220pF; timing_cap_dual_fp
D1, D2: 5z1; D_SOD-123
R4, R7, R8, R9, R10, R13, R14: 30k; R_0805_2012Metric_Pad1.15x1.40mm_HandSolder
R5: 150k; R_0805_2012Metric_Pad1.15x1.40mm_HandSolder
R6: 15k; R_0805_2012Metric_Pad1.15x1.40mm_HandSolder
R11, R12, R15: 510; R_0805_2012Metric_Pad1.15x1.40mm_HandSolder
U1, U3: TL072; SOIC-8_3.9x4.9mm_P1.27mm
U2: SSM2164; SOIC-16_3.9x9.9mm_P1.27mm

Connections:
/audio_path/Vfc_in: U2.3, U2.6; also elsewhere on the board
/audio_path/Vrez_in: U2.14; also elsewhere on the board
/audio_path/band_pass_out: C6.1, D2.1 (K), R5.1, R13.1, R14.2, U1.7; also elsewhere on the board
/audio_path/filter_input: R4.2; also elsewhere on the board
/audio_path/high_pass_out: R8.1, R10.2, U1.1; also elsewhere on the board
/audio_path/low_pass_out: C1.1, C9.1, R7.1, U3.7; also elsewhere on the board
GND: C3.2, C4.2, C7.2, U1.3 (+), U1.5 (+), U2.10, U3.3 (+), U3.5 (+); also elsewhere on the board
unnamed: C1.2, R4.1, R5.2, R6.2, R7.2, R8.2, U1.2 (-)
unnamed: C2.1, R9.1, U2.13, U3.2 (-)
unnamed: C2.2, R6.1, R9.2, U3.1
unnamed: C3.1, R11.1
unnamed: C4.1, R12.1
unnamed: C6.2, D1.1 (K), U1.6 (-), U2.4
unnamed: C7.1, R15.1
unnamed: C9.2, U2.5, U3.6 (-)
unnamed: D1.2 (A), D2.2 (A)
unnamed: R10.1, R11.2, U2.2
unnamed: R12.2, R13.2, U2.15
unnamed: R14.1, R15.2, U2.7

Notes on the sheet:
unused


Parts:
C11: 100pF; C_0805_2012Metric_Pad1.15x1.40mm_HandSolder
D3, D4: 1N4148W; D_SOD-123
D5: BAT48; D_SOD-123
R16: 20k; R_0805_2012Metric_Pad1.15x1.40mm_HandSolder
R18: 68k; R_0805_2012Metric_Pad1.15x1.40mm_HandSolder
R19: 22k; R_0805_2012Metric_Pad1.15x1.40mm_HandSolder
RV1, RV2, RV3: 10k; Potentiometer_Bourns_3296W_Vertical
U4: TL072; SOIC-8_3.9x4.9mm_P1.27mm

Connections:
-12V: RV2.1; also elsewhere on the board
/CV_path/FM_in: RV1.3; also elsewhere on the board
/CV_path/resonance_CV_in: RV3.3; also elsewhere on the board
/audio_path/Vfc_in: C11.1, D4.1 (K), R19.1; also elsewhere on the board
/audio_path/Vrez_in: D5.1 (K); also elsewhere on the board
GND: RV1.1, RV2.3, RV3.1, U4.3 (+); also elsewhere on the board
unnamed: C11.2, D3.2 (A), R16.1, R18.1, R19.2, U4.2 (-)
unnamed: D3.1 (K), D4.2 (A), U4.1
unnamed: D5.2 (A), U4.6 (-), U4.7
unnamed: R16.2, RV1.2
unnamed: R18.2, RV2.2
unnamed: RV3.2, U4.5 (+)

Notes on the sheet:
offset trim
feedback trim
Cutoff frequency CV scaler
Resonance CV scaler
approximately 0 volts to +1 volts
approximately +2 volts to 0 volts
depth trim


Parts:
C14, C15: 10uF; CP_Elec_6.3x5.4_Nichicon
C17, C18, C19, C20, C21, C22, C24, C25: 100nF; C_0805_2012Metric_Pad1.15x1.40mm_HandSolder
D6: BAT48; D_SOD-123
R25: opt; R_0805_2012Metric_Pad1.15x1.40mm_HandSolder
U1, U3, U4: TL072; SOIC-8_3.9x4.9mm_P1.27mm
U2: SSM2164; SOIC-16_3.9x9.9mm_P1.27mm

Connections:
+12V: C14.1, C17.1, C19.1, C21.1, C24.1, R25.1, U1.8 (V+), U2.16 (V+), U3.8 (V+), U4.8 (V+); also elsewhere on the board
-12V: C15.2, C18.2, C20.2, C22.2, C25.2, D6.2 (A), U1.4 (V-), U2.9 (V-), U3.4 (V-), U4.4 (V-); also elsewhere on the board
GND: C14.2, C15.1, C17.2, C18.1, C19.2, C20.1, C21.2, C22.1, C24.2, C25.1, D6.1 (K), U2.8 (gnd); also elsewhere on the board
unnamed: R25.2, U2.1 (mode)

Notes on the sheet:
2164 protection
optional class A/AB mode resistor
TL072 power connections
SSM2164 power connections
Decoupling capacitors



Board: 2 copper layers, 58.4 x 50.8 mm, 52 parts (4 on the bottom side), 31 nets.

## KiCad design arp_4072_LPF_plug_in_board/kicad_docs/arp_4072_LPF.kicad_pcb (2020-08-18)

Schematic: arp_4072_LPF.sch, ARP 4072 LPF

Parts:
J1: signal_in; PinHeader_1x04_P2.54mm_Vertical
J2: CV_in; PinHeader_1x04_P2.54mm_Vertical
J3: signal_out; PinHeader_1x04_P2.54mm_Vertical
J4: feedback_CV_and_power; PinHeader_1x08_P2.54mm_Vertical

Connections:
+12V: J4.7, J4.8; also elsewhere on the board
-12V: J4.5, J4.6; also elsewhere on the board
/CV_scaler/raw_Vfc_in: J2.3, J2.4; also elsewhere on the board
/dry_signal: J1.3, J1.4; also elsewhere on the board
/feedback_VCA/feedback_CV_in: J4.3, J4.4; also elsewhere on the board
/low_pass_core/4_pole_v_out: J3.3, J3.4; also elsewhere on the board
GND: J1.1, J1.2, J2.1, J2.2, J3.1, J3.2, J4.1, J4.2; also elsewhere on the board

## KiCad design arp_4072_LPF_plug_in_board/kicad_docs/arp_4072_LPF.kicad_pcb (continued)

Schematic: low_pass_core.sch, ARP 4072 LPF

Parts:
C1: 100nF; C_0805_2012Metric_Pad1.15x1.40mm_HandSolder
C2, C3, C4, C5: 470pF; C_0805_2012Metric_Pad1.15x1.40mm_HandSolder
C6: 10uF; CP_Radial_D6.3mm_P2.50mm
Q1, Q2, Q3, Q4, Q5, Q6: BCM857DS; SOT457
R1, R4, R10, R13, R17, R19, R21, R23, R26, R28, R30: 10k; R_0805_2012Metric_Pad1.15x1.40mm_HandSolder
R2, R14: 100k; R_0805_2012Metric_Pad1.15x1.40mm_HandSolder
R3, R6, R7, R11, R12, R18, R20, R24, R25, R29: 220; R_0805_2012Metric_Pad1.15x1.40mm_HandSolder
R5: 33k; R_0805_2012Metric_Pad1.15x1.40mm_HandSolder
R8: 68k; R_0805_2012Metric_Pad1.15x1.40mm_HandSolder
R9, R15, R22, R27: 1k; R_0805_2012Metric_Pad1.15x1.40mm_HandSolder
R16: 2k2; R_0805_2012Metric_Pad1.15x1.40mm_HandSolder
R31: 82k; R_0805_2012Metric_Pad1.15x1.40mm_HandSolder
U1: LM3900; SOIC-14_3.9x8.7mm_P1.27mm
U2, U3: TL072; SOIC-8_3.9x4.9mm_P1.27mm

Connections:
+12V: R5.1, R19.1; also elsewhere on the board
-12V: R4.2; also elsewhere on the board
/dry_signal: R2.2; also elsewhere on the board
/low_pass_core/4_pole_v_out: R31.1, U2.1; also elsewhere on the board
/low_pass_core/Vfc_in: R14.2; also elsewhere on the board
/low_pass_core/feedback_signal_v_in: R8.1; also elsewhere on the board
/low_pass_core/v_bias: R6.2, R11.2, R12.2, R18.2, R20.2, R24.2, R25.2, R29.2, U3.6 (-), U3.7
GND: C1.2, Q4.5 (B), Q4.6 (C), R1.1, R3.2, R7.2, R16.2, U2.3 (+); also elsewhere on the board
unnamed: C1.1, R1.2, R4.1, U3.5 (+)
unnamed: C2.1, R10.1, R13.2, U1.5 (1OUT)
unnamed: C2.2, Q2.3 (C), U1.6 (1IN-)
unnamed: C3.1, R17.1, R21.2, U1.4 (2OUT)
unnamed: C3.2, Q3.3 (C), U1.3 (2IN-)
unnamed: C4.1, R23.1, R26.2, U1.9 (3OUT)
unnamed: C4.2, Q5.3 (C), U1.8 (3IN-)
unnamed: C5.1, C6.2, R28.1, U1.10 (4OUT)
unnamed: C5.2, Q6.6 (C), U1.11 (4IN-)
unnamed: C6.1, R30.2
unnamed: Q1.1 (E), Q1.4 (E), R5.2
unnamed: Q1.2 (B), R2.1, R3.1
unnamed: Q1.3 (C), Q2.5 (B), R11.1
unnamed: Q1.5 (B), R7.1, R8.2
unnamed: Q1.6 (C), Q2.2 (B), R6.1, R10.2
unnamed: Q2.1 (E), Q2.4 (E), R9.2
unnamed: Q2.6 (C), U1.1 (1IN+)
unnamed: Q3.1 (E), Q3.4 (E), R15.2
unnamed: Q3.2 (B), R12.1, R13.1, R17.2
unnamed: Q3.5 (B), R18.1
unnamed: Q3.6 (C), U1.2 (2IN+)
unnamed: Q4.1 (E), Q4.4 (E), R19.2
unnamed: Q4.2 (B), R14.1, R16.1
unnamed: Q4.3 (C), R9.1, R15.1, R22.1, R27.1
unnamed: Q5.1 (E), Q5.4 (E), R22.2
unnamed: Q5.2 (B), R20.1, R21.1, R23.2
unnamed: Q5.5 (B), R24.1
unnamed: Q5.6 (C), U1.13 (3IN+)
unnamed: Q6.1 (E), Q6.4 (E), R27.2
unnamed: Q6.2 (B), R29.1
unnamed: Q6.3 (C), U1.12 (4IN+)
unnamed: Q6.5 (B), R25.1, R26.1, R28.2
unnamed: R30.1, R31.2, U2.2 (-)

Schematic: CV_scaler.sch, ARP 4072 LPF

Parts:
C7: 100nF; C_0805_2012Metric_Pad1.15x1.40mm_HandSolder
C8: 100pF; C_0805_2012Metric_Pad1.15x1.40mm_HandSolder
R32: 120k; R_0805_2012Metric_Pad1.15x1.40mm_HandSolder
R33: 20k; R_0805_2012Metric_Pad1.15x1.40mm_HandSolder
R34: 100k; R_0805_2012Metric_Pad1.15x1.40mm_HandSolder
RV1: 10k; Potentiometer_Bourns_3296W_Vertical
RV2: 100k; Potentiometer_Bourns_3296W_Vertical
U3: TL072; SOIC-8_3.9x4.9mm_P1.27mm

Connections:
+12V: RV2.1; also elsewhere on the board
/CV_scaler/raw_Vfc_in: RV1.3; also elsewhere on the board
/low_pass_core/Vfc_in: C8.1, R34.1, U3.1; also elsewhere on the board
GND: C7.1, R33.2, RV1.1, RV2.3; also elsewhere on the board
unnamed: C7.2, R32.2, RV2.2
unnamed: C8.2, R32.1, R33.1, R34.2, U3.2 (-)
unnamed: RV1.2, U3.3 (+)

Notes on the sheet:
scale trim
offset trim

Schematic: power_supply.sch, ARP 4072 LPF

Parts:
C9, C10: 10uF; C_0805_2012Metric_Pad1.15x1.40mm_HandSolder
C11, C12, C13, C14, C15: 100nF; C_0805_2012Metric_Pad1.15x1.40mm_HandSolder
U1: LM3900; SOIC-14_3.9x8.7mm_P1.27mm
U2, U3: TL072; SOIC-8_3.9x4.9mm_P1.27mm

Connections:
+12V: C9.1, C11.1, C13.1, U2.8 (V+), U3.8 (V+); also elsewhere on the board
-12V: C10.2, C12.2, C14.2, C15.2, U1.7 (GND), U2.4 (V-), U3.4 (V-); also elsewhere on the board
GND: C9.2, C10.1, C11.2, C12.1, C13.2, C14.1, C15.1, U1.14 (Vcc); also elsewhere on the board

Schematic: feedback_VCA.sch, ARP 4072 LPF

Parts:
D1: MMSZ5225B; D_SOD-123
Q7: BCM847DS135; SOT457
Q8, Q9: MMBT3904; SOT-23_Handsoldering
Q10: MMBT3906; SOT-23_Handsoldering
R35, R36: 220k; R_0805_2012Metric_Pad1.15x1.40mm_HandSolder
R37: 39k; R_0805_2012Metric_Pad1.15x1.40mm_HandSolder
R38, R41: 220; R_0805_2012Metric_Pad1.15x1.40mm_HandSolder
R39, R40: 47k; R_0805_2012Metric_Pad1.15x1.40mm_HandSolder
R42: 33k; R_0805_2012Metric_Pad1.15x1.40mm_HandSolder
R43: 680k; R_0805_2012Metric_Pad1.15x1.40mm_HandSolder
R44: 7k5; R_0805_2012Metric_Pad1.15x1.40mm_HandSolder
RV3: 50k; Potentiometer_Bourns_3296W_Vertical
U2: TL072; SOIC-8_3.9x4.9mm_P1.27mm

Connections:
+12V: R39.2, R40.2, R43.2; also elsewhere on the board
-12V: Q8.2 (E), Q9.2 (E); also elsewhere on the board
/dry_signal: R37.2; also elsewhere on the board
/feedback_VCA/feedback_CV_in: R44.1; also elsewhere on the board
/low_pass_core/4_pole_v_out: R42.1; also elsewhere on the board
/low_pass_core/feedback_signal_v_in: R35.2, U2.7; also elsewhere on the board
GND: D1.2 (A), Q10.1 (B), R36.1, R38.1, R41.1; also elsewhere on the board
unnamed: D1.1 (K), R44.2, RV3.3
unnamed: Q7.1 (E), Q7.4 (E), Q8.3 (C)
unnamed: Q7.2 (B), R41.2, R42.2
unnamed: Q7.3 (C), R36.2, R39.1, U2.5 (+)
unnamed: Q7.5 (B), R37.1, R38.2
unnamed: Q7.6 (C), R35.1, R40.1, U2.6 (-)
unnamed: Q10.2 (E), R43.1, RV3.1, RV3.2
unnamed: Q8.1 (B), Q9.1 (B), Q9.3 (C), Q10.3 (C)

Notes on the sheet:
The zener "bends" the feedback CV to approximate a log response. Do not fit if this is not desired.
feedback trim
Applying the dry signal to the feedback VCA provides "Q compensation", which lessens the passband gain loss when the feedback is turned up. R37 sets the amount of compensation. You can experiment with different amounts, or not install the resistor at all to get the classic no-compensation sound.



Board: 2 copper layers, 58.4 x 50.8 mm, 80 parts (4 on the bottom side), 54 nets.

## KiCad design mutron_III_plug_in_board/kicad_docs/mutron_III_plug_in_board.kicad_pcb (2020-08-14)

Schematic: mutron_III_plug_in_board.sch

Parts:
J1: signal_in; PinHeader_1x04_P2.54mm_Vertical
J2: cutoff_CV_in; PinHeader_1x04_P2.54mm_Vertical
J3: signal_out; PinHeader_1x04_P2.54mm_Vertical
J4: feedback_CV_in_and_PS; PinHeader_1x08_P2.54mm_Vertical
J5: mode_select_jumper; PinHeader_2x03_P2.54mm_Vertical
R1: 51k; R_0805_2012Metric_Pad1.15x1.40mm_HandSolder
R2: 100k; R_0805_2012Metric_Pad1.15x1.40mm_HandSolder
U2: RC4558; SOIC-8_3.9x4.9mm_P1.27mm

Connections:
+12V: J4.7, J4.8; also elsewhere on the board
-12V: J4.5, J4.6; also elsewhere on the board
/CV_scaler/raw_CV_in: J2.3, J2.4; also elsewhere on the board
/feedback_VCA/band_pass_FB_in: U2.5 (+); also elsewhere on the board
/feedback_VCA/feedback_CV_in: J4.3, J4.4; also elsewhere on the board
/filter_core/high_pass_out: J5.5; also elsewhere on the board
/filter_core/low_pass_out: J5.1; also elsewhere on the board
/filter_core/signal_v_in: J1.3, J1.4; also elsewhere on the board
GND: J1.1, J1.2, J2.1, J2.2, J3.1, J3.2, J4.1, J4.2, R1.1; also elsewhere on the board
unnamed: J3.3, J3.4, J5.2, J5.4, J5.6
unnamed: J5.3, R2.1, U2.7
unnamed: R1.2, R2.2, U2.6 (-)

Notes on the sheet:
frequency CV in: 0V to +2.048V
freedback CV in: 0V to +2.048V
band pass makeup gain

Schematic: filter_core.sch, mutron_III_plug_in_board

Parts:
C1, C2: 47nF; C_Rect_L7.0mm_W3.5mm_P5.00mm
R3, R4: 10k; R_0805_2012Metric_Pad1.15x1.40mm_HandSolder
R5, R6: 22k; R_0805_2012Metric_Pad1.15x1.40mm_HandSolder
R7, R8: 680k; R_0805_2012Metric_Pad1.15x1.40mm_HandSolder
U1, U2: RC4558; SOIC-8_3.9x4.9mm_P1.27mm
U4, U5: vactrol; vactrol_dual_footprint

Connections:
-12V: U4.1 (-); also elsewhere on the board
/feedback_VCA/band_pass_FB_in: C1.1, R8.2, U1.7, U5.3; also elsewhere on the board
/feedback_VCA/band_pass_FB_out: R4.2; also elsewhere on the board
/filter_core/LED_I_in: U5.2 (+); also elsewhere on the board
/filter_core/high_pass_out: R6.1, R7.2, U1.1, U4.3; also elsewhere on the board
/filter_core/low_pass_out: C2.1, R5.1, U2.1; also elsewhere on the board
/filter_core/signal_v_in: R3.2; also elsewhere on the board
GND: U1.5 (+), U2.3 (+); also elsewhere on the board
unnamed: C1.2, R7.1, U1.6 (-), U4.4
unnamed: C2.2, R8.1, U2.2 (-), U5.4
unnamed: R3.1, R4.1, U1.3 (+)
unnamed: R5.2, R6.2, U1.2 (-)
unnamed: U4.2 (+), U5.1 (-)

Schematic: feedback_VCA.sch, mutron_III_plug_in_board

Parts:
D1: MMSZ5225B; D_SOD-123
Q1: BCM847; SOT457
Q2: MMBT3904; SOT-23_Handsoldering
R9, R10, R18: 220k; R_0805_2012Metric_Pad1.15x1.40mm_HandSolder
R11, R16: 220; R_0805_2012Metric_Pad1.15x1.40mm_HandSolder
R12, R15: 47k; R_0805_2012Metric_Pad1.15x1.40mm_HandSolder
R13, R14: 15k; R_0805_2012Metric_Pad1.15x1.40mm_HandSolder
R17: 33k; R_0805_2012Metric_Pad1.15x1.40mm_HandSolder
R19: 7k5; R_0805_2012Metric_Pad1.15x1.40mm_HandSolder
RV3: 100k; Potentiometer_Bourns_3296W_Vertical
U3: TL072; SOIC-8_3.9x4.9mm_P1.27mm

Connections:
+12V: R12.2, R15.2; also elsewhere on the board
-12V: R14.1, R18.2; also elsewhere on the board
/feedback_VCA/band_pass_FB_in: R17.2; also elsewhere on the board
/feedback_VCA/band_pass_FB_out: R9.1, U3.7; also elsewhere on the board
/feedback_VCA/feedback_CV_in: R19.1; also elsewhere on the board
GND: D1.2 (A), Q2.3 (C), R10.1, R11.1, R16.1; also elsewhere on the board
unnamed: D1.1 (K), R19.2, RV3.1, RV3.2
unnamed: Q1.1 (E), Q1.4 (E), R13.2
unnamed: Q1.2 (B), R11.2
unnamed: Q1.3 (C), R9.2, R15.1, U3.6 (-)
unnamed: Q1.5 (B), R16.2, R17.1
unnamed: Q1.6 (C), R10.2, R12.1, U3.5 (+)
unnamed: Q2.1 (B), R18.1, RV3.3
unnamed: Q2.2 (E), R13.1, R14.2

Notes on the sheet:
freedback CV in: 0V to +2.048V
feedback trim
The zener bends the feedback CV signal to approximate a reverse log response. You can experiment with different zeners, or leave this off completely.

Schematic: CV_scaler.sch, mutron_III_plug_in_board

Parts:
C3: 100pF; C_0805_2012Metric_Pad1.15x1.40mm_HandSolder
D2: 1N914; D_SOD-123
Q3: MMBT3906; SOT-23_Handsoldering
R20, R22: 100k; R_0805_2012Metric_Pad1.15x1.40mm_HandSolder
R21: 1M; R_0805_2012Metric_Pad1.15x1.40mm_HandSolder
R23: 10k; R_0805_2012Metric_Pad1.15x1.40mm_HandSolder
R24: 100; R_0805_2012Metric_Pad1.15x1.40mm_HandSolder
RV1: 10k; Potentiometer_Bourns_3296W_Vertical
RV2: 100k; Potentiometer_Bourns_3296W_Vertical
U3: TL072; SOIC-8_3.9x4.9mm_P1.27mm

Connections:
+12V: RV2.3; also elsewhere on the board
-12V: RV2.1; also elsewhere on the board
/CV_scaler/raw_CV_in: RV1.3; also elsewhere on the board
/filter_core/LED_I_in: Q3.3 (C); also elsewhere on the board
GND: R24.1, RV1.1, U3.3 (+); also elsewhere on the board
unnamed: C3.1, R22.1, R23.2, U3.1
unnamed: C3.2, R20.1, R21.1, R22.2, U3.2 (-)
unnamed: D2.1 (K), Q3.2 (E), R24.2
unnamed: D2.2 (A), Q3.1 (B), R23.1
unnamed: R20.2, RV1.2
unnamed: R21.2, RV2.2

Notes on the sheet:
0mA to 20mA flows through the vactrols
depth trim
offset trim
frequency CV in: 0V to +2.048V

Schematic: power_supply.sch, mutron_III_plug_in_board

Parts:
C4, C5, C6, C7, C8, C9: 100nF; C_0805_2012Metric_Pad1.15x1.40mm_HandSolder
U1, U2: RC4558; SOIC-8_3.9x4.9mm_P1.27mm
U3: TL072; SOIC-8_3.9x4.9mm_P1.27mm

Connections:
+12V: C4.1, C6.1, C8.1, U1.8 (V+), U2.8 (V+), U3.8 (V+); also elsewhere on the board
-12V: C5.2, C7.2, C9.2, U1.4 (V-), U2.4 (V-), U3.4 (V-); also elsewhere on the board
GND: C4.2, C5.1, C6.2, C7.1, C8.2, C9.1; also elsewhere on the board


Board: 2 copper layers, 58.4 x 50.8 mm, 51 parts (4 on the bottom side), 33 nets.

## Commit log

2020-08-01 remove erroneous check for 2164LPF pcb layout
2020-08-01 clean up CEM3320 LPF, add smd cap footprints for timing caps
    [CEM3320_LPF_plug_in_board-B_Cu.gbr, CEM3320_LPF_plug_in_board-B_Mask.gbr, CEM3320_LPF_plug_in_board-B_Paste.gbr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]
2020-08-01 update mutron-III pcb
    [CV_scaler.sch, feedback_VCA.sch, filter_core.sch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]
2020-08-02 generate schematic
2020-08-02 generate BOM
2020-08-02 generate gerbers
    [mutron_III_plug_in_board-B_Cu.gbr, mutron_III_plug_in_board-B_Mask.gbr, mutron_III_plug_in_board-B_Paste.gbr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]
2020-08-02 swap j2 and j1 positions for consistency
    [CEM3320_LPF_plug_in_board.kicad_pcb, CEM3320_LPF_plug_in_board.sch]
2020-08-02 regenerate gerbers after j1/j2 swap
    [CEM3320_LPF_plug_in_board-B_Cu.gbr, CEM3320_LPF_plug_in_board-B_Mask.gbr, CEM3320_LPF_plug_in_board-B_Paste.gbr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]
2020-08-02 generate minimoog VCF gerbers
    [minimoog_LPF-B_Cu.gbr, minimoog_LPF-B_Mask.gbr, minimoog_LPF-B_Paste.gbr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]
2020-08-02 add missing designator to schematic note
    [feedback_VCA.sch]
2020-08-04 add links to boards in readme status section
2020-08-10 add template for starting new projects
    [plug_in_board_template.kicad_pcb, plug_in_board_template.sch]
2020-08-13 change zener value
    [arp_4072_LPF.kicad_pcb, feedback_VCA.sch]
2020-08-13 fix schemo and pcb problems
    [CV_scaler.sch, arp_4072_LPF.kicad_pcb, arp_4072_LPF.sch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]
2020-08-14 add calibration instructions to main readme
2020-08-14 move calibration to top level readme
2020-08-14 change zener
    [feedback_VCA.sch, mutron_III_plug_in_board.kicad_pcb]
2020-08-17 progress on SSI2164 LPF
    [CV_scaler.sch, feedback_VCA.sch, four_pole_lpf.kicad_pcb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]
2020-08-18 flip trimpots to be consistent with other boards
    [arp_4072_LPF-B_Cu.gbr, arp_4072_LPF-B_Mask.gbr, arp_4072_LPF-B_Paste.gbr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]
2020-08-18 flip trimpots for consistency
    [feedback_VCA.sch, four_pole_lpf.kicad_pcb]
2020-08-18 add 2164 SVF board
    [2164SVF-B_Cu.gbr, 2164SVF-B_Mask.gbr, 2164SVF-B_Paste.gbr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]
2020-08-18 move BOM to correct location
2020-08-19 zip gerbers
2020-08-19 add late MS20 stlye VCF board
2020-08-19 add MS20 VCF files
    [CV_scalers.sch, feedback_VCA.sch, filter_core.sch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]
2020-08-28 change Fcv offset trim resistor
    [2164SVF.kicad_pcb, CV_path.sch]
2020-08-29 change 2164 SVF zeners
    [2164SVF.kicad_pcb, audio_path.sch]
2020-08-29 change late MS20 CV scaling
    [CV_scalers.sch, late_MS20_VCF_plug_in_board.kicad_pcb]
2021-12-16 update 2164 LPF, better feedback VCA
    [CV_scaler.sch, feedback_VCA.sch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]
2021-12-16 update 2164 phasor board
2022-05-29 Add SSI2140 LPF board
2022-05-29 Add rest of SSI2140 LPF files
    [CV_scalers.kicad_sch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]
2022-08-19 Update minimoog PPF, better feedback VCA, better docs
    [BOM-minimoog_LPF.csv, CV_scaler.sch, feedback_VCA.kicad_sch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]
2022-08-19 Update late MS20 VCF, better feedback VCA, better docs
    [BOM-late_MS20_VCF_plug_in_board.csv, CV_scalers.kicad_sch, CV_scalers.sch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]

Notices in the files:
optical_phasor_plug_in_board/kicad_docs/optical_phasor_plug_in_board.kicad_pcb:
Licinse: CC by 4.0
